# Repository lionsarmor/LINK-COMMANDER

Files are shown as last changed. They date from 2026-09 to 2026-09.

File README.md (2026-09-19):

# LINK COMMANDER — Rev D

**Buy the breadboard parts:** [Amazon checklist + ASINs](SHOPPING-AMAZON.md) · [Mouser checklist + SKUs](SHOPPING-MOUSER.md) · [Amazon order CSV](SHOPPING-AMAZON-ORDER.csv) · [Full Mouser CSV](SHOPPING-MOUSER-ORDER.csv) · [Keyboard-only Mouser CSV](SHOPPING-MOUSER-KEYBOARD.csv). Choose one checklist; do not buy both. Each covers the build and explicitly identifies outside-store exceptions. Skip parts already owned.

**Five finished PCB builds:** [Full Mouser PO (PDF)](MOUSER-PO-01-FIVE-PCBS.pdf) · [Full PO CSV](MOUSER-PO-01-FIVE-PCBS.csv) · [Chips-only PO (PDF)](MOUSER-PO-02-CHIPS-ONLY.pdf) · [Chips-only CSV](MOUSER-PO-02-CHIPS-ONLY.csv). Plain supplier parts tables; not submitted. Full order needs five modules and five fabricated PCBs supplied separately.

A through-hole USB keyboard and mouse adapter for the **Commander X16**.
The RP2040-Zero translates supported wired devices or 2.4 GHz USB receivers
into PS/2 keyboard and mouse signals. Rev D removes all gamepad support.

**Two USB inputs. Two PCB-mounted 7-pin DIN outputs. Two socketed DIP chips.**
The RP2040-Zero plugs into removable headers; every other carrier part is
through-hole. No USB hub or onboard radio is required.

A separate regulated **5 V / 2 A supply** powers the module and USB ports.
The X16 PS/2 +5 V lines supply only their signal pull-ups.

**Start breadboarding:** [Wiring instructions and parts list](BREADBOARD.md) ·
[Parts CSV](BREADBOARD-PARTS.csv) · [Complete wiring CSV](BREADBOARD-WIRING.csv)

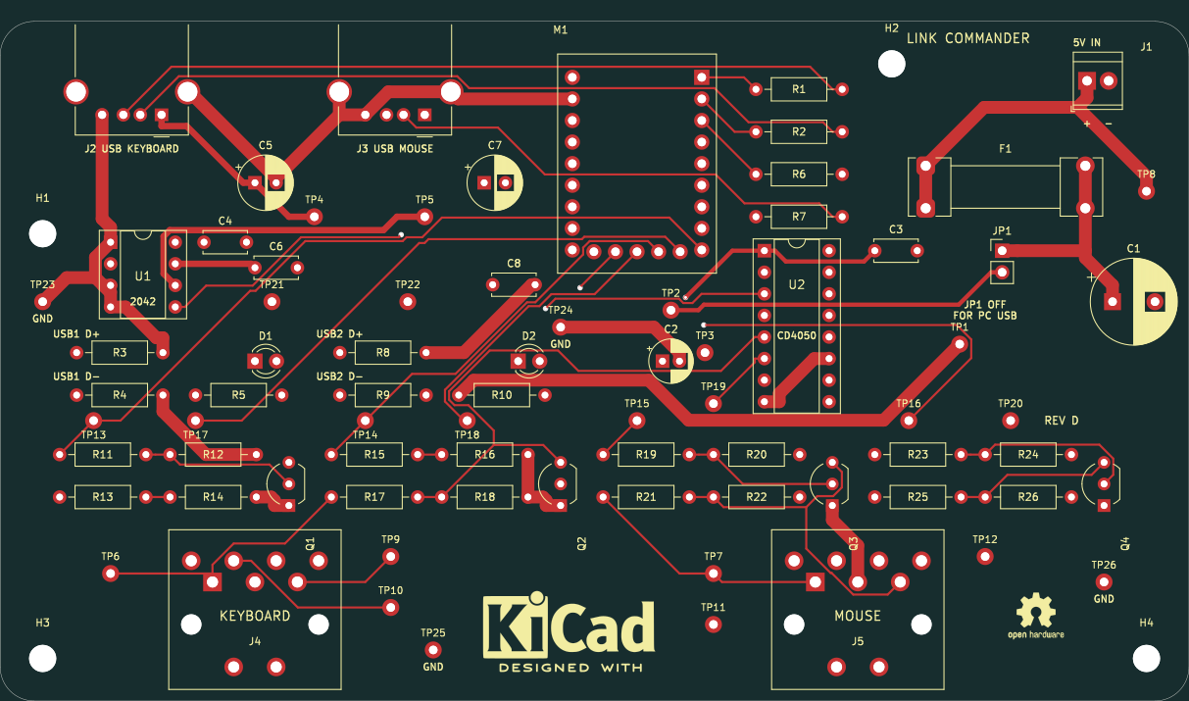
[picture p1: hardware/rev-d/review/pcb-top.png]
Rev D PCB preview


- [Exploratory PS/2 simulation and its limits](hardware/rev-d/simulation/README.md)
- [Test points and expected readings](hardware/rev-d/test-points.md)
- [Student guide: how it works](hardware/rev-d/student-guide.md)
- [One-page schematic PDF](hardware/rev-d/review/schematic.pdf)
- [Assembly PDF](hardware/rev-d/review/assembly.pdf)
- [Editable KiCad project](hardware/rev-d/kicad/link-commander.kicad_pro)
- [Complete Rev D review ZIP](hardware/link-commander-rev-d-review.zip)
- [Breadboard guide and custom cables](BREADBOARD.md)
- [Pin-by-pin wiring table](hardware/rev-d/breadboard-wiring.csv)
- [Grouped BOM](hardware/rev-d/bom-grouped.csv) and [purchasing notes](hardware/rev-d/parts.md)
- [Design details and validation status](hardware/rev-d/README.md)
- [Firmware requirements](hardware/rev-d/firmware-contract.md)

The rounded **140 × 80 mm, two-layer PCB** retains 50 electrical parts
and four mounting holes, and now adds **26 labeled through-hole test pads**.
The student schematic shows seven circuit sections plus a test-point section,
physical pin numbers and connected wires.

**Engineering prototype:** CAD checks pass, but firmware, physical fit,
receiver compatibility and electrical operation still require testing.
No working bridge firmware or fabrication release is included yet. Start
with the standalone keyboard breadboard before connecting the X16.

Rev D uses **non-inverted PS/2 sense signals** and new component reference
numbers. Use only its wiring tables. Remove JP1 before connecting the
module's USB-C to a computer.

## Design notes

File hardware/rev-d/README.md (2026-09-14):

# LINK COMMANDER — Rev D

Rev D translates supported **USB keyboards and mice** into the PS/2
keyboard and mouse interfaces used by the Commander X16. Wired peripherals
and manufacturers' 2.4 GHz USB receivers use the same two USB input ports.
Gamepad support has been removed from this revision.

The RP2040-Zero plugs into removable headers. Every other carrier component
is through-hole. There are **two socketed DIP chips and four transistors**.
The board is **140 × 80 mm**, has **two copper layers** and 4 mm corner radii,
and retains the KiCad/open-hardware logos.

The board and USB receivers use a separate regulated **5 V / 2 A supply**.
The X16 PS/2 +5 V pins supply only their signal pull-ups; they do not power
the RP2040 or USB ports. All grounds are shared.

## Start here

- [Exploratory PS/2 simulation and its limits](simulation/README.md)
- [Test-point map and expected readings](test-points.md) and [probe CSV](test-points.csv)
- [Student design guide: how the circuit works](student-guide.md)
- [One-page schematic PDF](review/schematic.pdf)
- [Assembly PDF](review/assembly.pdf) and [PCB preview](review/pcb-top.png)
- [Editable KiCad project](kicad/link-commander.kicad_pro)
- [Breadboard guide and custom cable table](breadboard.md)
- [Every physical pin](breadboard-wiring.csv) and [connections grouped by net](net-connections.csv)
- [Grouped BOM](bom-grouped.csv), [individual BOM](bom.csv), [purchasing notes](parts.md)
- [Firmware interface and test requirements](firmware-contract.md)
- [Validation reports](review/design-checks.txt), [PCB DRC](review/pcb-drc.txt)
- [Rebuild instructions](tools/README.md)

## What changed from Rev C

| | Rev C | Rev D |
|---|---:|---:|
| USB inputs | 4 | 2: keyboard and mouse |
| DIN outputs | 4 | 2: PS/2 keyboard and mouse |
| Socketed DIP ICs | 17 | 2 |
| Transistors | 7 | 4 |
| Circuit parts plus mounting holes | 143 | 54 |
| Additional bare test holes | — | 26 |
| Board | 230 × 130 mm, four layers | 140 × 80 mm, two layers |

The gamepad shift registers, resistor networks and control gates are gone.
One TPS2042P replaces the two individual USB power chips. One CD4050 handles all four PS/2 sense lines. The separate HC14 inverter
stage and four input/output series-resistor pairs have been removed. Both
channels of the USB power chip are enabled directly by ground, so no shared enable
transistor or RUN_ENABLE GPIO is required. Port fault LEDs remain useful
for students during bring-up.

**Rev D sense signals are non-inverting:** HIGH means the cable line is
HIGH. The old Rev C firmware assumptions and component reference numbers
must not be reused without updating them. PS/2 drive HIGH still pulls LOW.

The DIN-to-PS/2 cable signal assignment is unchanged, but the output
connectors are now J4 and J5. Use the Rev D wiring tables exclusively.

## Test access

TP1–TP26 add 26 bare plated holes: eight power rails, twelve PS/2
drive/cable/sense nodes, two USB fault outputs and four grounds. The board
now has 80 CAD positions: 50 electrical parts, four mounting holes and
26 optional test contacts. It still needs only two socketed chips.
USB data probing uses existing resistor pads to avoid added test branches.

## Prototype status

The saved PCB passes KiCad clearance/connectivity checks, and the exported
schematic netlist matches the canonical circuit. All populated component
pads are through-hole. These are CAD checks, not evidence of a working
physical adapter: module/socket fit, USB signal integrity, power sequencing,
PS/2 timing, firmware and receiver compatibility still need bench testing.
The two-layer ground pour is interrupted by routes; it is not a dedicated
unbroken reference plane or a controlled-impedance qualification.

No working bridge firmware or fabrication release is supplied here. Start
with the standalone breadboard tests. Do not connect the X16 until the
firmware and cable checks in the guide have passed.

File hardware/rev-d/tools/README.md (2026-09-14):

# Rebuilding and checking Rev D

`circuit.json` is the component/pin/net source. `design.py` loads it.
The schematic embeds its symbols and the PCB uses the supplied local
footprint library. The editable files can be opened directly in KiCad.

`python3 tools/build.py` redraws the single-page schematic and regenerates
the BOM/wiring tables, including the root `BREADBOARD-PARTS.csv`,
`BREADBOARD-WIRING.csv` and the generated parts table inside `BREADBOARD.md`.
The root wiring CSV is the full two-port circuit; keyboard-only temporary
connections are described in the root guide. It preserves the routed PCB. After schematic changes,
export a fresh XML netlist with KiCad and run `python3 tools/check_design.py`.
That check compares actual exported nets with the source, and separately
checks the two-port PS/2 interface, non-inverted sense signals, USB power
switch enables, unused pins and supply separation.

Scripts that import `pcbnew` use `tools/run-kicad-python`. Its default
KiCad installation path is specific to the development machine; set
`LC_KICAD_ROOT` to your extracted KiCad root or run the scripts with your
own matching KiCad Python environment. CAD was generated and checked with
KiCad 7.0.11. The native files do not require this wrapper to open in KiCad.

## Rebuilding the PCB replaces its routing

1. `layout.py` creates the unrouted 140 × 80 mm, two-layer board and restores
   project net classes from `project-template.json`. It copies the two
   standard logo footprints from the installed KiCad library.
2. `prepare_route.py` writes the placement DRC and exports the Specctra DSN
   with explicit routing settings. The supplied DSN uses two signal layers.
3. Route with Freerouting 1.9 using one worker thread. Use the project's
   trace widths and clearances; do not relax them to get a completed route.
4. `finish_board.py` imports the complete SES into an **unrouted** board and
   adds/fills the B.Cu ground pour. Its limited importer checks units,
   layer names and via size. The supplied session contains the complete route.
5. `check_board.py` verifies the saved board's populated pad nets, through-hole
   pad types, two-layer stack, ground pour and complete DRC result.
6. `export_review.py` regenerates layer plots without changing the PCB.
   Use KiCad CLI exports for the PDF, cropped SVG and assembly views.

The checks are file/connectivity checks, not a full electrical simulation,
standard-symbol ERC, USB impedance verification or proof of X16 operation.
Keep those distinctions in any regenerated validation report.

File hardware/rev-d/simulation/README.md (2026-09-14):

# Rev D exploratory simulation

**Simulation supports the intended PS/2 switching behavior under the listed
assumptions. It does not establish that the complete adapter works or is
ready to order.** The physical circuit and firmware pin assignments have
not changed as a result of this study.

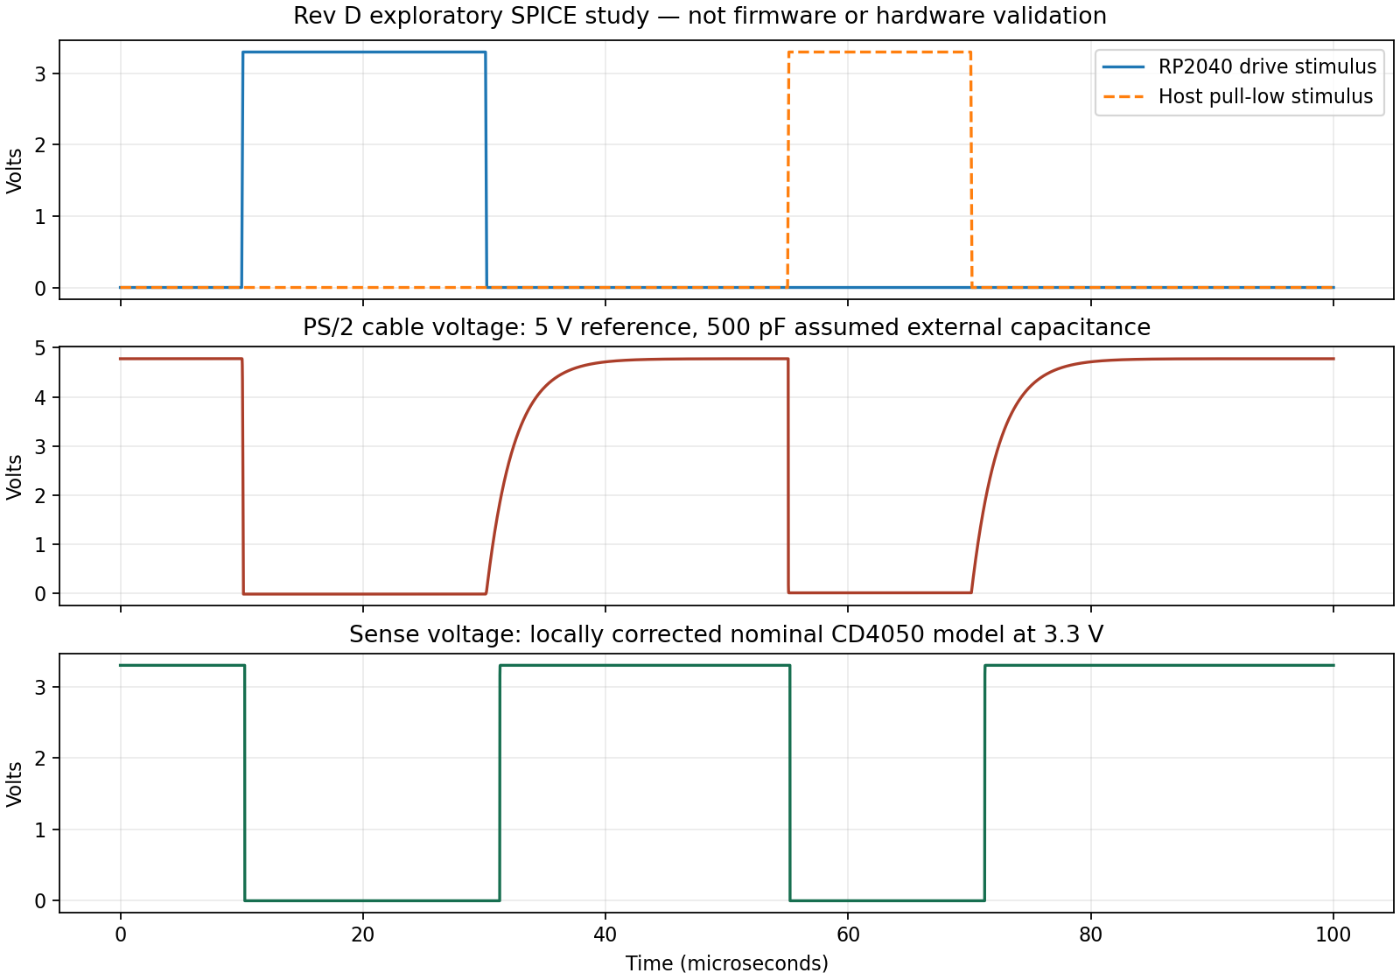
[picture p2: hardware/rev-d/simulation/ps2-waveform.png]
Nominal keyboard DATA waveform


## What was run

ngspice 42 ran the four PS/2 drive/sense circuits using resistor values and
pin assignments checked against `../circuit.json`. Each circuit was tested
with three paired supply settings and three assumed external capacitances:

- Target reference / module logic supply: 4.75 / 3.135 V, 5.0 / 3.3 V,
  and 5.25 / 3.465 V. These are three scenarios, not all independent corners.
- External cable/connector/probe capacitance: 100, 500 and 1000 pF.
- Temperature: 25°C. Resistors use nominal values, without tolerance sweeps.
- GPIO drive is a voltage stimulus with an assumed 30 Ω source resistance.
- Host inhibit is an ideal low-side switch with 10 Ω on resistance.
  No X16 host pull-up or motherboard model is included.
- A locally adapted CD4050 behavioral model drives an assumed 10 pF GPIO load.

The test asserts the adapter transistor, releases it, and then makes the
host pull the line LOW while the adapter releases it. It is not a PS/2
packet generator, USB transaction test, or firmware execution environment.
The four channels share the same topology, so their numerical results
repeat; the channel checks verify their resistor and pin mappings too.

## Results and their meaning

All **36 exploratory cases** met the stated static voltage checks:
released cable above 4 V, asserted cable between −0.05 and 0.4 V, and
sense output close to the modeled 3.3 V-domain rails.

| Quantity | Result under the modeled assumptions |
|---|---|
| Lowest released cable HIGH | 4.537 V |
| Highest host-held LOW | 0.011 V |
| GPIO drive current | 1.108–1.254 mA |
| Cable 10–90% release rise time | 1.054–9.931 µs |
| Nominal 5 V / 500 pF release rise time | 4.999 µs |

The model predicts a **small negative transistor-driven LOW**, approximately
−14 to −15 mV. Treat that as a model limitation, not a physical voltage
prediction or a guaranteed saturation voltage. The deliberately broad LOW
check catches gross logic failures; it does not validate the model itself.

Higher assumed cable capacitance makes the released line rise more slowly.
Actual cable capacitance, host pull-ups and firmware sampling times must
be measured together before concluding that PS/2 timing is satisfactory.
The rise times above are measurements of the simulated cable node, not
guaranteed propagation times for the CD4050.

[Summary](summary.txt), [complete results CSV](results.csv),
[results and provenance JSON](results.json), and [nominal waveform data](waveform.txt)
are provided for review.

## Model provenance and corrections

The script downloads manufacturer models into a local cache and verifies
their SHA-256 hashes. The model libraries are not redistributed here.

- [onsemi 2N3904 model](https://www.onsemi.com/pub/Collateral/2N3904.LIB):
  used unchanged. It is a nominal model for that manufacturer's device,
  not a qualification of every transistor sold as 2N3904.
- [TI CD4050B model package](https://www.ti.com/lit/zip/schm018): the
  downloaded model incorrectly selects NAND behavior. TI acknowledges
  this error in its [support response](https://e2e.ti.com/support/logic-group/logic/f/logic-forum/1015038/cd4050b-issue-with-cd4050b-spice-model).
  The support attachment could not be downloaded in this environment.
  Our script makes an explicit **local** correction (`AND=1`, `NAND=0`)
  consistent with the [non-inverting datasheet function](https://www.ti.com/lit/ds/symlink/cd4050b.pdf).
  It also renames the model's `VT` parameter to avoid collision with
  ngspice's built-in thermal-voltage value. These are not claimed to be
  TI's own corrected attachment or a TI-validated ngspice model.

The script separately sanity-checks LOW and HIGH outputs after adapting the
model. This is necessary but insufficient to validate its analog accuracy.
The TI model's timing/output-resistance tables begin at 5 V; applying it
at 3.3 V does not qualify CD4050 timing, drive strength, temperature behavior,
or power consumption. Do not use it to approve power-off input tolerance.

## Reproduce

Use Python 3, NumPy, Matplotlib and ngspice with XSPICE/PSpice compatibility.
The first run downloads the two models; later runs verify the cached files.

```sh
python3 hardware/rev-d/simulation/run.py --ngspice ngspice
```

For a privately extracted ngspice installation, pass its executable with
`--ngspice` and its directory of `.cm` files with `--code-model-dir`.
`--cache` selects where manufacturer libraries are downloaded. The script
only changes the simulation outputs; it does not regenerate or edit CAD.

[ps2-example.cir](ps2-example.cir) is a portable nominal example. For manual
use, place the cached `2N3904.lib` and locally corrected `CD4050B-local.lib`
in a `models/` directory beside it and enable ngspice PSpice compatibility.
The full script handles those paths and the compatibility setting for you.

## What is still required before a PCB order

1. Implement and test USB enumeration and HID reports from the actual
   keyboard and mouse receivers, first separately and then simultaneously.
2. Implement PS/2 device firmware and test its host-command handling,
   acknowledgments, framing, clock inhibit and keyboard/mouse translation.
3. Breadboard the drive/sense interfaces and measure the actual voltages,
   signal edges and reset behavior using [the test-point map](../test-points.md).
4. Verify external power, receiver startup load and all PC USB/X16 power
   combinations. TPS2042 protection, regulator startup and backfeeding were
   **not simulated**. Do not substitute a TPS2042B model and assume it
   validates the TPS2042P fitted to this board.
5. Check the actual module and DIN sockets against a 1:1 print, then confirm
   USB signal integrity and operation with the intended X16 board/ROM.

Existing CAD clearance/connectivity reports remain useful, but they are
separate from this study. No extracted PCB parasitics, USB receiver model,
RP2040 firmware model or complete Commander X16 model was simulated.

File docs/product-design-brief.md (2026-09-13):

# LINK COMMANDER product brief — Rev D

## Goal

Let a Commander X16 use a supported modern USB keyboard and mouse,
including devices with their own 2.4 GHz USB receivers, through the X16's
PS/2 keyboard and mouse ports. Keep the design straightforward to explain,
breadboard and solder in a student setting.

## Active scope

- Two independent USB-A host inputs, assigned to keyboard and mouse.
- Two directly mounted 7-pin DIN outputs and custom PS/2 cables.
- User's RP2040-Zero module on removable perimeter-header sockets.
- All other carrier components through-hole; socketed DIP ICs.
- No USB hub, onboard radio, Bluetooth or gamepad support.
- Extensible HID keyboard/mouse parsing; receiver compatibility must be tested.
- One-page student schematic with functional sections and actual wires.
- Rounded, elongated board with KiCad/open-hardware silkscreen graphics.

## Rev D implementation

One TPS2042P DIP-8 dual switch protects both receiver supplies. One CD4050BE
DIP-16 reads four PS/2 lines at 3.3 V. Four 2N3904 transistors provide
low-only DATA/CLOCK drive. The RP2040 runs USB host and PS/2 device firmware.
The supply-switch enables are grounded; receiver power is always on when
external 5 V is present. There is no RUN_ENABLE signal.

The 140 × 80 mm, two-layer PCB has 80 CAD positions: 50 electrical parts, four
mounting holes and 26 bare test contacts. USB data uses existing resistor
pads for probing; power and PS/2 signals have dedicated test holes. Both DIN target +5 V reference nets remain separate from
board power. JP1 is a manual programming-power interlock.

## Delivery and limits

Current CAD, BOM, student guide, breadboard tables, cable pinout, firmware
contract and validation reports are in [hardware/rev-d](../hardware/rev-d/README.md).
The schematic netlist and saved board are checked against the same canonical
pin assignments. DRC does not prove USB signal integrity or actual X16
operation. Firmware, receiver tests, physical footprint fit, power sequencing
and PS/2 timing remain bench acceptance work.

Earlier four-port/gamepad designs are historical and are not Rev D build
instructions. The current GitHub design is keyboard/mouse only.

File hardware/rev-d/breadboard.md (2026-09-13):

# Rev D breadboard and custom PS/2 cables

Use this guide with the **Rev D** schematic and wiring CSV. Component
numbers and the sense polarity differ from Rev C. Begin with a keyboard
receiver on USB input 1; add the mouse after the keyboard tests pass.

## Parts for the first keyboard build

Populate M1, J1, F1, JP1, C1-C6, U1, U2, J2, D1, R1-R5, Q1/Q2,
R11-R18, and the keyboard output J4. Leave the mouse port and mouse output
parts out initially. Tie the unused U2 inputs 7, 9, 11 and 14 to ground in
this keyboard-only breadboard. Leave outputs 6, 10, 12 and 15 open. When
adding the mouse, remove the temporary grounds from U2 pins 7 and 9 and
connect them to MOUSE_DATA and MOUSE_CLOCK instead.

The RP2040-Zero needs two 1×9 side headers and one 1×5 end header. Its end
row does not share the same grid alignment as the side rows on a normal
breadboard; use short leads for the end contacts. Use the printed GP labels.
Do not solder wires to underside GPIO pads.

USB and DIN sockets may need short soldered leads or your existing connector
breakouts during breadboarding. The finished PCB takes the sockets directly.
Keep USB data leads short and paired, with the 22 Ω resistors beside the
module. Do not carry the combined receiver load through long breadboard rails.

## Test access

The finished PCB provides TP1–TP26. On the breadboard, clip to the same
named nets; the test holes themselves do not need separate components.
Use the [test-point guide](test-points.md) for the power checks, PS/2
drive/sense comparisons, voltage domains and USB resistor probe pads.
The external supply and JP1 procedure are unchanged.

## Module wiring

| Module GPIO | M1 carrier pin | Connection |
|---|---:|---|
| GP0 | 1 | R1.1 → 22 Ω → keyboard USB D+ |
| GP1 | 2 | R2.1 → 22 Ω → keyboard USB D− |
| GP2 | 3 | R6.1 → 22 Ω → mouse USB D+ |
| GP3 | 4 | R7.1 → 22 Ω → mouse USB D− |
| GP8 | 9 | R11.1 → keyboard DATA transistor base |
| GP9 | 10 | U2.2 → keyboard DATA sense |
| GP10 | 11 | R15.1 → keyboard CLOCK transistor base |
| GP11 | 12 | U2.4 → keyboard CLOCK sense |
| GP12 | 13 | R19.1 → mouse DATA transistor base |
| GP13 | 14 | U2.6 → mouse DATA sense |
| GP14 | 15 | R23.1 → mouse CLOCK transistor base |
| GP15 | 16 | U2.10 → mouse CLOCK sense |
| 3V3 | 21 | U2.1, C2.1, C3.1 |
| GND | 22 | Common ground |
| 5V | 23 | JP1.2, net 5V_MODULE |

GP4-GP7 and GP26-GP29 are unused. GP16 remains the module's onboard LED.
Drive HIGH asserts LOW. Sense HIGH means the cable is HIGH.

## Power and chip connections

J1.1 goes to F1.1. F1.2 supplies 5V_BOARD; J1.2 is GND. C1's positive
lead goes to 5V_BOARD. JP1.1 is 5V_BOARD; JP1.2 is 5V_MODULE.
Use a regulated 5 V / 2 A supply and a 1.5 A fast 5×20 fuse. Verify
4.75-5.25 V at each USB socket under the intended load; supply and wiring
losses matter. Do not exceed 5.25 V at J1.

U1 is a **TPS2042P dual power switch**. Pin 2 is 5V_BOARD; pins 1, 3 and
4 are GND. Pin 7 supplies keyboard USB VBUS, and pin 6 supplies mouse USB
VBUS. Pin 8 is the keyboard fault output; pin 5 is the mouse fault output.
Each red LED's cathode goes to its fault output; its anode is fed from
5V_BOARD through 2.2 kΩ. A TPS2041P has a different pinout and must not be
substituted. TPS2052 has the opposite enable polarity.

U2: pin 1 is 3V3; pin 8 is GND. Do not use the usual “pin 16 is power”
assumption: **U2 pins 13 and 16 are no-connects**. In the complete design,
pins 11/14 are grounded and outputs 12/15 stay open.

Place each 100 nF capacitor near the corresponding IC or USB supply pins.
Electrolytic pin 1 is positive. DIP numbering is viewed from above, notch
at the top: pin 1 is upper left, then count down the left and up the right.
For the selected 2N3904, verify manufacturer pins **1=E, 2=B, 3=C**.

## PS/2 signal circuits

| Line | Base resistor | Base pulldown | Target pullup | Line pulldown | Transistor | U2 input → output |
|---|---|---|---|---|---|---|
| Keyboard DATA | R11 2.2 kΩ | R12 47 kΩ | R13 4.7 kΩ | R14 100 kΩ | Q1 | 3 → 2 |
| Keyboard CLOCK | R15 2.2 kΩ | R16 47 kΩ | R17 4.7 kΩ | R18 100 kΩ | Q2 | 5 → 4 |
| Mouse DATA | R19 2.2 kΩ | R20 47 kΩ | R21 4.7 kΩ | R22 100 kΩ | Q3 | 7 → 6 |
| Mouse CLOCK | R23 2.2 kΩ | R24 47 kΩ | R25 4.7 kΩ | R26 100 kΩ | Q4 | 9 → 10 |

Each emitter goes to GND. Its collector goes directly to the named cable
line. The 2.2 kΩ resistor connects the drive GPIO to its base; 47 kΩ connects
base to ground. The 4.7 kΩ resistor connects that line to the corresponding
X16-side 5 V reference. The 100 kΩ resistor connects the line to ground.

For every physical connection, use [breadboard-wiring.csv](breadboard-wiring.csv)
or [net-connections.csv](net-connections.csv). Do not infer connections from
where components happen to sit on a breadboard or on the PCB.

## Custom cables: same assignment for J4 and J5

J4 connects only to the X16 keyboard port; J5 connects only to its mouse port.
Use a 7-pin DIN male plug on the adapter end and a 6-pin mini-DIN PS/2 male
plug on the X16 end. Numbers below refer to the actual numbered contacts,
not left-to-right positions or wire colors.

| Adapter 7-pin DIN contact | PS/2 plug contact | Signal |
|---:|---:|---|
| 1 | 4 | X16 +5 V reference |
| 2 | 3 | Ground |
| 3 | 1 | DATA |
| 4 | 5 | CLOCK |
| 5, 6, 7 | None | Leave unconnected |
| Shell / local PCB pad 8 | None | Leave unconnected |

PS/2 contacts 2 and 6 remain unconnected. The two physical shell terminals
on the DIN footprint share local pad number 8; neither is a signal contact.
Front and solder-side views are mirrored. Confirm numbering against the
connector drawing and then continuity-test every wire before use. The
[X16 hardware reference](https://github.com/X16Community/x16-docs/blob/master/X16%20Reference%20-%2014%20-%20Hardware.md)
provides the target PS/2 pin assignment.

## Bring-up sequence

1. Leave the X16 and USB receivers disconnected. Check supply continuity,
   capacitor polarity, DIP orientation and transistor pinouts without power.
2. Apply external 5 V with a current-limited bench supply. Confirm 3V3 at
   U2.1 and receiver VBUS on J2.1/J3.1. Both USB ports are always enabled.
3. For PC programming, remove JP1 first. With JP1 removed, the PC powers
   the module and U2 while external 5 V powers the receiver sockets.
   For standalone use, disconnect PC USB and refit JP1 with power off.
4. With the X16 absent, a temporary regulated 5 V reference can supply
   KBD_5V/MOUSE_5V on the test fixture. Use GPIO test firmware to verify all
   four drive/sense paths. Remove those temporary reference jumpers before
   connecting any X16 cable. Measure rise time and check that sense inputs
   stay in the 3.3 V domain.
5. Test USB enumeration and reports, then PS/2 reset, acknowledgments,
   keyboard scan-code behavior and mouse packets on a suitable host fixture.
   The firmware requirements are in [firmware-contract.md](firmware-contract.md).
6. Only after these checks pass, power off, attach the checked custom cables,
   and begin an X16 keyboard test. Add mouse operation and simultaneous use
   afterward. Record receiver models and results.

These are required tests, not completed test results. This repository does
not yet include a tested bridge or GPIO test application.

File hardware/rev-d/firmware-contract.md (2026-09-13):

# Rev D firmware interface and acceptance tests

No working bridge firmware is included yet. This file specifies what the
next implementation must do; it is not a claim that two-port USB or PS/2
behavior has been tested.

Test access is documented in [test-points.md](test-points.md); the new
probe contacts do not change the firmware pin assignments or polarity.

## Hardware interface

| GPIO | Function |
|---|---|
| GP0 / GP1 | Keyboard USB D+ / D− |
| GP2 / GP3 | Mouse USB D+ / D− |
| GP8 / GP9 | Keyboard DATA drive / non-inverted sense |
| GP10 / GP11 | Keyboard CLOCK drive / non-inverted sense |
| GP12 / GP13 | Mouse DATA drive / non-inverted sense |
| GP14 / GP15 | Mouse CLOCK drive / non-inverted sense |

Unused: GP4-7 and GP26-29. GP16 is the module's onboard LED. There is no
RUN_ENABLE or gamepad shift-register interface. U1 /EN1 and /EN2 are grounded.
Receiver VBUS is present whenever external power is applied; resetting the
RP2040 does not power-cycle the receivers.

Set all four drive output latches LOW before enabling them as outputs.
Enable the four sense inputs and GPIO hysteresis, with internal pulls off.
A HIGH drive pulls its PS/2 line LOW; a LOW drive releases it. A HIGH sense
means the cable line is HIGH. This reverses Rev C's sense interpretation.
Do not drive a PS/2 line HIGH electrically: only Q1-Q4 pull LOW.

## USB host

Use a deliberate two-root-port configuration with the port pair assignments
above. Configure and test both ports; wiring two GPIO pairs does not by
itself implement a USB host. The module's native USB-C remains available
for programming/debugging with JP1 removed.

[Pico-PIO-USB](https://github.com/sekigon-gonnoc/Pico-PIO-USB) is the proposed
host backend. Pin a tested commit and document its supported system clock,
PIO/state-machine allocation and timing requirements. Use its supported
low/full-speed host configuration; this design is not a high-speed USB host.
Make sure the external 15 kΩ data pulldowns are not unintentionally doubled
by internal GPIO pulldowns left enabled by the host configuration.

Start with ordinary USB HID keyboards and mice. Parse report descriptors
and report IDs for composite receivers; do not assume every receiver sends
only the simplest boot report. Maintain key-release state, modifier state,
mouse movement and button state. Test disconnect/reconnect, simultaneous
traffic and unsupported-device handling. There is no gamepad/XInput driver
in the Rev D scope.

## PS/2 device behavior

The adapter emulates a keyboard and a mouse toward the X16. Implement
separate device state machines and queues, including clock generation,
start/data/odd-parity/stop framing, host clock inhibit, host request-to-send,
acknowledgments and command response timing. Read the real sense inputs
while driving so the host can inhibit or take control of the bus.

For the keyboard, implement the X16-compatible scan-code behavior, including
make/break codes, modifiers, extended keys, reset/self-test, identification,
scan enable/disable, LEDs, typematic commands and the relevant scan-set
commands. Translation must follow the USB HID usage meaning, not the
numerical USB usage byte as a PS/2 scan code.

For the mouse, implement reset/self-test, identification, enable/disable,
stream/remote behavior, read-data, sample-rate/resolution/scaling commands
as required by the host, and correctly signed movement/button packets.
Begin with a basic PS/2 mouse identity and packet format; negotiate and
implement any extensions before advertising them. Verify the exact X16
firmware's initialization sequence on the test fixture.

## Acceptance gates

1. **GPIO fixture:** verify drive/sense polarity, low levels, released high
   levels, line rise time, and power-on/off combinations on all four lines.
2. **USB only:** print decoded keyboard and mouse reports while exercising
   both ports; include wired devices and the selected wireless receivers.
3. **PS/2 fixture:** test reset, ACK/resend behavior, parity, host inhibit,
   host commands, keyboard releases and signed mouse motion/overflow.
4. **Combined fixture:** sustain keyboard repeats and mouse motion together;
   verify USB scheduling does not break PS/2 timing or lose releases.
5. **X16:** after cable continuity and electrical checks, test keyboard first,
   then mouse, then both. Record board/ROM versions, receiver IDs and results.

Receiver compatibility remains a tested list. “2.4 GHz” describes the radio
link, not a guarantee of a particular USB HID interface.

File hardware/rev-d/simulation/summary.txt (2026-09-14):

36 / 36 exploratory cases met the stated static voltage checks.
Highest simulated driven cable LOW (model artifact; see README): -0.0139 V
Min released cable HIGH: 4.5367 V
Max host-held cable LOW: 0.0111 V
GPIO drive current range: 1.108–1.254 mA
Cable 10–90% release rise time: 1.054–9.931 microseconds
Scope: four channels; three paired supplies; 100/500/1000 pF external capacitance; 25 C; nominal resistors.
No USB host, firmware, power startup/sequencing, chip temperature corners, PCB parasitic extraction or actual X16 simulation.
Model caveat: the 2N3904 model predicts a small negative driven LOW (~-14 to -15 mV); this is not a validated physical voltage.
CD4050 is a locally corrected behavioral model; its 3.3 V timing/drive strength is not qualified by this study.

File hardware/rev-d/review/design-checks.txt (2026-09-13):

PASS: 80 components including mounting holes; 37 named nets; 189 physical pin assignments.
PASS: 26 through-hole test contacts cover power, PS/2, USB faults and four ground locations.
PASS: exported schematic netlist exactly matches the canonical circuit.
PASS: only two USB inputs, two PS/2 DIN outputs; no gamepad circuitry or nets.
PASS: two DIP chips; header-only RP2040 with 12 used GPIOs and 8 unused GPIOs.
PASS: dual TPS2042P outputs/faults and both active-low enables are correct.
PASS: four USB 22-ohm series paths and four 15-kilohm host pulldowns.
PASS: four low-only transistor outputs and four non-inverting CD4050 sense paths.
PASS: CD4050 supply/unused pins and target-reference power separation.
NOT TESTED: physical fit, electrical timing/thresholds, USB signal integrity,
firmware operation, USB receiver compatibility, or actual X16 operation.
This is a netlist/structural check, not an electrical simulation or full ERC.

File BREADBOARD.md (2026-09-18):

# LINK COMMANDER Rev D — breadboard wiring and parts

**Buy the breadboard parts:** [Amazon checklist + ASINs](SHOPPING-AMAZON.md) · [Mouser checklist + SKUs](SHOPPING-MOUSER.md) · [Amazon order CSV](SHOPPING-AMAZON-ORDER.csv) · [Full Mouser CSV](SHOPPING-MOUSER-ORDER.csv) · [Keyboard-only Mouser CSV](SHOPPING-MOUSER-KEYBOARD.csv). Choose one checklist; do not buy both. Each covers the build and explicitly identifies outside-store exceptions. Skip parts already owned.

**Build the keyboard half first, then add the mouse.** This guide is for
Rev D: RP2040-Zero module, two USB inputs, two 7-pin DIN outputs, and an
external regulated 5 V supply. It does not include gamepad circuitry.

The parts list is included below and attached as
[BREADBOARD-PARTS.csv](BREADBOARD-PARTS.csv). The complete Rev D connection
list is [BREADBOARD-WIRING.csv](BREADBOARD-WIRING.csv). Open the
[one-page schematic](hardware/rev-d/review/schematic.pdf) alongside this guide.

**Firmware is still required.** Wiring the board alone will not translate
USB into PS/2. Leave the X16 disconnected until the standalone electrical
and firmware tests below have passed.

## 1. Gather the parts

“Keyboard first” is the starting quantity. “Add mouse” is the extra quantity,
not a replacement. All parts except the assembled RP2040-Zero module are
through-hole. The following table covers the 50 electrical positions in
the full circuit; tools, leads and cable parts are listed afterward.

<!-- BEGIN GENERATED BREADBOARD PARTS -->
| Keyboard first | Add mouse | Full total | Part / value | References |
|---:|---:|---:|---|---|
| 1 | 0 | 1 | Two-contact 5 V power connection | J1 |
| 1 | 0 | 1 | 1.5 A fast fuse, 5×20 mm | F1 |
| 1 | 0 | 1 | Removable module-power jumper | JP1 |
| 1 | 0 | 1 | RP2040-Zero module on headers | M1 |
| 1 | 0 | 1 | 470 µF / 10 V electrolytic capacitor | C1 |
| 1 | 0 | 1 | 10 µF / 10 V electrolytic capacitor | C2 |
| 3 | 1 | 4 | 100 nF leaded ceramic capacitor | C3 C4 C6 C8 |
| 1 | 0 | 1 | USB-A receptacle, keyboard | J2 |
| 1 | 0 | 1 | TPS2042P dual power switch, DIP-8 | U1 |
| 2 | 2 | 4 | 22 Ω resistor | R1 R2 R6 R7 |
| 2 | 2 | 4 | 15 kΩ resistor | R3 R4 R8 R9 |
| 3 | 3 | 6 | 2.2 kΩ resistor | R5 R10 R11 R15 R19 R23 |
| 1 | 1 | 2 | 220 µF / 10 V electrolytic capacitor | C5 C7 |
| 1 | 1 | 2 | Red LED, 3 mm | D1 D2 |
| 0 | 1 | 1 | USB-A receptacle, mouse | J3 |
| 1 | 0 | 1 | 7-pin DIN socket, keyboard (SDS-70J for PCB) | J4 |
| 0 | 1 | 1 | 7-pin DIN socket, mouse (SDS-70J for PCB) | J5 |
| 2 | 2 | 4 | 2N3904 transistor, TO-92 | Q1 Q2 Q3 Q4 |
| 2 | 2 | 4 | 47 kΩ resistor | R12 R16 R20 R24 |
| 2 | 2 | 4 | 4.7 kΩ resistor | R13 R17 R21 R25 |
| 2 | 2 | 4 | 100 kΩ resistor | R14 R18 R22 R26 |
| 1 | 0 | 1 | CD4050BE buffer, DIP-16 | U2 |
<!-- END GENERATED BREADBOARD PARTS -->

For a breadboard, J1 can be an insulated supply connection and F1 can use
an inline 5×20 fuse holder. JP1 can be a clearly labeled removable jumper
wire. These serve the same connections as their PCB counterparts.

Also gather:

| Item | Keyboard first | Add mouse | Notes |
|---|---:|---:|---|
| Regulated 5 V / 2 A supply | 1 | 0 | A current-limited bench supply is useful for first power-up |
| 5×20 fuse holder | 1 | 0 | For F1; not an unfused wire link |
| Solderless breadboard | 1 large board to start | As needed | Use another board if the USB/PS/2 wiring becomes crowded |
| Solid-core jumper wire and short hookup leads | Assortment | As needed | Check continuity across split breadboard rails |
| Module male headers, 2.54 mm | Two 1×9 and one 1×5 | 0 | Only if your module does not already have them fitted |
| 7-pin DIN male cable plug | 1 | 1 | Matches your output socket |
| 6-pin mini-DIN PS/2 male cable or plug | 1 | 1 | Four conductors used; continuity-test the numbered contacts |
| Insulated cable, heat-shrink and strain relief | 1 cable's worth | 1 cable's worth | Or adapt a checked PS/2 cable |
| USB receiver and its paired peripheral | Keyboard set | Mouse set | Or a wired USB keyboard/mouse for initial firmware testing |
| USB-C data cable to the computer | 1 | 0 | For programming the module; remove JP1 first |
| Multimeter | 1 | 0 | Power and cable continuity checks |
| Suitable logic analyzer; preferably an oscilloscope too | 1 setup | 0 | Logic timing and signal-edge tests |

Your existing USB and DIN connector breakouts can hold the sockets during
breadboarding; they contain no extra controller chips. Alternatively,
solder short insulated leads to the sockets. The final PCB uses sockets
mounted directly on the board. No USB hub is used.

DIP sockets, module female sockets, PCB fuse clips and mounting hardware
are for the later PCB assembly; see
[PCB purchasing notes](hardware/rev-d/parts.md). The 26 PCB test holes do
not require 26 extra breadboard parts: probe the corresponding named nets.

Use 1% axial 0.25 W resistors and leaded capacitors. Electrolytics are rated
at least 10 V. Confirm lead spacing against the PCB purchasing notes if
buying the same parts for both builds.

## 2. Identify the pins and lay out the breadboard

Place U1 and U2 across the breadboard's center gap. DIP pin numbering is
viewed from above: with the notch at the top, pin 1 is upper left; count
down the left side and then up the right side.

- **U1 is TPS2042P, DIP-8.** TPS2041P has a different pinout; TPS2052 has
  the opposite enable polarity.
- **U2 is CD4050BE, DIP-16. Pin 1 is power and pin 8 is ground.**
  Pins 13 and 16 are unused; do not connect pin 16 to power.
- Q1–Q4 are 2N3904: the design expects physical pin **1 = emitter,
  2 = base, 3 = collector**. Check the actual manufacturer's pinout.
- On the RP2040-Zero, follow the printed **GP0, GP1, etc.** labels.
  M1 numbers in the CSV identify carrier contacts, not GPIO numbers or
  breadboard rows. Do not use underside module pads.

The module's end header is offset from the side headers' breadboard grid.
Use short leads to the end contacts instead of forcing all three rows into
incompatible holes. Keep the USB data pair wiring short, with its 22 Ω
resistors near the module. Use short, substantial supply/ground leads;
do not route the combined receiver load through long breadboard rails.

Label these separate nets before wiring: **5V_BOARD, 5V_MODULE, 3V3,
USB1_5V, USB2_5V, KBD_5V, MOUSE_5V and GND**. Equal net names mean a
connection; different power names are not interchangeable.

## 3. Wire shared power and both chips

Make these connections with power off and no X16 cable connected.

| Connection | Wire it this way |
|---|---|
| External supply positive | J1.1 → F1 → **5V_BOARD** |
| External supply negative | J1.2 → **GND** |
| Module supply jumper | **5V_BOARD** → JP1 → module **5V**, net **5V_MODULE** |
| Module ground | Module **GND** → common **GND** |
| Module regulator output | Module **3V3** → U2 pin **1** |
| U2 ground | U2 pin **8** → **GND** |
| U1 input | U1 pin **2** → **5V_BOARD** |
| U1 ground and enables | U1 pins **1, 3 and 4** → **GND** |
| C1, 470 µF | Positive → **5V_BOARD**; negative → **GND** |
| C2, 10 µF | Positive → **3V3**; negative → **GND** |
| C3, 100 nF | Between U2 pin **1** and **GND**, close to U2 |
| C4, 100 nF | Between U1 pin **2** and **GND**, close to U1 |

**For the first keyboard-only build:** ground U2 pins **7, 9, 11 and 14**.
Leave U2 pins **6, 10, 12, 13, 15 and 16** unconnected. Pins 7 and 9 are
temporary grounds that must be removed when adding the mouse.
Leave unused U1 mouse output pin 6 and fault pin 5 open for this first stage.

Both U1 power channels are always enabled. Neither the firmware nor a
module reset switches receiver power off.

**Programming:** remove JP1 before plugging the module's USB-C into the
computer. The PC then powers the module and U2; the external 5 V supply
still powers the USB receiver sockets. For standalone operation, disconnect
PC USB and reinstall JP1 with power off.

## 4. Wire the keyboard USB input

J2 is a USB-A receptacle. Use its printed breakout labels or verified
connector contact numbers, not a guessed left-to-right view.

| Part/contact | Connection |
|---|---|
| J2 pin 1, VBUS | U1 pin **7**, net **USB1_5V** |
| J2 pin 2, D− | R2 → module **GP1** |
| J2 pin 3, D+ | R1 → module **GP0** |
| J2 pin 4, GND | **GND** |
| J2 shield contacts | **GND**; local PCB pad number 5 |
| R1, 22 Ω | GP0 ↔ J2 D+ |
| R2, 22 Ω | GP1 ↔ J2 D− |
| R3, 15 kΩ | J2 D+ ↔ **GND** |
| R4, 15 kΩ | J2 D− ↔ **GND** |
| C5, 220 µF | Positive → **USB1_5V**; negative → **GND** |
| C6, 100 nF | **USB1_5V** ↔ **GND**, close to J2 |
| R5, 2.2 kΩ | **5V_BOARD** → D1 anode |
| D1 red LED | Anode → R5; cathode → U1 pin **8** |

D1 indicates a USB power fault, not USB activity. Keep the receiver
unplugged until the initial power measurements pass.

## 5. Wire the keyboard PS/2 output

Build the following circuit twice, once for DATA and once for CLOCK.
Each resistor appears once; entries in different columns describe its
complete connection rather than additional components.

| Connection | Keyboard DATA | Keyboard CLOCK |
|---|---|---|
| Drive GPIO through 2.2 kΩ to base | GP8 → R11 → Q1 pin 2 | GP10 → R15 → Q2 pin 2 |
| Base to GND through 47 kΩ | Q1 pin 2 → R12 → GND | Q2 pin 2 → R16 → GND |
| Transistor emitter | Q1 pin 1 → GND | Q2 pin 1 → GND |
| Transistor collector / cable line | Q1 pin 3 = **KBD_DATA** | Q2 pin 3 = **KBD_CLOCK** |
| 4.7 kΩ pull-up | KBD_5V → R13 → KBD_DATA | KBD_5V → R17 → KBD_CLOCK |
| 100 kΩ line pulldown | KBD_DATA → R14 → GND | KBD_CLOCK → R18 → GND |
| Buffer input | KBD_DATA → U2 pin **3** | KBD_CLOCK → U2 pin **5** |
| Buffer output to sense GPIO | U2 pin **2** → **GP9** | U2 pin **4** → **GP11** |
| Output socket J4 | KBD_DATA → J4 contact **3** | KBD_CLOCK → J4 contact **4** |

J4 contact **1** is **KBD_5V**, supplied by the X16 cable only when attached
to a powered X16. J4 contact **2** is **GND**. Leave contacts 5, 6, 7 and
the shell unconnected.

Drive GPIO HIGH pulls its cable line LOW. Drive GPIO LOW releases it.
The sense GPIO reads the actual cable level without inversion.
**Do not connect a 5 V cable signal directly to a module GPIO.**

## 6. Make and check the custom PS/2 cable

The mapping is the same for both outputs. J4 goes to the X16 keyboard port;
J5, added later, goes to its mouse port.

| Adapter 7-pin DIN contact | PS/2 6-pin mini-DIN contact | Signal |
|---:|---:|---|
| 1 | 4 | X16 +5 V reference |
| 2 | 3 | GND |
| 3 | 1 | DATA |
| 4 | 5 | CLOCK |
| 5, 6, 7 and shell | None | Leave unconnected |

Leave PS/2 contacts 2 and 6 unconnected. The front and solder-side views
are mirrored. Identify numbered contacts from the connector drawing and
continuity-test each wire; do not trust insulation colors. Your existing
DIN breakout's terminal numbers must be checked against the actual socket
contacts. Its shield terminal is not a seventh signal contact.

The PS/2 +5 V reference must stay separate from the external **5V_BOARD**
rail. Grounds are common. Keep the cable disconnected from the X16 for now.

## 7. Check the keyboard build before connecting the X16

1. With power off, check for supply-to-ground shorts, LED/capacitor polarity,
   transistor orientation, DIP pin numbers and cable continuity.
2. Apply external regulated 5 V, preferably using a current-limited supply.
   Check approximately 5 V at U1 pin 2 and J2 VBUS, and 3.3 V at U2 pin 1.
   Under the intended receiver load, verify J2 VBUS stays within 4.75–5.25 V.
3. For GPIO tests with the X16 disconnected, temporarily connect **KBD_5V**
   to the bench's regulated 5 V reference. Use test firmware to check that
   drive HIGH gives cable/sense LOW and drive LOW allows cable/sense HIGH.
   **Remove that temporary reference jumper before attaching the X16.**
4. Test USB receiver enumeration and decoded keyboard reports. Then test
   PS/2 framing, reset responses, acknowledgments and host-clock inhibit
   on a suitable fixture. The firmware requirements are in
   [firmware-contract.md](hardware/rev-d/firmware-contract.md).
5. Only after those tests pass, power off, attach the checked keyboard
   cable to the X16 and start the keyboard test.

These are instructions for tests still to be performed. The repository
contains preliminary SPICE results, not a working bridge/test application.
The [test-point guide](hardware/rev-d/test-points.md) identifies equivalent
breadboard probe nodes. Use sense GPIOs for a 3.3 V-only logic analyzer;
the cable lines and fault outputs are in the 5 V domain.

## 8. Add the mouse after keyboard testing passes

Keep power off while adding the mouse. Add the parts in the “Add mouse”
column of the parts list. **Remove the temporary ground connections from
U2 pins 7 and 9** before connecting the mouse lines.

| Part/contact | Mouse USB connection |
|---|---|
| J3 VBUS, pin 1 | U1 pin **6**, net **USB2_5V** |
| J3 D+, pin 3 | R6, 22 Ω → **GP2** |
| J3 D−, pin 2 | R7, 22 Ω → **GP3** |
| J3 GND and shield | **GND** |
| R8, 15 kΩ | J3 D+ ↔ **GND** |
| R9, 15 kΩ | J3 D− ↔ **GND** |
| C7, 220 µF | Positive → **USB2_5V**; negative → **GND** |
| C8, 100 nF | **USB2_5V** ↔ **GND**, close to J3 |
| R10 and D2 fault LED | 5V_BOARD → R10, 2.2 kΩ → D2 anode; D2 cathode → U1 pin **5** |

| Connection | Mouse DATA | Mouse CLOCK |
|---|---|---|
| Drive GPIO through 2.2 kΩ to base | GP12 → R19 → Q3 pin 2 | GP14 → R23 → Q4 pin 2 |
| Base to GND through 47 kΩ | Q3 pin 2 → R20 → GND | Q4 pin 2 → R24 → GND |
| Transistor emitter | Q3 pin 1 → GND | Q4 pin 1 → GND |
| Transistor collector / cable line | Q3 pin 3 = **MOUSE_DATA** | Q4 pin 3 = **MOUSE_CLOCK** |
| 4.7 kΩ pull-up | MOUSE_5V → R21 → MOUSE_DATA | MOUSE_5V → R25 → MOUSE_CLOCK |
| 100 kΩ line pulldown | MOUSE_DATA → R22 → GND | MOUSE_CLOCK → R26 → GND |
| Buffer input | MOUSE_DATA → U2 pin **7** | MOUSE_CLOCK → U2 pin **9** |
| Buffer output to sense GPIO | U2 pin **6** → **GP13** | U2 pin **10** → **GP15** |
| Output socket J5 | MOUSE_DATA → J5 contact **3** | MOUSE_CLOCK → J5 contact **4** |

J5 contact 1 is **MOUSE_5V**, contact 2 is **GND**; contacts 5–7 and shell
remain open. U2 unused inputs **11 and 14 stay grounded**; unused outputs
12 and 15 and unused package pins 13 and 16 stay open. Module GP4–GP7 and
GP26–GP29 remain unused; GP16 serves the onboard LED.

Repeat the power, GPIO and protocol tests for the mouse before connecting
its X16 cable. Then test keyboard and mouse at the same time.

## Full wiring CSV versus the first build

[BREADBOARD-WIRING.csv](BREADBOARD-WIRING.csv) is the **complete two-port
Rev D circuit**, copied from the canonical wiring table. It includes
optional TP1–TP26 contacts and does not represent literal breadboard rows.
For the keyboard-only stage, omit the mouse parts and use the temporary
U2 pin 7/9 grounds described above. Those temporary grounds are deliberately
absent from the final two-port CSV.

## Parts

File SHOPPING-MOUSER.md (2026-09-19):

# LINK COMMANDER Rev D — Mouser breadboard shopping list

**Choose this list OR the Amazon list. Do not buy both lists.** This document now includes the circuit parts, connectors, power supply, wire, insulation, breadboards and custom-cable materials. Nothing in its purchase tables depends on the Amazon shopping document.

**One sourcing exception:** the specified **hiBCTR RP2040-Zero module, M1**, is already yours. I could not verify that exact module at Mouser. Reuse it, or buy the [same module on Amazon — B0DXL12W59](https://www.amazon.com/dp/B0DXL12W59). A Raspberry Pi Pico is not a drop-in replacement. This is therefore a complete breadboard checklist with one explicit outside-store module, not a claim that Mouser sells everything.

**Building five finished PCBs instead?** Use the [full PCB purchase order](MOUSER-PO-01-FIVE-PCBS.md) ([PDF](MOUSER-PO-01-FIVE-PCBS.pdf), [CSV](MOUSER-PO-01-FIVE-PCBS.csv)) or the [chips-only purchase order](MOUSER-PO-02-CHIPS-ONLY.md) ([PDF](MOUSER-PO-02-CHIPS-ONLY.pdf), [CSV](MOUSER-PO-02-CHIPS-ONLY.csv)). Those are separate from this one-unit breadboard list.

## Exact order

The table includes replacements for your existing connectors, headers, breadboard and meter so it also works as a from-scratch checklist. **Delete those rows from your cart if reusing them.** Bare USB/DIN sockets need short soldered, insulated leads to reach breadboard holes; do not force their pins or shell tabs into the breadboard.

| Part | Keyboard only | Full build | Mouser SKU — direct link | Manufacturer part number | Use / reference |
|---|---:|---:|---|---|---|
| USB power-switch chip — PDIP-8 | 1 | 1 | [595-TPS2042P](https://www.mouser.com/en/ProductDetail/Texas-Instruments/TPS2042P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) | TPS2042P | U1 |
| PS/2 input buffer — PDIP-16 | 1 | 1 | [595-CD4050BE](https://www.mouser.com/en/ProductDetail/Texas-Instruments/CD4050BE?qs=j%2FZo4ajzVJLKLpJvKsajlg%3D%3D) | CD4050BE | U2 |
| NPN transistor — TO-92 | 2 | 4 | [512-2N3904BU](https://www.mouser.com/en/ProductDetail/onsemi/2N3904BU?qs=or4AE2qAS%252Bd0Jdpn%2F8ktKg%3D%3D) | 2N3904BU | Q1 Q2 Q3 Q4 |
| 22 Ω resistor — 1%, ¼ W, axial; select Cut Tape | 2 | 4 | [603-MFR-25FRF52-22R](https://www.mouser.com/en/ProductDetail/YAGEO/MFR-25FRF52-22R?qs=oAGoVhmvjhwUlsp%2F3bYXqg%3D%3D) | MFR-25FRF52-22R | R1 R2 R6 R7 |
| 15 kΩ resistor — 1%, ¼ W, axial | 2 | 4 | [603-MFR-25FBF52-15K](https://www.mouser.com/en/ProductDetail/YAGEO/MFR-25FBF52-15K?qs=oAGoVhmvjhzZTLCD9uq%2F7w%3D%3D) | MFR-25FBF52-15K | R3 R4 R8 R9 |
| 2.2 kΩ resistor — 1%, ¼ W, axial | 3 | 6 | [603-MFR-25FBF52-2K2](https://www.mouser.com/en/ProductDetail/YAGEO/MFR-25FBF52-2K2?qs=oAGoVhmvjhwVT9mopfAMPA%3D%3D) | MFR-25FBF52-2K2 | R5 R10 R11 R15 R19 R23 |
| 47 kΩ resistor — 1%, ¼ W, axial | 2 | 4 | [603-MFR-25FBF52-47K](https://www.mouser.com/en/ProductDetail/YAGEO/MFR-25FBF52-47K?qs=oAGoVhmvjhwOchl34Oamzw%3D%3D) | MFR-25FBF52-47K | R12 R16 R20 R24 |
| 4.7 kΩ resistor — 1%, ¼ W, axial | 2 | 4 | [603-MFR-25FBF52-4K7](https://www.mouser.com/en/ProductDetail/YAGEO/MFR-25FBF52-4K7?qs=oAGoVhmvjhyEuU2iU0uA4w%3D%3D) | MFR-25FBF52-4K7 | R13 R17 R21 R25 |
| 100 kΩ resistor — 1%, ¼ W, axial | 2 | 4 | [603-MFR-25FBF52-100K](https://www.mouser.com/en/ProductDetail/YAGEO/MFR-25FBF52-100K?qs=oAGoVhmvjhxAqZbyE%2Fs9bg%3D%3D) | MFR-25FBF52-100K | R14 R18 R22 R26 |
| 100 nF ceramic capacitor — 50 V, leaded | 3 | 4 | [594-K104K15X7RF5TH5](https://www.mouser.com/en/ProductDetail/Vishay-BC-Components/K104K15X7RF5TH5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) | K104K15X7RF5TH5 | C3 C4 C6 C8 |
| 470 µF electrolytic — 25 V, radial | 1 | 1 | [647-UVR1E471MPD](https://www.mouser.com/en/ProductDetail/Nichicon/UVR1E471MPD?qs=eBzRnwgjaQf16mhkgyDt6A%3D%3D) | UVR1E471MPD | C1 |
| 10 µF electrolytic — 50 V, radial | 1 | 1 | [667-EEU-FR1H100](https://www.mouser.com/en/ProductDetail/Panasonic-Industry/EEU-FR1H100?qs=tfZGHB2PWd1NAbdNSgjToQ%3D%3D) | EEU-FR1H100 | C2 |
| 220 µF electrolytic — 16 V, radial | 1 | 2 | [667-EEU-FR1C221](https://www.mouser.com/en/ProductDetail/Panasonic-Industry/EEU-FR1C221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) | EEU-FR1C221 | C5 C7 |
| Red LED — 3 mm, through-hole | 1 | 2 | [604-WP710A10ID](https://www.mouser.com/en/ProductDetail/Kingbright/WP710A10ID?qs=wRBQ8ZgBZ98VyHeNIlWGkQ%3D%3D) | WP710A10ID | D1 D2 |
| 1.5 A fast-blow fuse — 5 × 20 mm | 1 | 1 | [504-BK1/GMA-1.5-R](https://www.mouser.com/en/ProductDetail/Eaton-Electronics/BK1-GMA-1.5-R?qs=9GX7soZQXxHHwQMtPHv6gQ%3D%3D) | BK1/GMA-1.5-R | F1 |
| Inline fuse holder — 5 × 20 mm, wire leads | 1 | 1 | [576-01500274Z](https://www.mouser.com/en/ProductDetail/Littelfuse/01500274Z?qs=2VFNtWizgidXPNQ%2FDEp6Dw%3D%3D) | 01500274Z | F1 holder |
| Regulated 5 V / 3 A wall supply — US plug | 1 | 1 | [709-GSM18U05-P1J](https://www.mouser.com/en/ProductDetail/MEAN-WELL/GSM18U05-P1J?qs=y5B8D4YB%2F3Q73ALXdTERfw%3D%3D) | GSM18U05-P1J | External supply |
| 5.5 × 2.1 mm female barrel-to-screw-terminal adapter | 1 | 1 | [485-368](https://www.mouser.com/en/ProductDetail/Adafruit/368?qs=GURawfaeGuDj%2FuiL%252B50YjQ%3D%3D) | 368 | J1 breadboard connection |
| 7-pin DIN male cable plug — solder terminals | 1 | 2 | [490-SDR-70](https://www.mouser.com/en/ProductDetail/Same-Sky/SDR-70?qs=WyjlAZoYn525nOK6Wu9GaQ%3D%3D) | SDR-70 | Custom PS/2 cable plugs |
| 22 AWG solid-core hookup wire — six-color spool set | 1 | 1 | [485-1311](https://www.mouser.com/en/ProductDetail/Adafruit/1311?qs=GURawfaeGuBbUKgxUfZ%252BxQ%3D%3D) | 1311 | Wiring and removable JP1 jumper |
| Heat-shrink assortment | 1 | 1 | [474-PRT-09353](https://www.mouser.com/en/ProductDetail/SparkFun/PRT-09353?qs=WyAARYrbSnbX2QgoKpWtUQ%3D%3D) | PRT-09353 | Insulation for cable and power joints |
| PS/2 male-to-female extension cable — 6 ft | 1 | 2 | [545-P222006](https://www.mouser.com/en/ProductDetail/Tripp-Lite/P222-006?qs=sukvznpo3Fq6Bwrm0MV4eQ%3D%3D) | P222-006 | One male-ended cable section per output |
| USB-A to USB-C data cable — approximately 1 m | 1 | 1 | [485-4474](https://www.mouser.com/en/ProductDetail/Adafruit/4474?qs=CUBnOrq4ZJz9F%2FNF%252BRRALQ%3D%3D) | 4474 | Module programming |
| Male-to-female jumper wires — 20-pack | 1 | 1 | [485-1954](https://www.mouser.com/en/ProductDetail/Adafruit/1954?qs=GURawfaeGuCB%252BLTF1NsFig%3D%3D) | 1954 | Reach module end-header contacts |
| Full-size solderless breadboard — two give working space | 2 | 2 | [485-239](https://www.mouser.com/en/ProductDetail/Adafruit/239?qs=GURawfaeGuBO%2FIaAv%252BnS1w%3D%3D) | 239 | Reuse existing boards if adequate |
| USB-A female through-hole socket | 1 | 2 | [538-67643-3910](https://www.mouser.com/en/ProductDetail/Molex/67643-3910?qs=x6EjVpvqMVPR04zsu4B0aw%3D%3D) | 67643-3910 | J2 J3; reuse existing breakouts or solder short leads |
| 7-pin DIN female through-hole socket | 1 | 2 | [490-SDS-70J](https://www.mouser.com/en/ProductDetail/Same-Sky/SDS-70J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) | SDS-70J | J4 J5; reuse existing breakouts or solder short leads |
| Male header strips — ten 36-pin strips, 2.54 mm | 1 | 1 | [485-392](https://www.mouser.com/en/ProductDetail/Adafruit/392?qs=GURawfaeGuBPkJS%252B96amuQ%3D%3D) | 392 | M1 headers; omit if already fitted |
| Multimeter for DC voltage, resistance and continuity | 1 | 1 | [485-850](https://www.mouser.com/en/ProductDetail/Adafruit/850?qs=GURawfaeGuBADKQ4LzdFCg%3D%3D) | 850 | Bench tool; omit if owned |

**Order CSVs:** [Keyboard + mouse](SHOPPING-MOUSER-ORDER.csv) · [Keyboard only](SHOPPING-MOUSER-KEYBOARD.csv). Each has 29 unique SKU rows, matching this table. They exclude the outside-store module and workshop tools. Remove already-owned rows before ordering. Select **Cut Tape** for the 22 Ω resistors.

## Cable and power details

- Buy **two P222-006 cables** for the full build. Each has only **one male PS/2 end**. Cut each about 3 ft from its male end and solder an SDR-70 plug to the cut wires using the project's custom-cable pin table. The remaining female-ended sections are unused. Do not buy just one expecting two male ends.
- SDR-70 is a full-size 7-pin DIN cable plug; it is not a PS/2 connector. It matches the SDS-70J family. Check the fit against existing Treedix sockets before soldering. Identify every conductor by continuity, never wire color.
- GSM18U05-P1J supplies regulated **5 V, up to 3 A**, with a US mains plug and a center-positive 5.5×2.1 mm output. Keep the specified **1.5 A fast 5×20 mm fuse**. Connect the barrel adapter positive through that fuse to J1.1; negative goes to J1.2/common ground.
- Splice the inline holder's 16 AWG leads to short 22 AWG solid-core leads; insulate every joint. Do not force thick or stranded wire into breadboard contacts.
- Cut module male headers into **9 + 9 + 5 contacts** if needed. Use male-to-female jumpers for the module's offset end header. Use short solid-core connections for USB D+/D−; long jumper ribbons are not the USB data wiring.
- JP1 is one labeled removable wire from the hookup-wire kit; it needs no extra component on the breadboard.
- The capacitor voltage ratings are maximum ratings, not supply settings. The selected individual capacitors meet the existing PCB's nominal lead spacing/body limits; the circuit remains a 5 V design.

## What this order covers

This is the **Rev D keyboard-and-mouse breadboard**, including its external power supply and two custom cables to the X16. It covers every electrical position in [BREADBOARD-PARTS.csv](BREADBOARD-PARTS.csv). Keyboard-only quantities are an alternative to full-build quantities; do not add them together. All circuit components are through-hole except the assembled RP2040-Zero module. Passive connector breakouts are for breadboarding only.

Have a soldering iron, electronics solder, wire stripper/cutter, small screwdriver and suitable heat source for heat-shrink available. These workshop tools are not included in the component order. The multimeter is listed. The later firmware validation also requires access to a suitable logic analyzer, preferably an oscilloscope, and a computer. Reuse your keyboard, mouse, paired USB receivers and Commander X16; peripheral compatibility is still subject to testing.

This is **not a complete PCB assembly order**. The later carrier adds DIP sockets, female module sockets, PCB fuse clips, JP1 header/shunt, mounting hardware and the fabricated PCB; see [PCB parts](hardware/rev-d/parts.md). The 26 PCB test holes do not require purchased components for this breadboard.

Follow [BREADBOARD.md](BREADBOARD.md), including polarity/continuity checks and removing JP1 before connecting the module to the programming computer. Firmware and physical validation remain pending. Listings were reviewed September 18, 2026; stock, seller and delivery can change.

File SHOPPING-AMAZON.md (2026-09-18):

# LINK COMMANDER Rev D — Amazon breadboard shopping list

**Choose this list OR the Mouser list. Do not buy both lists.** This document covers the entire breadboard checklist, including parts you already own. Each Amazon link is a specific listing, with its ASIN beside it.

**Amazon-only sourcing is not complete:** I could not verify purchasable Amazon listings for the two exact DIP chips, **TPS2042P and CD4050BE**. Both are required. Their exact Mouser links are provided below as the only two required outside-store purchases in this checklist. Do not substitute similarly numbered chips. The Amazon purchases alone cannot complete the circuit.

## Buy once per listing

Quantities below cover both keyboard and mouse. The packs also cover keyboard-only; use the installed-quantity table below to pick parts from them. Skip supplies already on your bench.

| Buy quantity | Product — direct Amazon link | ASIN | What to use |
|---|---|---|---|
| 1 kit | [BOJACK 50-value, 1,350-piece resistor assortment](https://www.amazon.com/dp/B07P3MFG5D) | B07P3MFG5D | All six required 1%, ¼ W axial resistor values; installed quantities below. |
| 1 kit | [BOJACK 630-piece radial electrolytic assortment](https://www.amazon.com/dp/B07PBQXQNQ) | B07PBQXQNQ | C1: 1 × 470 µF; C2: 1 × 10 µF; C5/C7: 2 × 220 µF. Choose ratings ≥10 V. |
| 1 kit | [BOJACK 15-value leaded ceramic assortment](https://www.amazon.com/dp/B07P8N8BW9) | B07P8N8BW9 | C3/C4/C6/C8: 4 × 100 nF (104), 50 V. Keyboard-only uses 3. |
| 1 kit | [BOJACK 10-type TO-92 transistor assortment](https://www.amazon.com/dp/B07T61SY9Y) | B07T61SY9Y | Use only the 2N3904 parts: 2 for keyboard, 4 full. Other transistor types are not substitutes. |
| 1 kit | [300-piece 3 mm / 5 mm LED assortment](https://www.amazon.com/dp/B0F38LJDJB) | B0F38LJDJB | Choose the plain 3 mm red LEDs: 1 keyboard, 2 full; retain circuit resistors. |
| 1 kit | [BOJACK 5×20 inline holders and fast-fuse assortment](https://www.amazon.com/dp/B0813Q4S6P) | B0813Q4S6P | Use 1 holder and 1 × 1.5 A fast fuse for either build. Other fuse values stay unused. |
| 1 supply | [ALITOVE fixed 5 V / 3 A supply with female screw-terminal adapter](https://www.amazon.com/dp/B078RXZM4C) | B078RXZM4C | External supply AND J1 breadboard power connection. Included adapter avoids a separate barrel-adapter purchase. |
| 1 pack | [JING three sets of full-size 7-pin DIN cable plugs / panel sockets](https://www.amazon.com/dp/B0978QLHVD) | B0978QLHVD | Use 1 male plug keyboard, 2 full. Female panel sockets are spare; reuse your DIN breakouts. These are not the PCB-mounted SDS-70J sockets. |
| 1 cable | [JUXINICE 6 ft PS/2 male-to-male cable](https://www.amazon.com/dp/B0933GL5CX) | B0933GL5CX | Cut in half: two approximately 3 ft male-ended sections for the custom keyboard/mouse cables. |
| 1 kit | [TUOFENG 22 AWG solid-core wire, six colors](https://www.amazon.com/dp/B07TX6BX47) | B07TX6BX47 | Breadboard wiring, short power leads and removable JP1 wire. |
| 1 pack | [ELEGOO male/female jumper-wire assortment](https://www.amazon.com/dp/B01EV70C78) | B01EV70C78 | Reach the module end-header pins; use short solid-core wiring for USB data. |
| 1 kit | [Ginsco heat-shrink assortment](https://www.amazon.com/dp/B01MFA3OFA) | B01MFA3OFA | Insulate the cable and power joints. |
| 1 if missing | [Anker USB-A to USB-C data cable](https://www.amazon.com/dp/B01MZIPYPY) | B01MZIPYPY | Programming cable; reuse a data-capable cable if owned. |

**Download:** [Amazon order CSV](SHOPPING-AMAZON-ORDER.csv), including the two clearly labeled Mouser exceptions and the already-owned replacement items.

## Required chips — outside-store exceptions

Both chips are needed even for keyboard-only. These are individually ordered parts, not assortments.

| Buy | Part / package | Exact Mouser SKU — direct product link | Reference |
|---:|---|---|---|
| 1 | TPS2042P, DIP-8 | [595-TPS2042P](https://www.mouser.com/en/ProductDetail/Texas-Instruments/TPS2042P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) | U1 |
| 1 | CD4050BE, DIP-16 | [595-CD4050BE](https://www.mouser.com/en/ProductDetail/Texas-Instruments/CD4050BE?qs=j%2FZo4ajzVJLKLpJvKsajlg%3D%3D) | U2 |

Order these two exact parts in addition to the Amazon purchases. No verified Amazon purchase link is available for them.

## Already-owned items and replacements

These are part of the complete build even if you do not need to buy them again.

| Buy quantity | Product — direct Amazon link | ASIN | What to use |
|---|---|---|---|
| 1 module; already owned | [hiBCTR RP2040-Zero](https://www.amazon.com/dp/B0DXL12W59) | B0DXL12W59 | M1. Reuse your existing module. |
| 1 kit if missing | [yddmyo 14-piece USB connector breakout kit](https://www.amazon.com/dp/B0D7676X4L) | B0D7676X4L | Includes two USB 2.0 Type-A female boards: one bare-header style and one terminal style. Use those two only; reuse your existing USB boards instead if available. |
| 1 pack if missing | [Treedix four 7-pin DIN socket breakout boards](https://www.amazon.com/dp/B0B11JZ1F3) | B0B11JZ1F3 | J4/J5: use 1 keyboard, 2 full. You already own these; breadboard use only. |
| 4 boards if starting empty | [Qunqi 400-contact solderless breadboard](https://www.amazon.com/dp/B0135IQ0ZC) | B0135IQ0ZC | Four half-size boards provide room for the full build. With your existing large board, buy only any expansion space needed. |
| 1 pack if headers missing | [OCR 40-pin straight 2.54 mm male/female header assortment](https://www.amazon.com/dp/B0774VBJ3J) | B0774VBJ3J | Use male strips: cut 9 + 9 + 5 for M1. One extra 4-pin piece can serve the bare USB breakout. Reuse fitted headers. |
| 1 if missing | [AstroAI AM33D multimeter](https://www.amazon.com/dp/B01ISAMUA6) | B01ISAMUA6 | DC voltage, resistance and continuity checks. |

## Installed circuit quantities — pick these from the packs above

Buying one resistor kit covers all six resistor rows; do not order six kits. The same applies to the three electrolytic rows. Each reference below is accounted for once.

| Circuit part | Keyboard only | Full build | References | Source / SKU |
|---|---:|---:|---|---|
| Two-contact 5 V power connection | 1 | 1 | J1 | Included screw adapter: [B078RXZM4C](https://www.amazon.com/dp/B078RXZM4C) |
| 1.5 A fast fuse, 5×20 mm | 1 | 1 | F1 | 1.5 A fuse from kit: [B0813Q4S6P](https://www.amazon.com/dp/B0813Q4S6P) |
| Removable module-power jumper | 1 | 1 | JP1 | Removable wire: [B07TX6BX47](https://www.amazon.com/dp/B07TX6BX47) |
| RP2040-Zero module on headers | 1 | 1 | M1 | Existing module: [B0DXL12W59](https://www.amazon.com/dp/B0DXL12W59) |
| 470 µF / 10 V electrolytic capacitor | 1 | 1 | C1 | Electrolytic kit: [B07PBQXQNQ](https://www.amazon.com/dp/B07PBQXQNQ) |
| 10 µF / 10 V electrolytic capacitor | 1 | 1 | C2 | Electrolytic kit: [B07PBQXQNQ](https://www.amazon.com/dp/B07PBQXQNQ) |
| 100 nF leaded ceramic capacitor | 3 | 4 | C3 C4 C6 C8 | Ceramic kit: [B07P8N8BW9](https://www.amazon.com/dp/B07P8N8BW9) |
| USB-A receptacle, keyboard | 1 | 1 | J2 | Existing USB board or kit: [B0D7676X4L](https://www.amazon.com/dp/B0D7676X4L) |
| TPS2042P dual power switch, DIP-8 | 1 | 1 | U1 | **Mouser** [595-TPS2042P](https://www.mouser.com/en/ProductDetail/Texas-Instruments/TPS2042P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) |
| 22 Ω resistor | 2 | 4 | R1 R2 R6 R7 | Resistor kit: [B07P3MFG5D](https://www.amazon.com/dp/B07P3MFG5D) |
| 15 kΩ resistor | 2 | 4 | R3 R4 R8 R9 | Resistor kit: [B07P3MFG5D](https://www.amazon.com/dp/B07P3MFG5D) |
| 2.2 kΩ resistor | 3 | 6 | R5 R10 R11 R15 R19 R23 | Resistor kit: [B07P3MFG5D](https://www.amazon.com/dp/B07P3MFG5D) |
| 220 µF / 10 V electrolytic capacitor | 1 | 2 | C5 C7 | Electrolytic kit: [B07PBQXQNQ](https://www.amazon.com/dp/B07PBQXQNQ) |
| Red LED, 3 mm | 1 | 2 | D1 D2 | 3 mm red LEDs: [B0F38LJDJB](https://www.amazon.com/dp/B0F38LJDJB) |
| USB-A receptacle, mouse | 0 | 1 | J3 | Existing USB board or kit: [B0D7676X4L](https://www.amazon.com/dp/B0D7676X4L) |
| 7-pin DIN socket, keyboard (SDS-70J for PCB) | 1 | 1 | J4 | Existing DIN board: [B0B11JZ1F3](https://www.amazon.com/dp/B0B11JZ1F3) |
| 7-pin DIN socket, mouse (SDS-70J for PCB) | 0 | 1 | J5 | Existing DIN board: [B0B11JZ1F3](https://www.amazon.com/dp/B0B11JZ1F3) |
| 2N3904 transistor, TO-92 | 2 | 4 | Q1 Q2 Q3 Q4 | 2N3904 from kit: [B07T61SY9Y](https://www.amazon.com/dp/B07T61SY9Y) |
| 47 kΩ resistor | 2 | 4 | R12 R16 R20 R24 | Resistor kit: [B07P3MFG5D](https://www.amazon.com/dp/B07P3MFG5D) |
| 4.7 kΩ resistor | 2 | 4 | R13 R17 R21 R25 | Resistor kit: [B07P3MFG5D](https://www.amazon.com/dp/B07P3MFG5D) |
| 100 kΩ resistor | 2 | 4 | R14 R18 R22 R26 | Resistor kit: [B07P3MFG5D](https://www.amazon.com/dp/B07P3MFG5D) |
| CD4050BE buffer, DIP-16 | 1 | 1 | U2 | **Mouser** [595-CD4050BE](https://www.mouser.com/en/ProductDetail/Texas-Instruments/CD4050BE?qs=j%2FZo4ajzVJLKLpJvKsajlg%3D%3D) |

## Your proposed replacements

| Product | Decision | Reason |
|---|---|---|
| [SQXBK fuse clips — B09XMSVQTJ](https://www.amazon.com/dp/B09XMSVQTJ) | **Skip for this build.** | They hold **6×30 mm** fuses. Rev D uses **5×20 mm**. They also are not a verified match for the PCB's clip footprint. The inline holder above is easier to wire on a breadboard. |
| [Tugermoola panel-mount jack kit — B0DP6MNQQB](https://www.amazon.com/dp/B0DP6MNQQB) | **Suitable optional enclosure jack; not required.** | 5.5×2.1 mm, prewired 20 AWG leads, listing rating 5 A / 50 V. Use one female jack instead of the screw adapter if mounting in a panel. It is not a PCB drop-in connector. |

For the optional panel jack, identify center-pin and outer-barrel leads by continuity before wiring. Center-positive goes through the **1.5 A fuse** to J1.1, outer barrel to J1.2/common ground. Splice its stranded wires to short solid-core breadboard leads and insulate them. Keep the supply at **5 V**; “50 V” is a connector rating.

The listed ALITOVE supply already includes a female screw-terminal adapter. For the simplest breadboard purchase, use that adapter and skip the separate panel-jack kit and DAYKIT adapter pack.

## Assembly details that affect the purchase

- Cut the PS/2 male-to-male cable in half. Solder one 7-pin male plug onto each section following the custom-cable pin table. Check DIN plug fit before soldering; the JING listing photo shows the standard full-size seven-contact pattern, but no sample-fit test has been done. The kit's panel sockets do not replace the PCB-mounted SDS-70J parts.
- Use the plugs' cable clamps/boots for strain relief. Continuity-test conductors to numbered PS/2 contacts; colors are not standardized.
- The BOJACK transistor pack contains several types with different pinouts. Select **2N3904**, and verify emitter/base/collector against the supplied part information before installation.
- Amazon assortment capacitors are selected for the breadboard. Their body dimensions and lead spacing are not verified for the later PCB; use the Mouser individual selections for known nominal PCB dimensions.
- There is no separate radio board to buy: the keyboard/mouse receivers provide the wireless link.

## What this order covers

This is the **Rev D keyboard-and-mouse breadboard**, including its external power supply and two custom cables to the X16. It covers every electrical position in [BREADBOARD-PARTS.csv](BREADBOARD-PARTS.csv). Keyboard-only quantities are an alternative to full-build quantities; do not add them together. All circuit components are through-hole except the assembled RP2040-Zero module. Passive connector breakouts are for breadboarding only.

Have a soldering iron, electronics solder, wire stripper/cutter, small screwdriver and suitable heat source for heat-shrink available. These workshop tools are not included in the component order. The multimeter is listed. The later firmware validation also requires access to a suitable logic analyzer, preferably an oscilloscope, and a computer. Reuse your keyboard, mouse, paired USB receivers and Commander X16; peripheral compatibility is still subject to testing.

This is **not a complete PCB assembly order**. The later carrier adds DIP sockets, female module sockets, PCB fuse clips, JP1 header/shunt, mounting hardware and the fabricated PCB; see [PCB parts](hardware/rev-d/parts.md). The 26 PCB test holes do not require purchased components for this breadboard.

Follow [BREADBOARD.md](BREADBOARD.md), including polarity/continuity checks and removing JP1 before connecting the module to the programming computer. Firmware and physical validation remain pending. Listings were reviewed September 18, 2026; stock, seller and delivery can change.

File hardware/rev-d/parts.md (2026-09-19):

# Rev D parts and assembly

Use [bom-grouped.csv](bom-grouped.csv) for quantities and [bom.csv](bom.csv)
for individual references. All carrier components are through-hole; the
already assembled RP2040-Zero plugs into removable headers.

## Chips, sockets and connectors

| Quantity | Part |
|---:|---|
| 1 | User's hiBCTR RP2040-Zero module, ASIN B0DXL12W59; verify actual header geometry |
| 2 + 1 | 1×9 + 1×5 male headers, 2.54 mm, on the module |
| 2 + 5 | SSW-109-01-T-S 9-contact female sockets + SSW-101-01-T-S individual sockets on the carrier; see orientation below |
| 1 | TPS2042P, PDIP-8, dual channel, active-low enables |
| 1 | CD4050BE, PDIP-16, non-inverting level converter |
| 1 + 1 | DIP-8 + DIP-16 sockets, 7.62 mm row spacing |
| 4 | 2N3904 TO-92; verify 1=emitter, 2=base, 3=collector |
| 2 | USB-A receptacles matching Molex 67643-3910 and the supplied THT footprint |
| 2 | Same Sky SDS-70J, 7-contact right-angle PCB DIN sockets |
| 1 | TE 282834-2, two-position, 2.54 mm pitch input terminal |
| 1 pair | Littelfuse 111-series PCB clips matching the supplied 5×20 fuse footprint |
| 1 | 1.5 A fast 5×20 fuse, chosen for the specified clips and supply |
| 1 | Two-pin 2.54 mm header and removable shunt for JP1 |
| 2 | Red 3 mm LEDs |
| 4 sets | M3 insulating standoffs/screws |

The header and DIP sockets, fuse clips, cable plugs, power supply and
mounting hardware are additional purchasing items, not extra electrical
IC positions. Use complete manufacturer part numbers: “74HC”, “CD4050”
or “TPS2042” alone does not specify a through-hole package.

## Five-board purchasing documents

[Full Mouser PO](../../MOUSER-PO-01-FIVE-PCBS.md) ([PDF](../../MOUSER-PO-01-FIVE-PCBS.pdf), [CSV](../../MOUSER-PO-01-FIVE-PCBS.csv)) includes the circuit components, sockets, fuse clips, mounting feet, external supplies and custom-cable materials for five PCBs. The [chips-only PO](../../MOUSER-PO-02-CHIPS-ONLY.md) contains five of each DIP IC. Both are plain parts tables for presenting to Mouser; no order has been submitted. Arrange pricing and will-call pickup with the supplier. Supply five RP2040-Zero modules and five fabricated boards separately.

### Selected module sockets

For each board, use two Samtec **SSW-109-01-T-S** sockets for the side rows
and five **SSW-101-01-T-S** individual sockets at M1 contacts 10–14. Turn
the single sockets so their **3.05 mm dimension runs parallel to the long
side rows**, with their **2.41 mm dimension along the end row**. All sockets
have the same nominal 8.51 mm body height. Align them on the actual module
before soldering; keep the module removable.

This is a purchasing/assembly refinement; no holes or circuit connections
change. The [Samtec drawing](https://suddendocs.samtec.com/catalog_english/ssw_th.pdf)
specifies a row housing length of contact count × 2.54 mm + 0.51 mm. A complete
SSW-105 housing would nominally overlap the side-row housings at this
footprint's corners. Rotated individual end sockets avoid that overlap,
with nominal 0.13 mm lateral clearance. Manufacturing tolerances and clone
module dimensions still require a physical sample fit. Do not substitute
a complete 5-contact socket strip without checking its housing dimensions.

One Adafruit 392 pack supplies all five modules' male headers and five
2-pin JP1 headers: use five strips, cutting each into 9 + 9 + 5 + 2 contacts.
Ten Littelfuse **01110501Z** clips supply the five fuse positions; these
are individual clips, two per fuse, not complete holders.

## Optional test contacts

TP1–TP26 are bare plated holes already part of the PCB, not 26 required
purchased parts. Each has 2 mm copper and a 1 mm drill. Optional short
single through-hole pins can be fitted for clip probes; check lead fit.
The BOM lists the test positions for traceability. There are still only
50 electrical parts, plus four mounting holes and these 26 test contacts.
See [test-points.md](test-points.md) for the map and voltage domains.

## Resistors and capacitors

| Quantity | Value | References |
|---:|---|---|
| 4 | 22 Ω | R1, R2, R6, R7 |
| 4 | 15 kΩ | R3, R4, R8, R9 |
| 6 | 2.2 kΩ | R5, R10, R11, R15, R19, R23 |
| 4 | 47 kΩ | R12, R16, R20, R24 |
| 4 | 4.7 kΩ | R13, R17, R21, R25 |
| 4 | 100 kΩ | R14, R18, R22, R26 |
| 4 | 100 nF ceramic | C3, C4, C6, C8 |
| 2 | 220 µF / 10 V electrolytic | C5, C7 |
| 1 | 470 µF / 10 V electrolytic | C1 |
| 1 | 10 µF / 10 V electrolytic | C2 |

Use 1% axial 0.25 W resistors, approximately 6.3 × 2.5 mm bodies with
10.16 mm formed lead spacing. The ceramics use 5 mm lead spacing.
C5/C7: 2.5 mm pitch, maximum 6.3 mm diameter. C1: 5 mm pitch, maximum
10 mm diameter. C2: 2 mm pitch, maximum 5 mm diameter. Verify actual
parts against the footprints; electrolytic pin 1 is positive.

## Before assembly

Confirm the actual module and DIN socket against a 1:1 PCB print and samples.
The module footprint is nominal Waveshare-style perimeter-header geometry;
a clone's appearance alone does not prove its mechanical fit. The custom
DIN footprint follows the terminal positions on page 4 of the
[manufacturer drawing](https://www.sameskydevices.com/product/resource/sds-j.pdf).
That drawing's hole-count annotation is inconsistent with its visible
terminal positions, so sample fit is still required.

The supplied local footprint library includes the two logo footprints;
see [FOOTPRINT-LICENSE.txt](kicad/FOOTPRINT-LICENSE.txt) for library licensing.
The logos are silkscreen graphics, not a certification claim.

Solder low parts first: resistors, IC sockets, small capacitors, transistors,
headers/connectors, then tall capacitors. Leave the chips and module out
while inspecting joints and checking power continuity. Align DIP notches,
LED polarity, electrolytic polarity and transistor leads with the assembly
PDF. Install the module sockets using the module as an alignment guide.
The mounting-hole locations are intentionally asymmetric to clear parts.

Provide regulated 5 V / 2 A power, a multimeter, a logic analyzer and ideally
an oscilloscope. There is no dedicated external USB ESD suppressor in this
bench revision. A product release still needs connector ESD and USB signal
integrity review in addition to firmware and electrical testing.

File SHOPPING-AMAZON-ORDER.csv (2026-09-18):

Store | SKU or ASIN | Buy quantity | Description | Product URL | Use or condition
Amazon | B07P3MFG5D | 1 kit | BOJACK 50-value, 1,350-piece resistor assortment | https://www.amazon.com/dp/B07P3MFG5D | All six required 1%, ¼ W axial resistor values; installed quantities below.
Amazon | B07PBQXQNQ | 1 kit | BOJACK 630-piece radial electrolytic assortment | https://www.amazon.com/dp/B07PBQXQNQ | C1: 1 × 470 µF; C2: 1 × 10 µF; C5/C7: 2 × 220 µF. Choose ratings ≥10 V.
Amazon | B07P8N8BW9 | 1 kit | BOJACK 15-value leaded ceramic assortment | https://www.amazon.com/dp/B07P8N8BW9 | C3/C4/C6/C8: 4 × 100 nF (104), 50 V. Keyboard-only uses 3.
Amazon | B07T61SY9Y | 1 kit | BOJACK 10-type TO-92 transistor assortment | https://www.amazon.com/dp/B07T61SY9Y | Use only the 2N3904 parts: 2 for keyboard, 4 full. Other transistor types are not substitutes.
Amazon | B0F38LJDJB | 1 kit | 300-piece 3 mm / 5 mm LED assortment | https://www.amazon.com/dp/B0F38LJDJB | Choose the plain 3 mm red LEDs: 1 keyboard, 2 full; retain circuit resistors.
Amazon | B0813Q4S6P | 1 kit | BOJACK 5×20 inline holders and fast-fuse assortment | https://www.amazon.com/dp/B0813Q4S6P | Use 1 holder and 1 × 1.5 A fast fuse for either build. Other fuse values stay unused.
Amazon | B078RXZM4C | 1 supply | ALITOVE fixed 5 V / 3 A supply with female screw-terminal adapter | https://www.amazon.com/dp/B078RXZM4C | External supply AND J1 breadboard power connection. Included adapter avoids a separate barrel-adapter purchase.
Amazon | B0978QLHVD | 1 pack | JING three sets of full-size 7-pin DIN cable plugs / panel sockets | https://www.amazon.com/dp/B0978QLHVD | Use 1 male plug keyboard, 2 full. Female panel sockets are spare; reuse your DIN breakouts. These are not the PCB-mounted SDS-70J sockets.
Amazon | B0933GL5CX | 1 cable | JUXINICE 6 ft PS/2 male-to-male cable | https://www.amazon.com/dp/B0933GL5CX | Cut in half: two approximately 3 ft male-ended sections for the custom keyboard/mouse cables.
Amazon | B07TX6BX47 | 1 kit | TUOFENG 22 AWG solid-core wire, six colors | https://www.amazon.com/dp/B07TX6BX47 | Breadboard wiring, short power leads and removable JP1 wire.
Amazon | B01EV70C78 | 1 pack | ELEGOO male/female jumper-wire assortment | https://www.amazon.com/dp/B01EV70C78 | Reach the module end-header pins; use short solid-core wiring for USB data.
Amazon | B01MFA3OFA | 1 kit | Ginsco heat-shrink assortment | https://www.amazon.com/dp/B01MFA3OFA | Insulate the cable and power joints.
Amazon | B01MZIPYPY | 1 if missing | Anker USB-A to USB-C data cable | https://www.amazon.com/dp/B01MZIPYPY | Programming cable; reuse a data-capable cable if owned.
Amazon | B0DXL12W59 | 1 module; already owned | hiBCTR RP2040-Zero | https://www.amazon.com/dp/B0DXL12W59 | M1. Reuse your existing module.
Amazon | B0D7676X4L | 1 kit if missing | yddmyo 14-piece USB connector breakout kit | https://www.amazon.com/dp/B0D7676X4L | Includes two USB 2.0 Type-A female boards: one bare-header style and one terminal style. Use those two only; reuse your existing USB boards instead if available.
Amazon | B0B11JZ1F3 | 1 pack if missing | Treedix four 7-pin DIN socket breakout boards | https://www.amazon.com/dp/B0B11JZ1F3 | J4/J5: use 1 keyboard, 2 full. You already own these; breadboard use only.
Amazon | B0135IQ0ZC | 4 boards if starting empty | Qunqi 400-contact solderless breadboard | https://www.amazon.com/dp/B0135IQ0ZC | Four half-size boards provide room for the full build. With your existing large board, buy only any expansion space needed.
Amazon | B0774VBJ3J | 1 pack if headers missing | OCR 40-pin straight 2.54 mm male/female header assortment | https://www.amazon.com/dp/B0774VBJ3J | Use male strips: cut 9 + 9 + 5 for M1. One extra 4-pin piece can serve the bare USB breakout. Reuse fitted headers.
Amazon | B01ISAMUA6 | 1 if missing | AstroAI AM33D multimeter | https://www.amazon.com/dp/B01ISAMUA6 | DC voltage, resistance and continuity checks.
Mouser - required exception | 595-TPS2042P | 1 | TPS2042P | https://www.mouser.com/en/ProductDetail/Texas-Instruments/TPS2042P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 | U1; Amazon listing not verified
Mouser - required exception | 595-CD4050BE | 1 | CD4050BE | https://www.mouser.com/en/ProductDetail/Texas-Instruments/CD4050BE?qs=j%2FZo4ajzVJLKLpJvKsajlg%3D%3D | U2; Amazon listing not verified

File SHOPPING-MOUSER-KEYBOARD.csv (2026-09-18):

Mouser Part Number | Quantity | Manufacturer Part Number | Description | Product URL
595-TPS2042P | 1 | TPS2042P | USB power-switch chip — PDIP-8 | https://www.mouser.com/en/ProductDetail/Texas-Instruments/TPS2042P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
595-CD4050BE | 1 | CD4050BE | PS/2 input buffer — PDIP-16 | https://www.mouser.com/en/ProductDetail/Texas-Instruments/CD4050BE?qs=j%2FZo4ajzVJLKLpJvKsajlg%3D%3D
512-2N3904BU | 2 | 2N3904BU | NPN transistor — TO-92 | https://www.mouser.com/en/ProductDetail/onsemi/2N3904BU?qs=or4AE2qAS%252Bd0Jdpn%2F8ktKg%3D%3D
603-MFR-25FRF52-22R | 2 | MFR-25FRF52-22R | 22 Ω resistor — 1%, ¼ W, axial; select Cut Tape | https://www.mouser.com/en/ProductDetail/YAGEO/MFR-25FRF52-22R?qs=oAGoVhmvjhwUlsp%2F3bYXqg%3D%3D
603-MFR-25FBF52-15K | 2 | MFR-25FBF52-15K | 15 kΩ resistor — 1%, ¼ W, axial | https://www.mouser.com/en/ProductDetail/YAGEO/MFR-25FBF52-15K?qs=oAGoVhmvjhzZTLCD9uq%2F7w%3D%3D
603-MFR-25FBF52-2K2 | 3 | MFR-25FBF52-2K2 | 2.2 kΩ resistor — 1%, ¼ W, axial | https://www.mouser.com/en/ProductDetail/YAGEO/MFR-25FBF52-2K2?qs=oAGoVhmvjhwVT9mopfAMPA%3D%3D
603-MFR-25FBF52-47K | 2 | MFR-25FBF52-47K | 47 kΩ resistor — 1%, ¼ W, axial | https://www.mouser.com/en/ProductDetail/YAGEO/MFR-25FBF52-47K?qs=oAGoVhmvjhwOchl34Oamzw%3D%3D
603-MFR-25FBF52-4K7 | 2 | MFR-25FBF52-4K7 | 4.7 kΩ resistor — 1%, ¼ W, axial | https://www.mouser.com/en/ProductDetail/YAGEO/MFR-25FBF52-4K7?qs=oAGoVhmvjhyEuU2iU0uA4w%3D%3D
603-MFR-25FBF52-100K | 2 | MFR-25FBF52-100K | 100 kΩ resistor — 1%, ¼ W, axial | https://www.mouser.com/en/ProductDetail/YAGEO/MFR-25FBF52-100K?qs=oAGoVhmvjhxAqZbyE%2Fs9bg%3D%3D
594-K104K15X7RF5TH5 | 3 | K104K15X7RF5TH5 | 100 nF ceramic capacitor — 50 V, leaded | https://www.mouser.com/en/ProductDetail/Vishay-BC-Components/K104K15X7RF5TH5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
647-UVR1E471MPD | 1 | UVR1E471MPD | 470 µF electrolytic — 25 V, radial | https://www.mouser.com/en/ProductDetail/Nichicon/UVR1E471MPD?qs=eBzRnwgjaQf16mhkgyDt6A%3D%3D
667-EEU-FR1H100 | 1 | EEU-FR1H100 | 10 µF electrolytic — 50 V, radial | https://www.mouser.com/en/ProductDetail/Panasonic-Industry/EEU-FR1H100?qs=tfZGHB2PWd1NAbdNSgjToQ%3D%3D
667-EEU-FR1C221 | 1 | EEU-FR1C221 | 220 µF electrolytic — 16 V, radial | https://www.mouser.com/en/ProductDetail/Panasonic-Industry/EEU-FR1C221
604-WP710A10ID | 1 | WP710A10ID | Red LED — 3 mm, through-hole | https://www.mouser.com/en/ProductDetail/Kingbright/WP710A10ID?qs=wRBQ8ZgBZ98VyHeNIlWGkQ%3D%3D
504-BK1/GMA-1.5-R | 1 | BK1/GMA-1.5-R | 1.5 A fast-blow fuse — 5 × 20 mm | https://www.mouser.com/en/ProductDetail/Eaton-Electronics/BK1-GMA-1.5-R?qs=9GX7soZQXxHHwQMtPHv6gQ%3D%3D
576-01500274Z | 1 | 01500274Z | Inline fuse holder — 5 × 20 mm, wire leads | https://www.mouser.com/en/ProductDetail/Littelfuse/01500274Z?qs=2VFNtWizgidXPNQ%2FDEp6Dw%3D%3D
709-GSM18U05-P1J | 1 | GSM18U05-P1J | Regulated 5 V / 3 A wall supply — US plug | https://www.mouser.com/en/ProductDetail/MEAN-WELL/GSM18U05-P1J?qs=y5B8D4YB%2F3Q73ALXdTERfw%3D%3D
485-368 | 1 | 368 | 5.5 × 2.1 mm female barrel-to-screw-terminal adapter | https://www.mouser.com/en/ProductDetail/Adafruit/368?qs=GURawfaeGuDj%2FuiL%252B50YjQ%3D%3D
490-SDR-70 | 1 | SDR-70 | 7-pin DIN male cable plug — solder terminals | https://www.mouser.com/en/ProductDetail/Same-Sky/SDR-70?qs=WyjlAZoYn525nOK6Wu9GaQ%3D%3D
485-1311 | 1 | 1311 | 22 AWG solid-core hookup wire — six-color spool set | https://www.mouser.com/en/ProductDetail/Adafruit/1311?qs=GURawfaeGuBbUKgxUfZ%252BxQ%3D%3D
474-PRT-09353 | 1 | PRT-09353 | Heat-shrink assortment | https://www.mouser.com/en/ProductDetail/SparkFun/PRT-09353?qs=WyAARYrbSnbX2QgoKpWtUQ%3D%3D
545-P222006 | 1 | P222-006 | PS/2 male-to-female extension cable — 6 ft | https://www.mouser.com/en/ProductDetail/Tripp-Lite/P222-006?qs=sukvznpo3Fq6Bwrm0MV4eQ%3D%3D
485-4474 | 1 | 4474 | USB-A to USB-C data cable — approximately 1 m | https://www.mouser.com/en/ProductDetail/Adafruit/4474?qs=CUBnOrq4ZJz9F%2FNF%252BRRALQ%3D%3D
485-1954 | 1 | 1954 | Male-to-female jumper wires — 20-pack | https://www.mouser.com/en/ProductDetail/Adafruit/1954?qs=GURawfaeGuCB%252BLTF1NsFig%3D%3D
485-239 | 2 | 239 | Full-size solderless breadboard — two give working space | https://www.mouser.com/en/ProductDetail/Adafruit/239?qs=GURawfaeGuBO%2FIaAv%252BnS1w%3D%3D
538-67643-3910 | 1 | 67643-3910 | USB-A female through-hole socket | https://www.mouser.com/en/ProductDetail/Molex/67643-3910?qs=x6EjVpvqMVPR04zsu4B0aw%3D%3D
490-SDS-70J | 1 | SDS-70J | 7-pin DIN female through-hole socket | https://www.mouser.com/en/ProductDetail/Same-Sky/SDS-70J
485-392 | 1 | 392 | Male header strips — ten 36-pin strips, 2.54 mm | https://www.mouser.com/en/ProductDetail/Adafruit/392?qs=GURawfaeGuBPkJS%252B96amuQ%3D%3D
485-850 | 1 | 850 | Multimeter for DC voltage, resistance and continuity | https://www.mouser.com/en/ProductDetail/Adafruit/850?qs=GURawfaeGuBADKQ4LzdFCg%3D%3D

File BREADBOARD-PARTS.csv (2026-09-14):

Keyboard first qty | Add mouse qty | Full qty | Part / value | References | Package / footprint | Breadboard description
1 | 0 | 1 | 5V INPUT / GND | J1 | TerminalBlock_TE_282834-2_1x02_P2.54mm_Horizontal | Two-contact 5 V power connection
1 | 0 | 1 | 1.5A fast 5x20 | F1 | Fuseholder_Clip-5x20mm_Littelfuse_111_Lateral_P18.80x5.00mm_D1.17mm_Horizontal | 1.5 A fast fuse, 5×20 mm
1 | 0 | 1 | REMOVE FOR PC USB | JP1 | PinHeader_1x02_P2.54mm_Vertical | Removable module-power jumper
1 | 0 | 1 | RP2040-Zero SOCKETS | M1 | RP2040_Zero_HeaderOnly | RP2040-Zero module on headers
1 | 0 | 1 | 470uF 10V | C1 | CP_Radial_D10.0mm_P5.00mm | 470 µF / 10 V electrolytic capacitor
1 | 0 | 1 | 10uF 10V | C2 | CP_Radial_D5.0mm_P2.00mm | 10 µF / 10 V electrolytic capacitor
3 | 1 | 4 | 100nF | C3 C4 C6 C8 | C_Disc_D5.0mm_W2.5mm_P5.00mm | 100 nF leaded ceramic capacitor
1 | 0 | 1 | USB 1 | J2 | USB_A_Molex_67643_Horizontal | USB-A receptacle, keyboard
1 | 0 | 1 | TPS2042P | U1 | DIP-8_W7.62mm_Socket | TPS2042P dual power switch, DIP-8
2 | 2 | 4 | 22R | R1 R2 R6 R7 | R_Axial_DIN0207_L6.3mm_D2.5mm_P10.16mm_Horizontal | 22 Ω resistor
2 | 2 | 4 | 15k | R3 R4 R8 R9 | R_Axial_DIN0207_L6.3mm_D2.5mm_P10.16mm_Horizontal | 15 kΩ resistor
3 | 3 | 6 | 2.2k | R5 R10 R11 R15 R19 R23 | R_Axial_DIN0207_L6.3mm_D2.5mm_P10.16mm_Horizontal | 2.2 kΩ resistor
1 | 1 | 2 | 220uF 10V | C5 C7 | CP_Radial_D6.3mm_P2.50mm | 220 µF / 10 V electrolytic capacitor
1 | 1 | 2 | RED FAULT | D1 D2 | LED_D3.0mm | Red LED, 3 mm
0 | 1 | 1 | USB 2 | J3 | USB_A_Molex_67643_Horizontal | USB-A receptacle, mouse
1 | 0 | 1 | KBD SDS-70J | J4 | SDS-70J | 7-pin DIN socket, keyboard (SDS-70J for PCB)
0 | 1 | 1 | MOUSE SDS-70J | J5 | SDS-70J | 7-pin DIN socket, mouse (SDS-70J for PCB)
2 | 2 | 4 | 2N3904 | Q1 Q2 Q3 Q4 | TO-92_Inline_Wide | 2N3904 transistor, TO-92
2 | 2 | 4 | 47k | R12 R16 R20 R24 | R_Axial_DIN0207_L6.3mm_D2.5mm_P10.16mm_Horizontal | 47 kΩ resistor
2 | 2 | 4 | 4.7k | R13 R17 R21 R25 | R_Axial_DIN0207_L6.3mm_D2.5mm_P10.16mm_Horizontal | 4.7 kΩ resistor
2 | 2 | 4 | 100k | R14 R18 R22 R26 | R_Axial_DIN0207_L6.3mm_D2.5mm_P10.16mm_Horizontal | 100 kΩ resistor
1 | 0 | 1 | CD4050BE | U2 | DIP-16_W7.62mm_Socket | CD4050BE buffer, DIP-16

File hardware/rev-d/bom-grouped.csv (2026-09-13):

Quantity | Part / value | Through-hole footprint | References
1 | 5V INPUT / GND | TerminalBlock_TE_282834-2_1x02_P2.54mm_Horizontal | J1
1 | 1.5A fast 5x20 | Fuseholder_Clip-5x20mm_Littelfuse_111_Lateral_P18.80x5.00mm_D1.17mm_Horizontal | F1
1 | REMOVE FOR PC USB | PinHeader_1x02_P2.54mm_Vertical | JP1
1 | RP2040-Zero SOCKETS | RP2040_Zero_HeaderOnly | M1
1 | 470uF 10V | CP_Radial_D10.0mm_P5.00mm | C1
1 | 10uF 10V | CP_Radial_D5.0mm_P2.00mm | C2
4 | 100nF | C_Disc_D5.0mm_W2.5mm_P5.00mm | C3 C4 C6 C8
1 | USB 1 | USB_A_Molex_67643_Horizontal | J2
1 | TPS2042P | DIP-8_W7.62mm_Socket | U1
4 | 22R | R_Axial_DIN0207_L6.3mm_D2.5mm_P10.16mm_Horizontal | R1 R2 R6 R7
4 | 15k | R_Axial_DIN0207_L6.3mm_D2.5mm_P10.16mm_Horizontal | R3 R4 R8 R9
6 | 2.2k | R_Axial_DIN0207_L6.3mm_D2.5mm_P10.16mm_Horizontal | R5 R10 R11 R15 R19 R23
2 | 220uF 10V | CP_Radial_D6.3mm_P2.50mm | C5 C7
2 | RED FAULT | LED_D3.0mm | D1 D2
1 | USB 2 | USB_A_Molex_67643_Horizontal | J3
1 | KBD SDS-70J | SDS-70J | J4
1 | MOUSE SDS-70J | SDS-70J | J5
4 | 2N3904 | TO-92_Inline_Wide | Q1 Q2 Q3 Q4
4 | 47k | R_Axial_DIN0207_L6.3mm_D2.5mm_P10.16mm_Horizontal | R12 R16 R20 R24
4 | 4.7k | R_Axial_DIN0207_L6.3mm_D2.5mm_P10.16mm_Horizontal | R13 R17 R21 R25
4 | 100k | R_Axial_DIN0207_L6.3mm_D2.5mm_P10.16mm_Horizontal | R14 R18 R22 R26
1 | CD4050BE | DIP-16_W7.62mm_Socket | U2
4 | M3 | MountingHole_3.2mm_M3 | H1 H2 H3 H4
1 | 5V_BOARD | TestPoint_THT_1mm | TP1
1 | 5V_MODULE | TestPoint_THT_1mm | TP2
1 | 3V3 | TestPoint_THT_1mm | TP3
1 | USB1_5V | TestPoint_THT_1mm | TP4
1 | USB2_5V | TestPoint_THT_1mm | TP5
1 | KBD_5V | TestPoint_THT_1mm | TP6
1 | MOUSE_5V | TestPoint_THT_1mm | TP7
1 | 5V_INPUT | TestPoint_THT_1mm | TP8
1 | KBD_DATA | TestPoint_THT_1mm | TP9
1 | KBD_CLOCK | TestPoint_THT_1mm | TP10
1 | MOUSE_DATA | TestPoint_THT_1mm | TP11
1 | MOUSE_CLOCK | TestPoint_THT_1mm | TP12
1 | GP8 | TestPoint_THT_1mm | TP13
1 | GP10 | TestPoint_THT_1mm | TP14
1 | GP12 | TestPoint_THT_1mm | TP15
1 | GP14 | TestPoint_THT_1mm | TP16
1 | GP9 | TestPoint_THT_1mm | TP17
1 | GP11 | TestPoint_THT_1mm | TP18
1 | GP13 | TestPoint_THT_1mm | TP19
1 | GP15 | TestPoint_THT_1mm | TP20
1 | USB1_FAULT | TestPoint_THT_1mm | TP21
1 | USB2_FAULT | TestPoint_THT_1mm | TP22
4 | GND | TestPoint_THT_1mm | TP23 TP24 TP25 TP26

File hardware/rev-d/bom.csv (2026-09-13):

Reference | Part / value | Through-hole footprint | Function | Assembly notes
J1 | 5V INPUT / GND | TerminalBlock_TE_282834-2_1x02_P2.54mm_Horizontal | Power and module
F1 | 1.5A fast 5x20 | Fuseholder_Clip-5x20mm_Littelfuse_111_Lateral_P18.80x5.00mm_D1.17mm_Horizontal | Power and module | Input fuse, 1.5 A fast, 5 x 20 mm; regulated 5 V / 2 A supply.
JP1 | REMOVE FOR PC USB | PinHeader_1x02_P2.54mm_Vertical | Power and module
M1 | RP2040-Zero SOCKETS | RP2040_Zero_HeaderOnly | Power and module | Socketed perimeter headers; GP0-3 USB, GP8-15 PS/2. Other GPIOs unused.
C1 | 470uF 10V | CP_Radial_D10.0mm_P5.00mm | Power and module
C2 | 10uF 10V | CP_Radial_D5.0mm_P2.00mm | Power and module
C3 | 100nF | C_Disc_D5.0mm_W2.5mm_P5.00mm | Input conversion and reset logic
J2 | USB 1 | USB_A_Molex_67643_Horizontal | USB input 1
U1 | TPS2042P | DIP-8_W7.62mm_Socket | Dual USB power protection | Dual-channel TPS2042P DIP-8. /EN1 and /EN2 grounded. OUT1 pin7 keyboard; OUT2 pin6 mouse. Not pin-compatible with TPS2041P.
R1 | 22R | R_Axial_DIN0207_L6.3mm_D2.5mm_P10.16mm_Horizontal | USB input 1
R2 | 22R | R_Axial_DIN0207_L6.3mm_D2.5mm_P10.16mm_Horizontal | USB input 1
R3 | 15k | R_Axial_DIN0207_L6.3mm_D2.5mm_P10.16mm_Horizontal | USB input 1
R4 | 15k | R_Axial_DIN0207_L6.3mm_D2.5mm_P10.16mm_Horizontal | USB input 1
R5 | 2.2k | R_Axial_DIN0207_L6.3mm_D2.5mm_P10.16mm_Horizontal | USB input 1
C4 | 100nF | C_Disc_D5.0mm_W2.5mm_P5.00mm | USB input 1
C5 | 220uF 10V | CP_Radial_D6.3mm_P2.50mm | USB input 1
C6 | 100nF | C_Disc_D5.0mm_W2.5mm_P5.00mm | USB input 1
D1 | RED FAULT | LED_D3.0mm | USB input 1
J3 | USB 2 | USB_A_Molex_67643_Horizontal | USB input 2
R6 | 22R | R_Axial_DIN0207_L6.3mm_D2.5mm_P10.16mm_Horizontal | USB input 2
R7 | 22R | R_Axial_DIN0207_L6.3mm_D2.5mm_P10.16mm_Horizontal | USB input 2
R8 | 15k | R_Axial_DIN0207_L6.3mm_D2.5mm_P10.16mm_Horizontal | USB input 2
R9 | 15k | R_Axial_DIN0207_L6.3mm_D2.5mm_P10.16mm_Horizontal | USB input 2
R10 | 2.2k | R_Axial_DIN0207_L6.3mm_D2.5mm_P10.16mm_Horizontal | USB input 2
C7 | 220uF 10V | CP_Radial_D6.3mm_P2.50mm | USB input 2
C8 | 100nF | C_Disc_D5.0mm_W2.5mm_P5.00mm | USB input 2
D2 | RED FAULT | LED_D3.0mm | USB input 2
J4 | KBD SDS-70J | SDS-70J | Keyboard PS/2 | Custom cable only; E shell contacts unconnected. Target 5V is reference/pull-ups, not board power.
J5 | MOUSE SDS-70J | SDS-70J | Mouse PS/2 | Custom cable only; E shell contacts unconnected. Target 5V is reference/pull-ups, not board power.
Q1 | 2N3904 | TO-92_Inline_Wide | Keyboard PS/2
R11 | 2.2k | R_Axial_DIN0207_L6.3mm_D2.5mm_P10.16mm_Horizontal | Keyboard PS/2
R12 | 47k | R_Axial_DIN0207_L6.3mm_D2.5mm_P10.16mm_Horizontal | Keyboard PS/2
R13 | 4.7k | R_Axial_DIN0207_L6.3mm_D2.5mm_P10.16mm_Horizontal | Keyboard PS/2
R14 | 100k | R_Axial_DIN0207_L6.3mm_D2.5mm_P10.16mm_Horizontal | Keyboard PS/2
Q2 | 2N3904 | TO-92_Inline_Wide | Keyboard PS/2
R15 | 2.2k | R_Axial_DIN0207_L6.3mm_D2.5mm_P10.16mm_Horizontal | Keyboard PS/2
R16 | 47k | R_Axial_DIN0207_L6.3mm_D2.5mm_P10.16mm_Horizontal | Keyboard PS/2
R17 | 4.7k | R_Axial_DIN0207_L6.3mm_D2.5mm_P10.16mm_Horizontal | Keyboard PS/2
R18 | 100k | R_Axial_DIN0207_L6.3mm_D2.5mm_P10.16mm_Horizontal | Keyboard PS/2
Q3 | 2N3904 | TO-92_Inline_Wide | Mouse PS/2
R19 | 2.2k | R_Axial_DIN0207_L6.3mm_D2.5mm_P10.16mm_Horizontal | Mouse PS/2
R20 | 47k | R_Axial_DIN0207_L6.3mm_D2.5mm_P10.16mm_Horizontal | Mouse PS/2
R21 | 4.7k | R_Axial_DIN0207_L6.3mm_D2.5mm_P10.16mm_Horizontal | Mouse PS/2
R22 | 100k | R_Axial_DIN0207_L6.3mm_D2.5mm_P10.16mm_Horizontal | Mouse PS/2
Q4 | 2N3904 | TO-92_Inline_Wide | Mouse PS/2
R23 | 2.2k | R_Axial_DIN0207_L6.3mm_D2.5mm_P10.16mm_Horizontal | Mouse PS/2
R24 | 47k | R_Axial_DIN0207_L6.3mm_D2.5mm_P10.16mm_Horizontal | Mouse PS/2
R25 | 4.7k | R_Axial_DIN0207_L6.3mm_D2.5mm_P10.16mm_Horizontal | Mouse PS/2
R26 | 100k | R_Axial_DIN0207_L6.3mm_D2.5mm_P10.16mm_Horizontal | Mouse PS/2
U2 | CD4050BE | DIP-16_W7.62mm_Socket | PS/2 level conversion | CD4050BE DIP-16, VCC pin 1 = 3V3; GND pin 8. Non-inverting sense. Unused inputs tied to GND.
H1 | M3 | MountingHole_3.2mm_M3 | Mechanical
H2 | M3 | MountingHole_3.2mm_M3 | Mechanical
H3 | M3 | MountingHole_3.2mm_M3 | Mechanical
H4 | M3 | MountingHole_3.2mm_M3 | Mechanical
TP1 | 5V_BOARD | TestPoint_THT_1mm | Test access | Bare plated test hole; optional short single through-hole pin. Not an extra required component.
TP2 | 5V_MODULE | TestPoint_THT_1mm | Test access | Bare plated test hole; optional short single through-hole pin. Not an extra required component.
TP3 | 3V3 | TestPoint_THT_1mm | Test access | Bare plated test hole; optional short single through-hole pin. Not an extra required component.
TP4 | USB1_5V | TestPoint_THT_1mm | Test access | Bare plated test hole; optional short single through-hole pin. Not an extra required component.
TP5 | USB2_5V | TestPoint_THT_1mm | Test access | Bare plated test hole; optional short single through-hole pin. Not an extra required component.
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

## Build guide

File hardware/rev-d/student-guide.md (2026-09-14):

# Understanding LINK COMMANDER Rev D

A modern USB keyboard and an older PS/2 keyboard speak different protocols.
LINK COMMANDER listens to USB and sends the PS/2 messages the X16 expects.
It performs the same translation for a mouse.

For wireless devices, the little USB receiver handles the radio link.
LINK COMMANDER reads USB reports from that receiver; it does not contain
a 2.4 GHz radio. A receiver still needs to use a USB interface supported
by the firmware.

## The two chips

| Reference | Part | Job |
|---|---|---|
| U1 | TPS2042P, DIP-8 | Two protected power channels: one for each USB port. |
| U2 | CD4050BE, DIP-16 | Converts four incoming PS/2 signal levels for the RP2040's 3.3 V inputs. |
| M1 | RP2040-Zero module | Runs the USB host and PS/2 translation program. It plugs into headers. |

U2A, U2B, U2C and U2D on the schematic are four circuits **inside the same
U2 chip**. U2E and U2F are its two unused circuits. U2G shows its supply
pins. You buy one CD4050BE, not seven chips.

U1 contains two separate power switches. A short on either USB port can
assert that port's red fault LED; these are not activity lights. Both
active-low enable pins go to ground, so both ports have power whenever
the external supply is present. Combining the switches in one DIP package
saves a chip and its separate input bypass capacitor. See the
[TI TPS2042 datasheet](https://www.ti.com/lit/gpn/TPS2042).

The CD4050 is specifically a level-converting, non-inverting buffer; do not
substitute an ordinary 74HC buffer. Its input-high voltage can exceed its
supply voltage. This lets the design power U2 from 3.3 V while sensing the
PS/2 lines. See the [TI CD4050 datasheet](https://www.ti.com/lit/ds/symlink/cd4050b.pdf).

## Why there are four transistors

A PS/2 cable has two signal wires: DATA and CLOCK. Either end may need to
pull a line LOW. The adapter must also let go so the other end can speak.
This is why simply sending characters on an ordinary serial output is
not enough.

Each 2N3904 transistor works as a switch to ground:

1. The RP2040 raises a drive GPIO. Current passes through a 2.2 kΩ resistor
   into the transistor's base. The transistor pulls its cable line LOW.
2. The RP2040 lowers the drive GPIO. The transistor turns off. A 4.7 kΩ
   pullup resistor lets the cable line rise, unless the X16 is holding it LOW.
3. U2 reads the cable level and presents it to a separate RP2040 input.

Q1/Q2 serve keyboard DATA/CLOCK. Q3/Q4 serve mouse DATA/CLOCK.
The 47 kΩ base resistors hold the switches off while the module starts.
The 100 kΩ line resistors provide a weak path to ground when the target
reference supply is absent. They are much weaker than the 4.7 kΩ pullups.

| Drive GPIO | Transistor | Cable line, if X16 releases it | Sense GPIO |
|---|---|---|---|
| LOW | Off | HIGH through pullup | HIGH |
| HIGH | On | LOW | LOW |

The sense signal is **not inverted in Rev D**. Firmware should enable input
hysteresis on these GPIOs; the RP2040 provides this in its GPIO hardware.
See the [official GPIO API](https://www.raspberrypi.com/documentation/pico-sdk/hardware.html).
This does not eliminate the need to measure actual PS/2 signal edges.

## Reading the schematic

Read the sheet in order: power, module, logic power, USB keyboard, USB mouse,
PS/2 keyboard, PS/2 mouse, then test access. Section 8 shows TP1–TP26;
use [the test-point map](test-points.md) to choose what to measure. Green wires show connections. A dot means wires
join. A crossing without a dot does not join. Equal net names connect even
when a long wire is omitted between sections.

`R11.1` means pin 1 of resistor R11. `J4.3` means contact 3 of output socket
J4. `GP8` is the GPIO label on the module; it is not physical header pin 8.
The complete [pin table](breadboard-wiring.csv) shows both names.

- R = resistor; its value controls current or establishes a weak HIGH/LOW.
- C = capacitor; the nearby capacitors help keep supplies steady.
- Q = transistor; here it is a switch to ground.
- U = integrated circuit; its physical pin numbers are shown.
- J = connector; JP1 is a removable jumper; F1 is the input fuse.
- TP = a plated probe hole, optionally fitted with a short through-hole pin.
- An X on a pin means leave it unconnected, not connect it to ground.

The master PDF is one large vector sheet. Zoom in on one section at a time;
printing the entire schematic on one letter-sized page will make the text
small. The assembly PDF is a separate A4 landscape page.

## Three power names to keep separate

**5V_BOARD** comes from the external supply through F1. It powers the two
USB ports. **3V3** comes from the RP2040-Zero and powers U2. **KBD_5V** and
**MOUSE_5V** come from the X16 through the custom cables and supply only the
PS/2 pullups. Do not join those reference nets to 5V_BOARD.

All signal grounds are connected together. A 5 V signal must never be
connected directly to an RP2040 GPIO.

JP1 connects 5V_BOARD to the module's 5 V header. **Remove JP1 before
connecting the module's USB-C to a computer.** This is a manual jumper,
not automatic power-source switching. See the reference
[RP2040-Zero schematic](https://files.waveshare.com/upload/4/4c/RP2040_Zero.pdf)
and verify the actual module before powering it.

## First learning exercise

Build only the keyboard half using [the breadboard guide](breadboard.md).
Identify its drive transistor, pullup and sense buffer on the schematic.
With the X16 disconnected, use test firmware and a meter/logic analyzer to
confirm the truth table above. Then verify host-command handling on a
PS/2 test fixture before attempting an X16 test. Test firmware and bridge
firmware have not yet been supplied or validated in this revision.

## Simulating the switch

The [SPICE study](simulation/README.md) shows an example of drive, cable
and sense voltages. Its GPIO and host are test stimuli, not running
firmware. Read the model limitations before comparing the plot with
measurements from your own circuit.

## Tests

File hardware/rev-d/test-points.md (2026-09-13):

# Rev D test points

The external regulated **5 V supply stays in use**. PS/2 power is still
separate and supplies only the cable-side signal pull-ups.

The PCB has **26 dedicated plated test holes**, labeled TP1–TP26. Each has
2 mm exposed copper on both sides and a 1 mm plated hole. Probe the pad
as supplied, or solder in an optional short single through-hole pin that
fits the hole. No extra component is required for the circuit to work.
Keep optional pins upright and short; do not let them contact nearby parts.

Locate TP numbers on the assembly PDF and in schematic section 8. Equal
net labels connect the test symbols to the circuits in sections 1–7.
The [test-point CSV](test-points.csv) also includes the four existing USB
data probe pads. Board coordinates in [placement.csv](placement.csv) use
the KiCad origin, not a breadboard row number.

## Power: use a multimeter first

Measure relative to any GND test point. The voltages below are nominal
expectations for a correctly powered board, not measured test results.

| Test point | Net | What to check |
|---|---|---|
| TP8 | 5V_INPUT | External 5 V before F1 |
| TP1 | 5V_BOARD | External 5 V after F1 |
| TP2 | 5V_MODULE | Module supply after JP1; may instead come from PC USB when JP1 is removed |
| TP3 | 3V3 | Module-regulated 3.3 V powering U2 |
| TP4 | USB1_5V | Keyboard receiver supply after U1 |
| TP5 | USB2_5V | Mouse receiver supply after U1 |
| TP6 | KBD_5V | Keyboard cable's X16 +5 V reference |
| TP7 | MOUSE_5V | Mouse cable's X16 +5 V reference |
| TP23, TP24, TP25, TP26 | GND | Four locations for meter/probe ground |

TP6/TP7 are not powered by the external supply. Expect them to be unpowered
with the X16 disconnected unless the isolated bench fixture supplies the
references. Do not bridge them to TP1, TP2, TP4 or TP5.

Remove JP1 before attaching PC USB-C, as in the breadboard guide. Test
points are for measurement; they are not power-selection jumpers.

## PS/2: compare drive, cable and sense

| Signal | Drive: 3.3 V GPIO | Cable: 5 V domain | Sense: 3.3 V GPIO |
|---|---|---|---|
| Keyboard DATA | TP13 / GP8 | TP9 / KBD_DATA | TP17 / GP9 |
| Keyboard CLOCK | TP14 / GP10 | TP10 / KBD_CLOCK | TP18 / GP11 |
| Mouse DATA | TP15 / GP12 | TP11 / MOUSE_DATA | TP19 / GP13 |
| Mouse CLOCK | TP16 / GP14 | TP12 / MOUSE_CLOCK | TP20 / GP15 |

With the reference powered and the host releasing the line:

- Drive LOW releases the transistor; cable and sense should become HIGH.
- Drive HIGH turns the transistor on; cable and sense should become LOW.

The X16 can also pull a cable line LOW while the drive GPIO is LOW. That
is normal PS/2 behavior. A meter can check static levels; use an oscilloscope
or suitable logic analyzer for edges, timing and protocol traffic. For a
3.3 V-only analyzer, use the sense points, not the 5 V cable points.

## USB power faults

| Test point | Net | Connection |
|---|---|---|
| TP21 | USB1_FAULT | U1 pin 8 and keyboard fault LED cathode |
| TP22 | USB2_FAULT | U1 pin 5 and mouse fault LED cathode |

These open-drain fault outputs pull LOW when asserted. The LED/resistor
path returns to 5V_BOARD; these are not 3.3 V logic test points. The inactive
voltage is not specified as a digital HIGH by this LED circuit. Start by
observing the fault LED and measuring with a high-impedance meter or probe.

## USB data: existing pads, no additional branches

Use the exposed pin-1 annulus or lead of the corresponding 15 kΩ resistor.
The nearby silkscreen identifies USB1/USB2 and D+/D−. Pin 1 is the left
pad of these horizontal resistors in the top assembly view; pin 2 is GND.

| USB signal | Existing probe pad | Nearby ground pad |
|---|---|---|
| Keyboard D+ | R3.1 | R3.2 |
| Keyboard D− | R4.1 | R4.2 |
| Mouse D+ | R8.1 | R8.2 |
| Mouse D− | R9.1 | R9.2 |

No dedicated header or long test-point branch was added to the USB data
nets. Use a suitable low-capacitance probe with a short ground connection;
probe loading can change the signal being measured. See
[Tektronix's probe primer](https://www.tek.com/en/documents/whitepaper/abcs-probes-primer).
A basic GPIO logic analyzer capture is not a USB signal-integrity test.

## Other accessible nodes

The module-side USB signals are available at R1.1, R2.1, R6.1 and R7.1.
Transistor bases are accessible at Q1.2–Q4.2 or their base-resistor ends.
LED anodes are accessible at D1.2/D2.2. Unused module GPIOs remain available
at their original perimeter header contacts. Use the full wiring CSV to
identify these nodes; do not assume they have the same voltage or function
as the nearby dedicated test point.

Begin with the X16 disconnected and follow the staged tests in
[breadboard.md](breadboard.md). Firmware and physical test results are
still outstanding; adding test access does not validate the adapter.

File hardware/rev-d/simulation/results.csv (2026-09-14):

channel | target_v | logic_v | external_cap_pf | idle_line | driven_line | host_line | idle_sense | driven_sense | host_sense | release_10_90 | base_drive | gpio_current_ma
KBD_DATA | 4.75 | 3.135 | 100 | 4.536734 | -0.01387175 | 0.01008391 | 3.135 | 1.181047e-14 | -2.301081e-12 | 1.054409e-06 | 0.6635722 | 1.1082635874439462
KBD_DATA | 4.75 | 3.135 | 500 | 4.536734 | -0.01387175 | 0.01008392 | 3.135 | 4.544313e-14 | -1.203046e-12 | 4.999118e-06 | 0.663572 | 1.1082636771300447
KBD_DATA | 4.75 | 3.135 | 1000 | 4.536734 | -0.01387175 | 0.01008392 | 3.135 | -4.124069e-14 | -4.104803e-13 | 9.930933e-06 | 0.6635717 | 1.1082638116591927
KBD_DATA | 5.0 | 3.3 | 100 | 4.77551 | -0.01459561 | 0.01061465 | 3.3 | 4.221479e-15 | -8.821525e-12 | 1.054136e-06 | 0.6664224 | 1.1809765022421523
KBD_DATA | 5.0 | 3.3 | 500 | 4.77551 | -0.01459561 | 0.01061465 | 3.3 | -6.673421e-15 | -6.24319e-12 | 4.998942e-06 | 0.6664229 | 1.1809762780269057
KBD_DATA | 5.0 | 3.3 | 1000 | 4.77551 | -0.0145956 | 0.01061465 | 3.3 | 5.122273e-14 | -5.173285e-12 | 9.930696e-06 | 0.6664215 | 1.1809769058295962
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

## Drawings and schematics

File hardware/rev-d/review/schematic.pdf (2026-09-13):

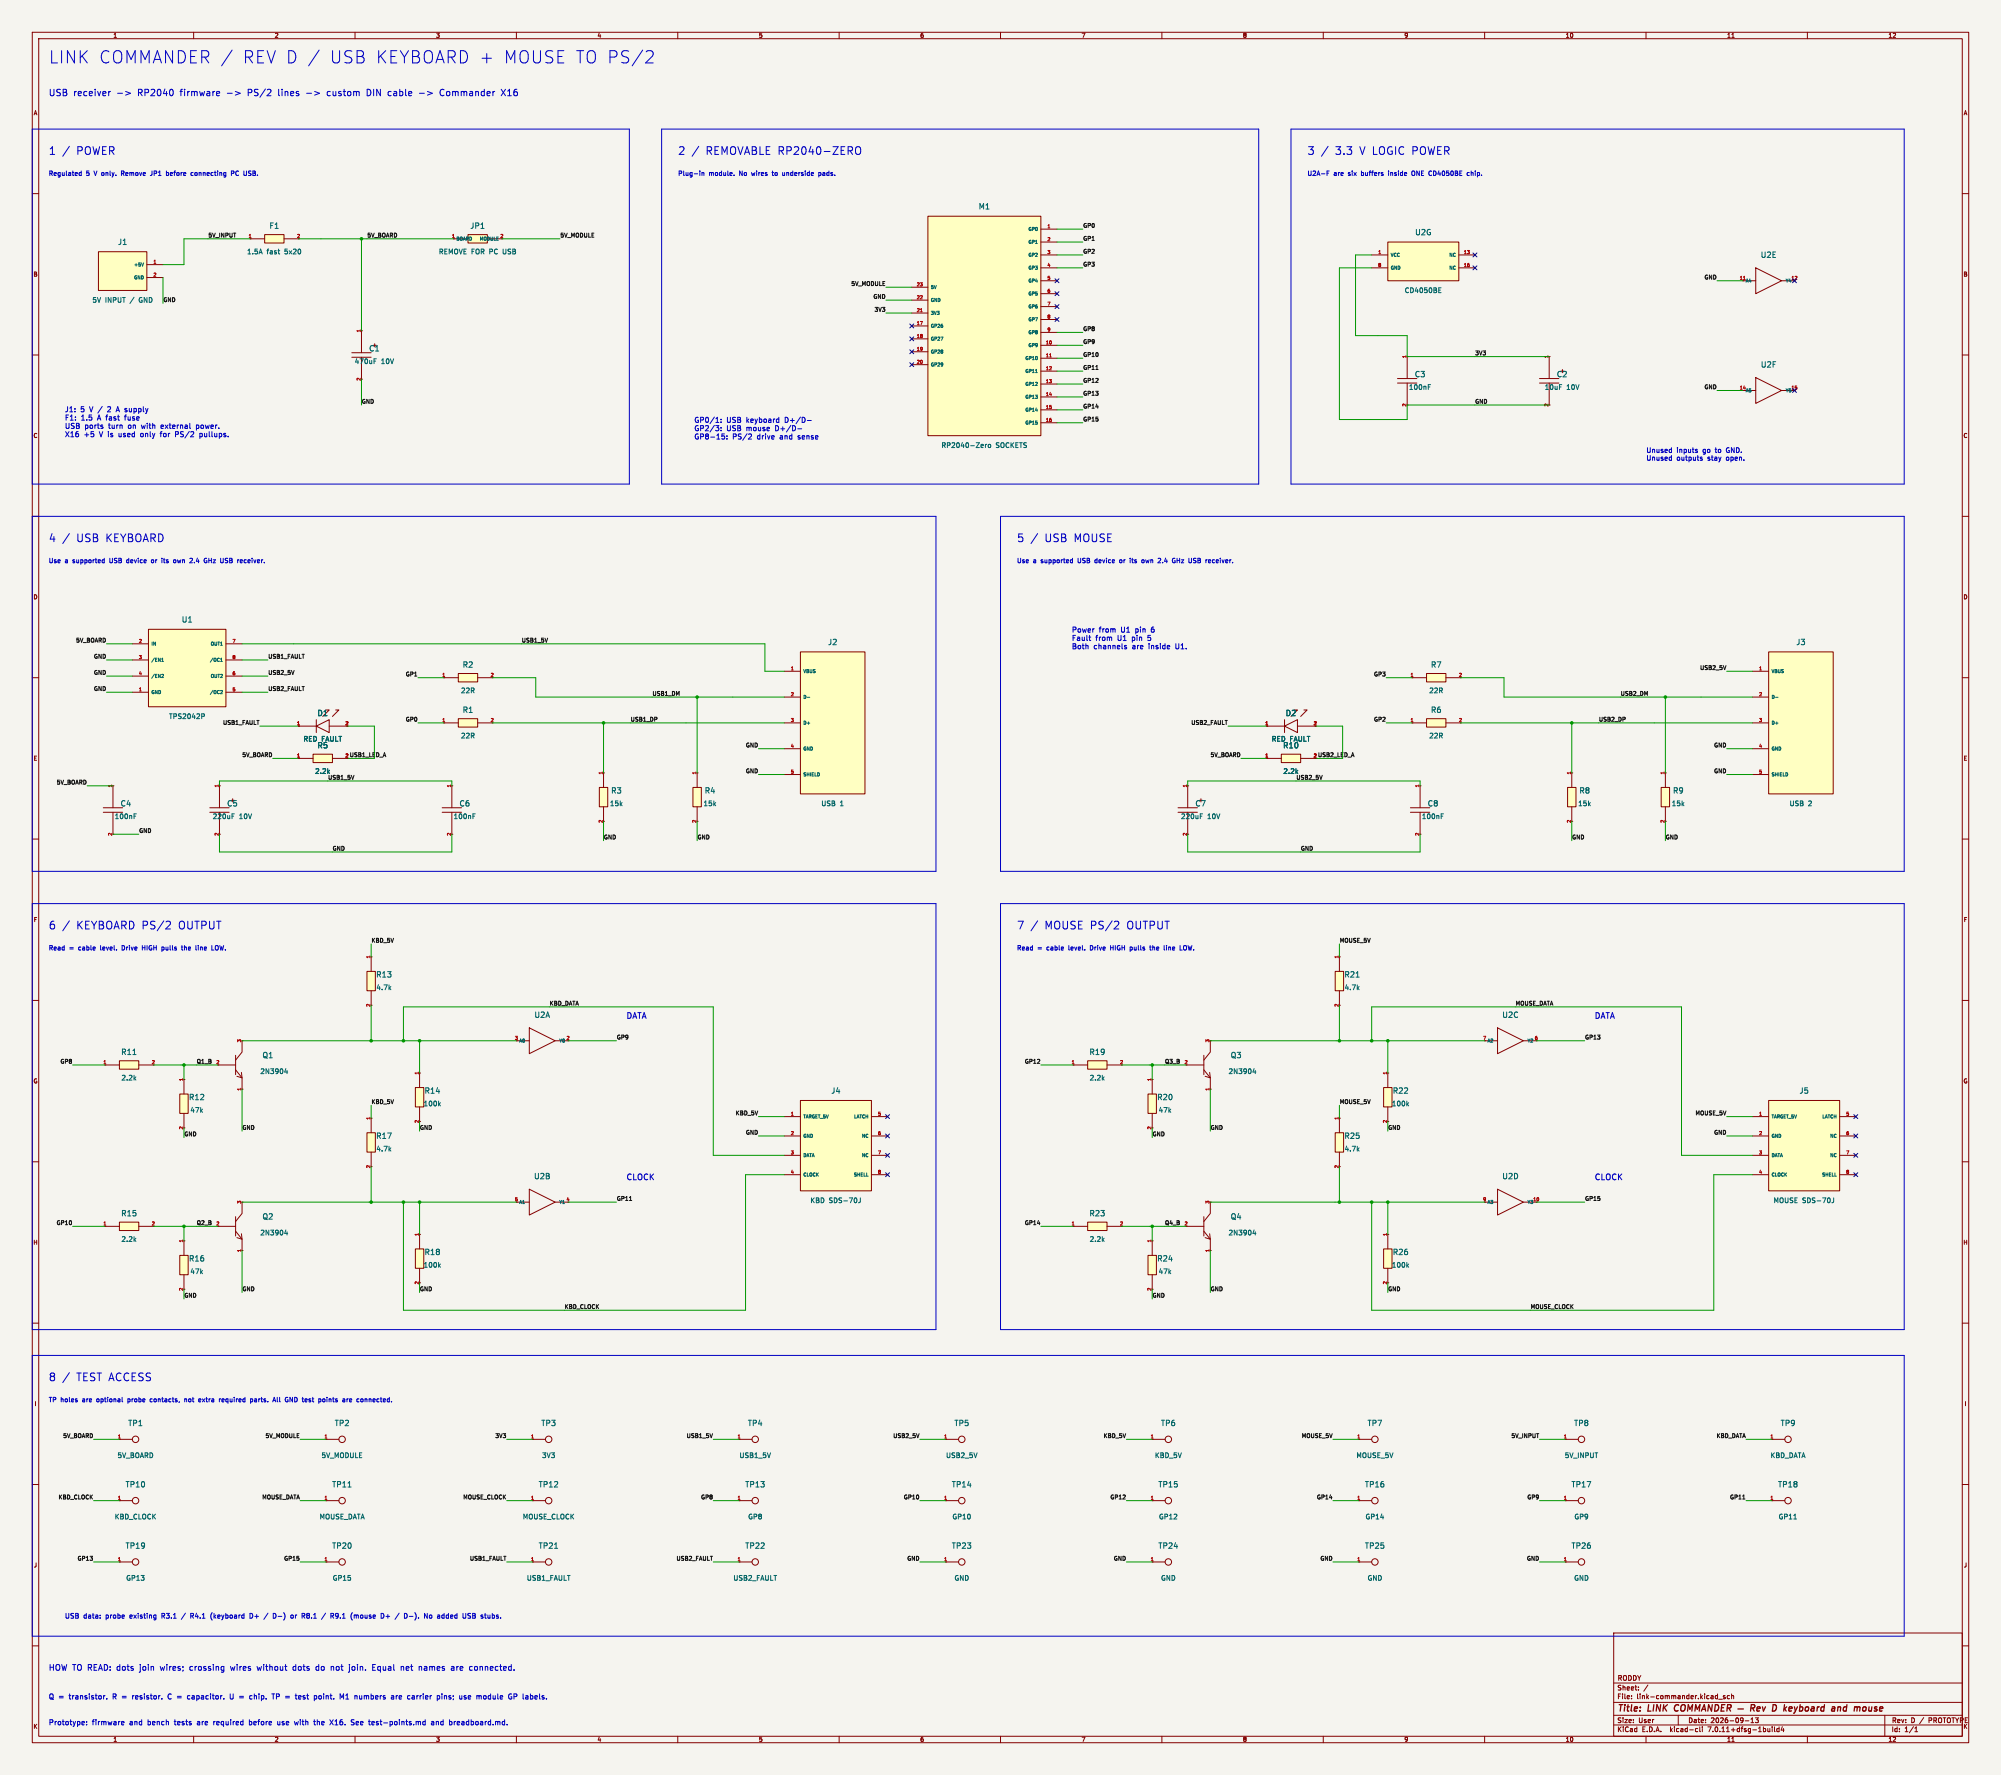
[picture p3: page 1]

U2A-F are six buffers inside ONE CD4050BE chip.

J1: 5 V / 2 A supply
F1: 1.5 A fast fuse
USB ports turn on with external power.
X16 +5 V is used only for PS/2 pullups.

Read = cable level. Drive HIGH pulls the line LOW.

File: link-commander.kicad_sch Sheet: / RODDY

Id: 1/1 Title: LINK COMMANDER þÿ Rev D keyboard and mouse

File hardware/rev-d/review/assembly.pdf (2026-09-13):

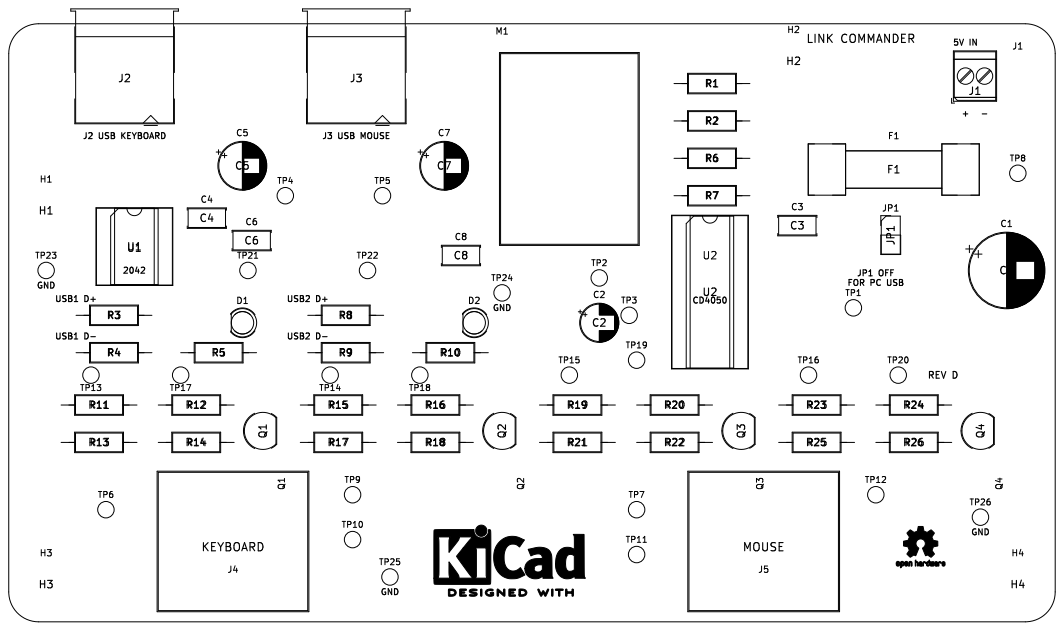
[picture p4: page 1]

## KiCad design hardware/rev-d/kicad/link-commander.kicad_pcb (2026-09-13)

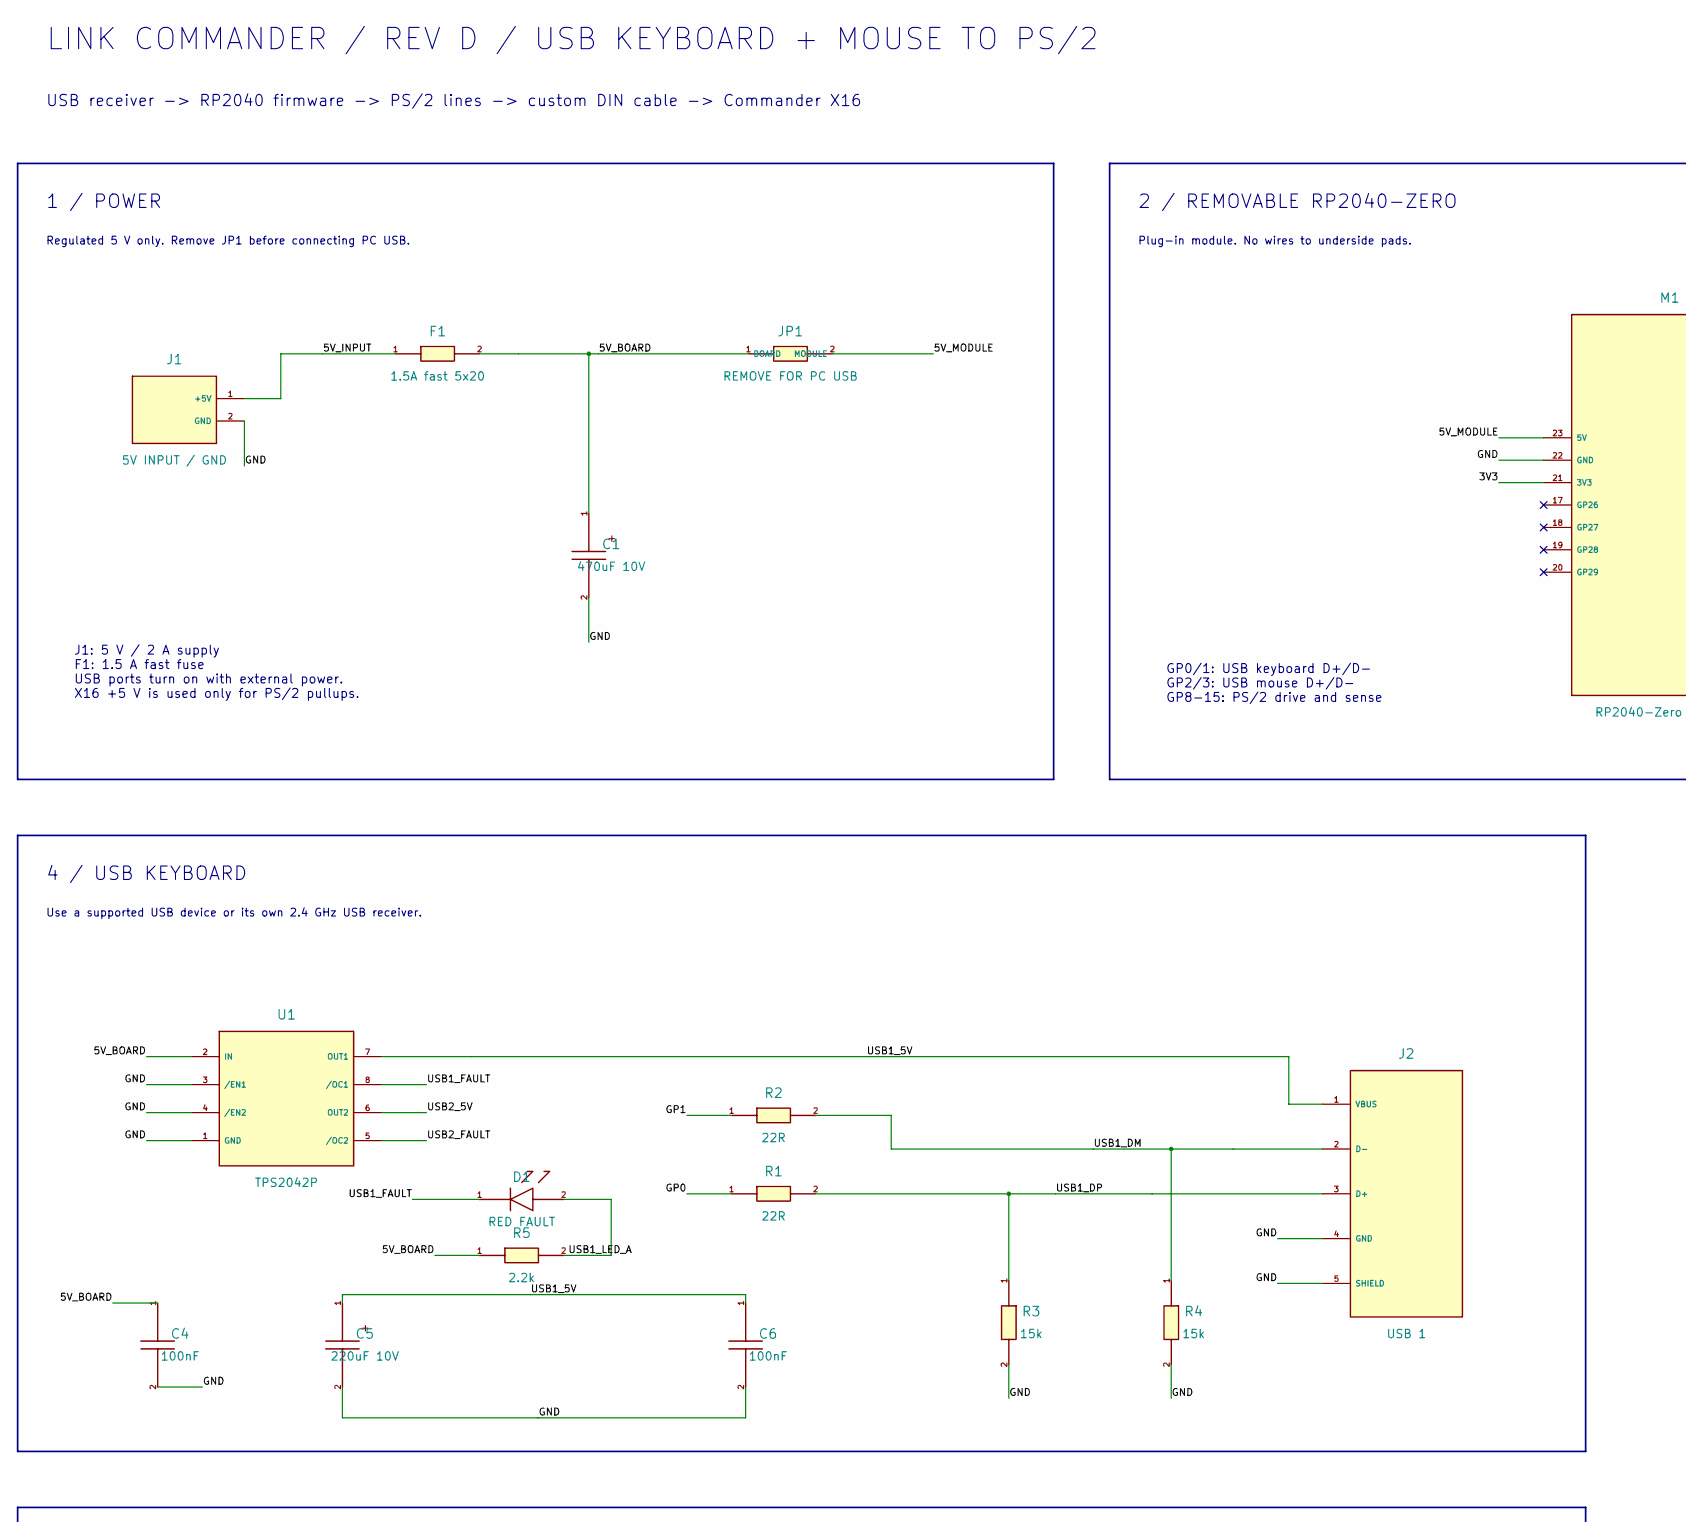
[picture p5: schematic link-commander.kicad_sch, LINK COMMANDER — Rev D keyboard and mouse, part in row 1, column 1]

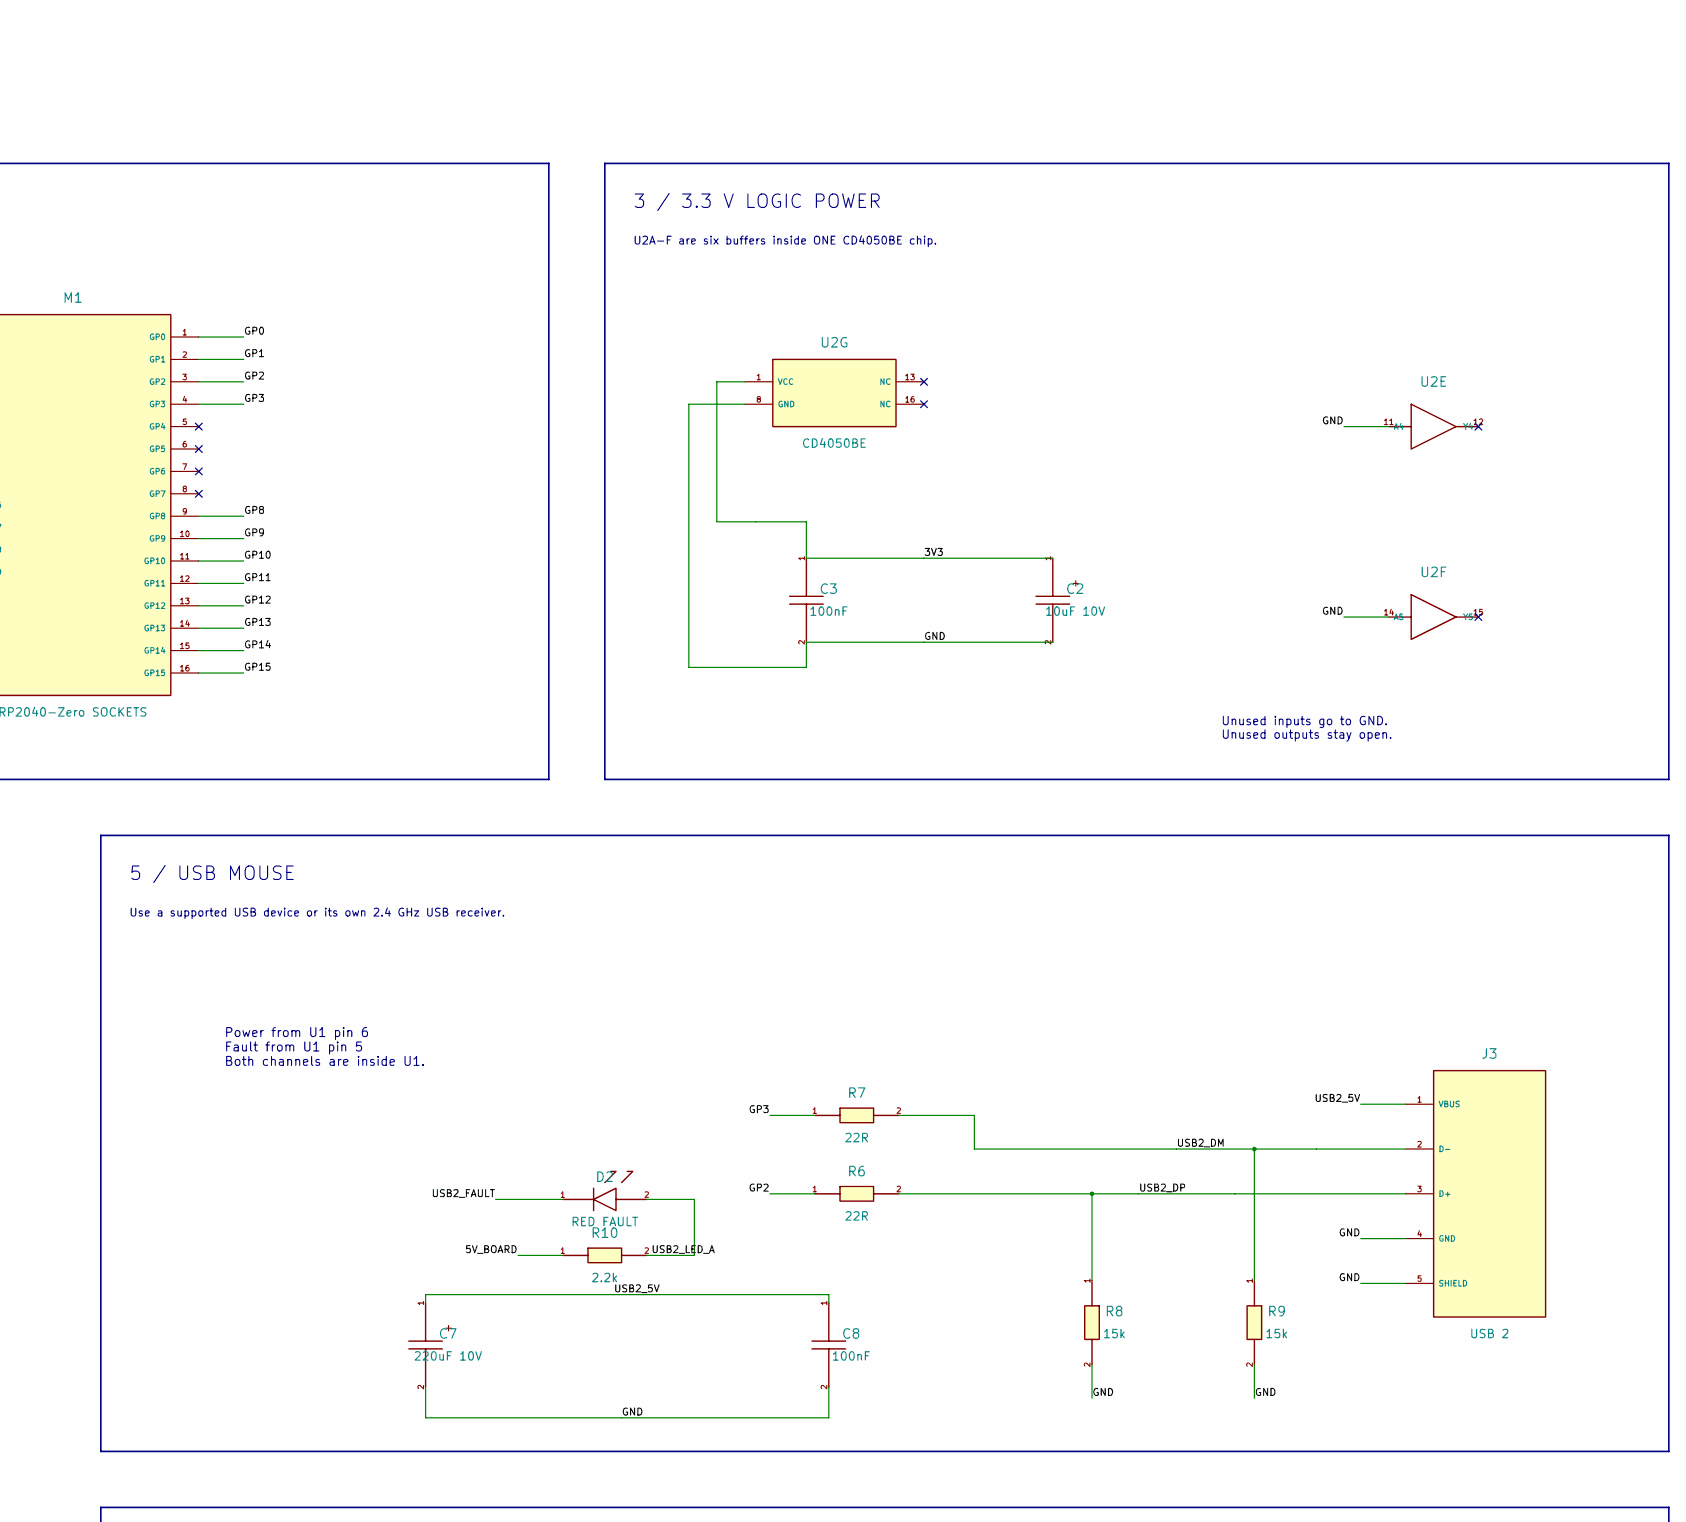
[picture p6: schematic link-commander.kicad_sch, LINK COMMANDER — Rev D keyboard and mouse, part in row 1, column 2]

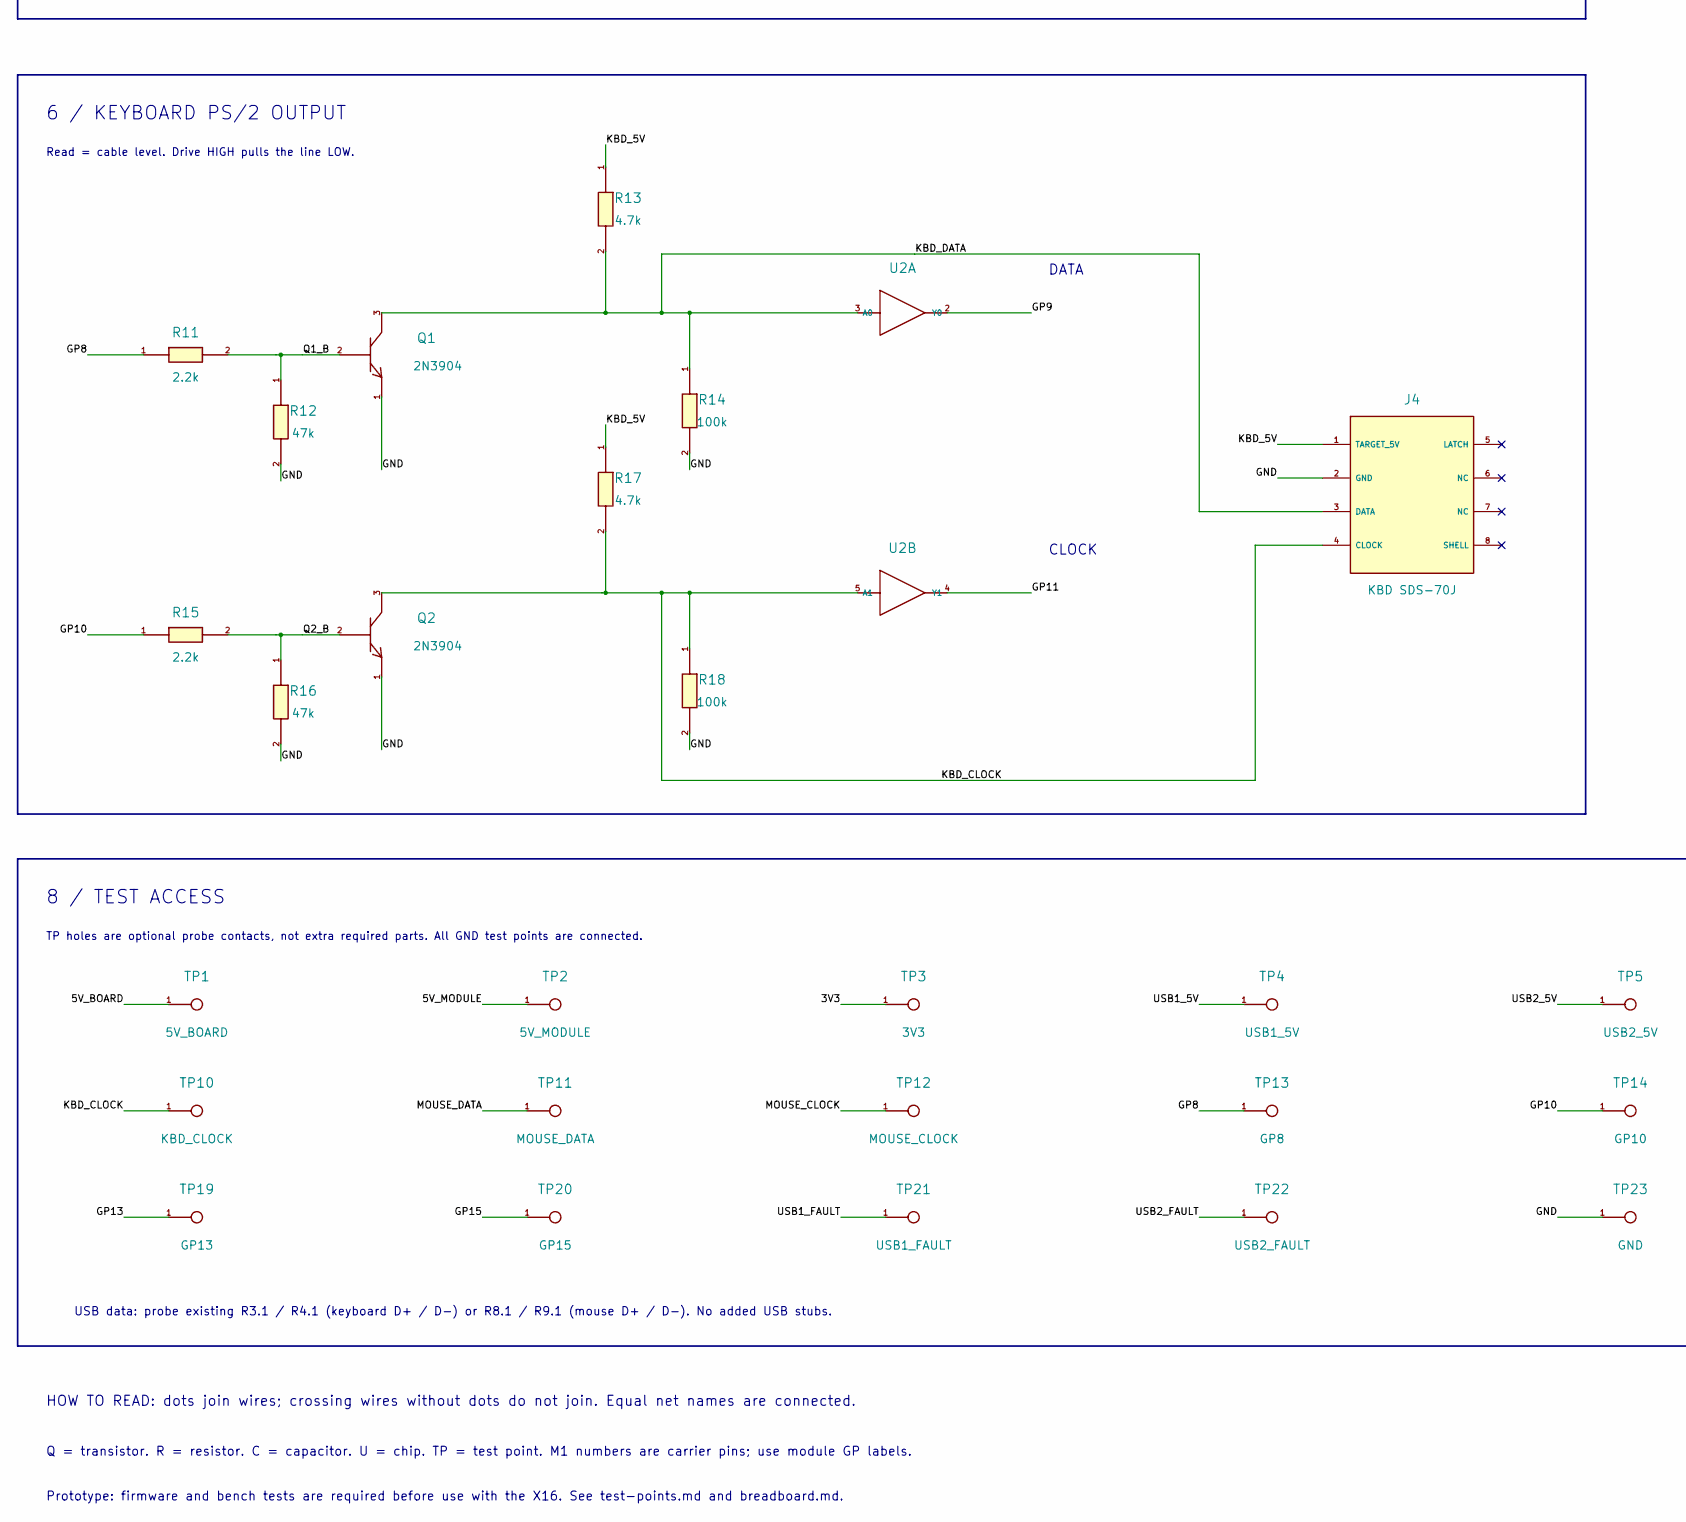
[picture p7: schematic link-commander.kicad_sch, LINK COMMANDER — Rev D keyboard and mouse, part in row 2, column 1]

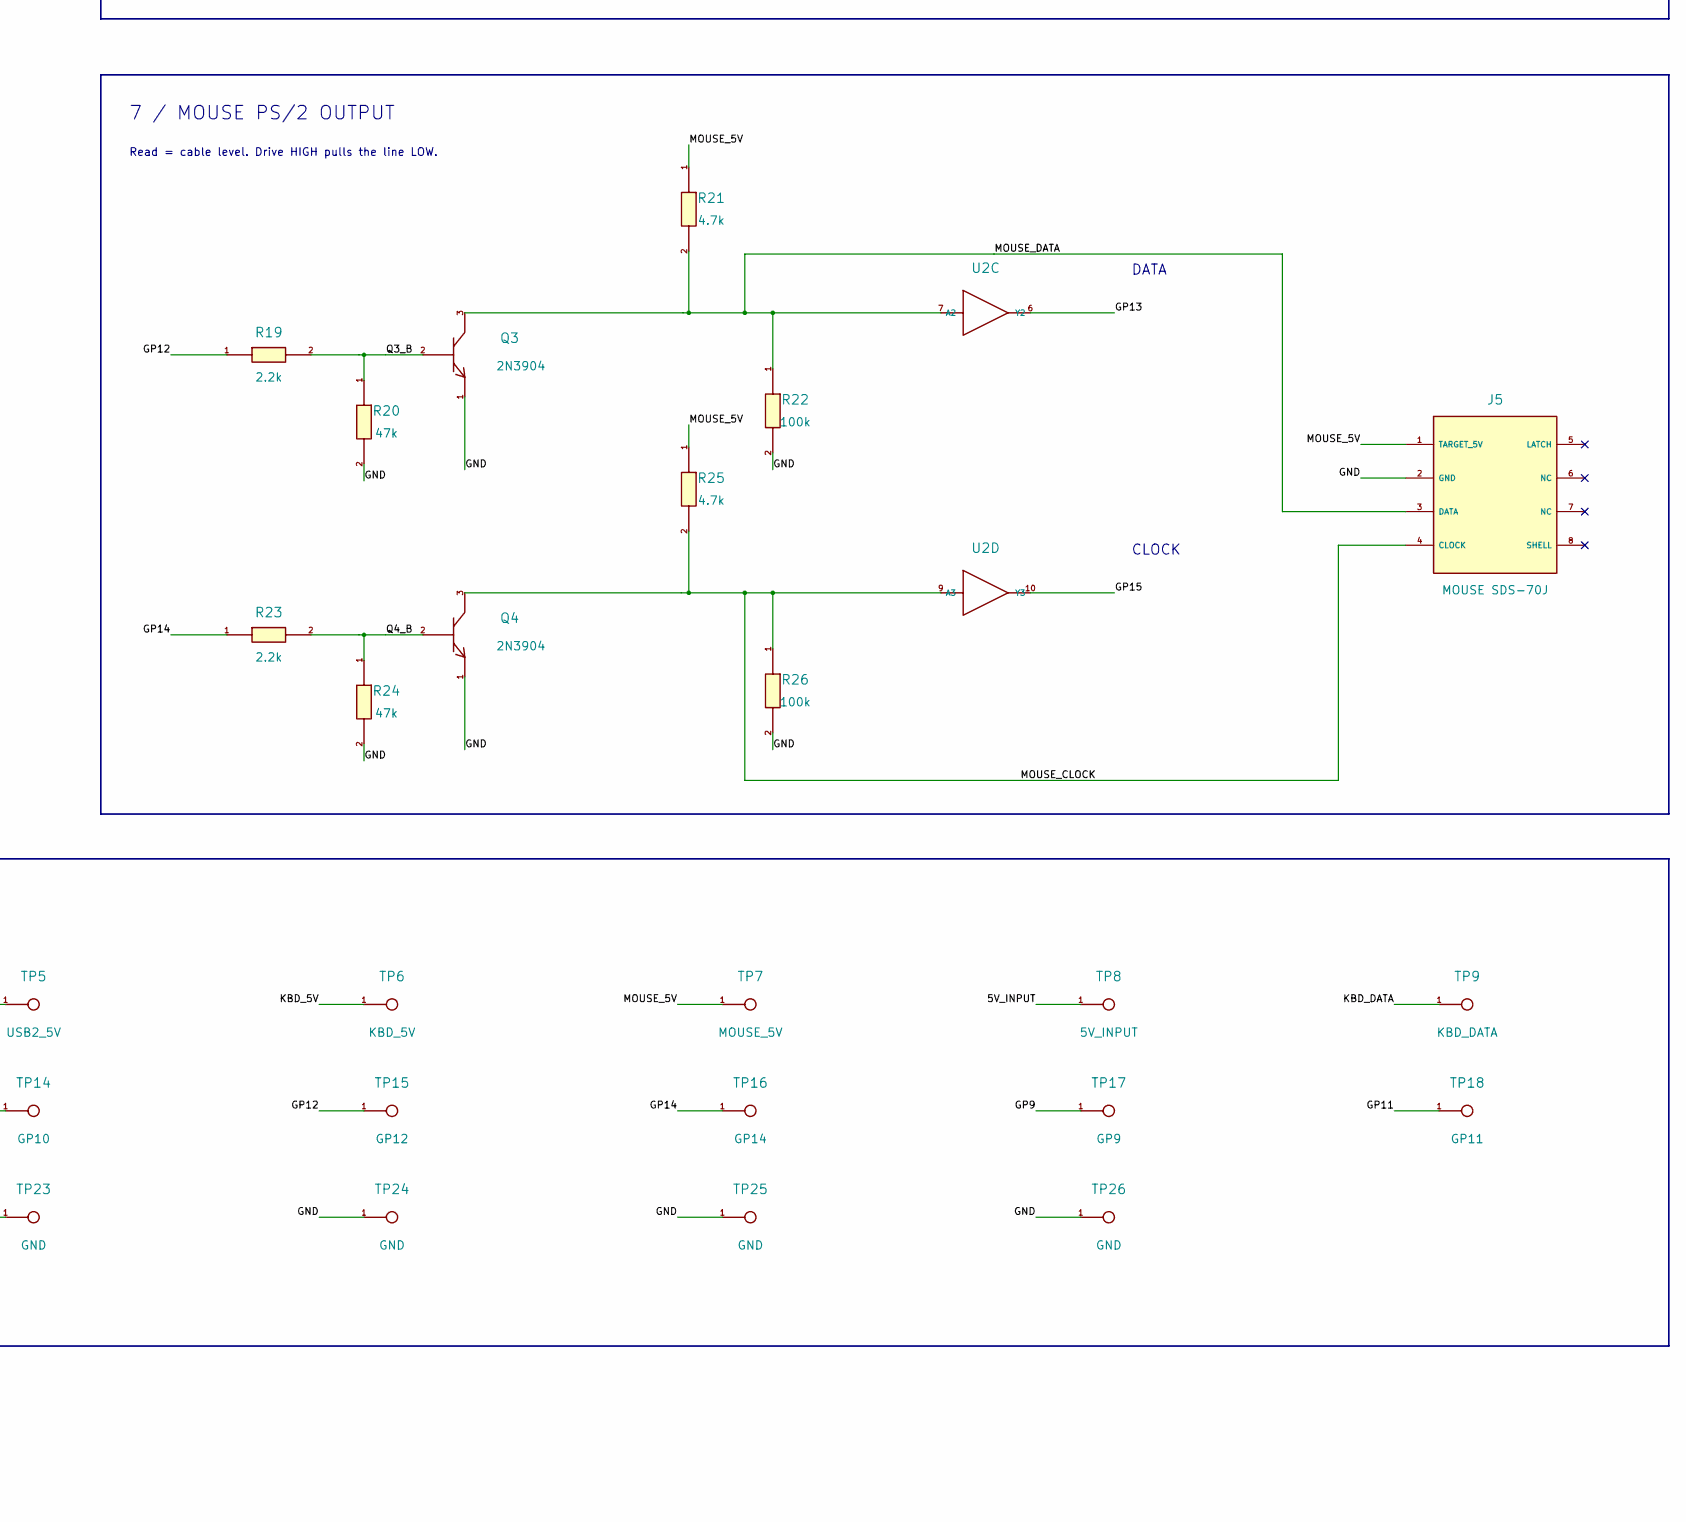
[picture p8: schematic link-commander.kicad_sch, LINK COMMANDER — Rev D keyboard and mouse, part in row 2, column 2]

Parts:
C1: 470uF 10V; CP_Radial_D10.0mm_P5.00mm
C2: 10uF 10V; CP_Radial_D5.0mm_P2.00mm
C3, C4, C6, C8: 100nF; C_Disc_D5.0mm_W2.5mm_P5.00mm
C5, C7: 220uF 10V; CP_Radial_D6.3mm_P2.50mm
D1, D2: RED FAULT; LED_D3.0mm
F1: 1.5A fast 5x20; Fuseholder_Clip-5x20mm_Littelfuse_111_Lateral_P18.80x5.00mm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
J1: 5V INPUT / GND; TerminalBlock_TE_282834-2_1x02_P2.54mm_Horizontal
J2: USB 1; USB_A_Molex_67643_Horizontal
J3: USB 2; USB_A_Molex_67643_Horizontal
J4: KBD SDS-70J; SDS-70J
J5: MOUSE SDS-70J; SDS-70J
JP1: REMOVE FOR PC USB; PinHeader_1x02_P2.54mm_Vertical
M1: RP2040-Zero SOCKETS; RP2040_Zero_HeaderOnly
Q1, Q2, Q3, Q4: 2N3904; TO-92_Inline_Wide
R1, R2, R6, R7: 22R; R_Axial_DIN0207_L6.3mm_D2.5mm_P10.16mm_Horizontal
R3, R4, R8, R9: 15k; R_Axial_DIN0207_L6.3mm_D2.5mm_P10.16mm_Horizontal
R5, R10, R11, R15, R19, R23: 2.2k; R_Axial_DIN0207_L6.3mm_D2.5mm_P10.16mm_Horizontal
R12, R16, R20, R24: 47k; R_Axial_DIN0207_L6.3mm_D2.5mm_P10.16mm_Horizontal
R13, R17, R21, R25: 4.7k; R_Axial_DIN0207_L6.3mm_D2.5mm_P10.16mm_Horizontal
R14, R18, R22, R26: 100k; R_Axial_DIN0207_L6.3mm_D2.5mm_P10.16mm_Horizontal
TP1: 5V_BOARD; TestPoint_THT_1mm
TP2: 5V_MODULE; TestPoint_THT_1mm
TP3: 3V3; TestPoint_THT_1mm
TP4: USB1_5V; TestPoint_THT_1mm
TP5: USB2_5V; TestPoint_THT_1mm
TP6: KBD_5V; TestPoint_THT_1mm
TP7: MOUSE_5V; TestPoint_THT_1mm
TP8: 5V_INPUT; TestPoint_THT_1mm
TP9: KBD_DATA; TestPoint_THT_1mm
TP10: KBD_CLOCK; TestPoint_THT_1mm
TP11: MOUSE_DATA; TestPoint_THT_1mm
TP12: MOUSE_CLOCK; TestPoint_THT_1mm
TP13: GP8; TestPoint_THT_1mm
TP14: GP10; TestPoint_THT_1mm
TP15: GP12; TestPoint_THT_1mm
TP16: GP14; TestPoint_THT_1mm
TP17: GP9; TestPoint_THT_1mm
TP18: GP11; TestPoint_THT_1mm
TP19: GP13; TestPoint_THT_1mm
TP20: GP15; TestPoint_THT_1mm
TP21: USB1_FAULT; TestPoint_THT_1mm
TP22: USB2_FAULT; TestPoint_THT_1mm
TP23, TP24, TP25, TP26: GND; TestPoint_THT_1mm
U1: TPS2042P; DIP-8_W7.62mm_Socket
U2: CD4050BE; DIP-16_W7.62mm_Socket

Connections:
3V3: C2.1, C3.1, M1.21 (3V3), TP3.1, U2.1 (VCC)
5V_BOARD: C1.1, C4.1, F1.2 (OUT), JP1.1 (BOARD), R5.1, R10.1, TP1.1, U1.2 (IN)
5V_INPUT: F1.1 (IN), J1.1 (+5V), TP8.1
5V_MODULE: JP1.2 (MODULE), M1.23 (5V), TP2.1
GND: C1.2, C2.2, C3.2, C4.2, C5.2, C6.2, C7.2, C8.2, J1.2 (GND), J2.4 (GND), J2.5 (SHIELD), J3.4 (GND), J3.5 (SHIELD), J4.2 (GND), J5.2 (GND), M1.22 (GND), Q1.1 (E), Q2.1 (E), Q3.1 (E), Q4.1 (E), R3.2, R4.2, R8.2, R9.2, R12.2, R14.2, R16.2, R18.2, R20.2, R22.2, R24.2, R26.2, TP23.1, TP24.1, TP25.1, TP26.1, U1.1 (GND), U1.3 (/EN1), U1.4 (/EN2), U2.8 (GND), U2.11 (A4), U2.14 (A5)
GP0: M1.1 (GP0), R1.1
GP1: M1.2 (GP1), R2.1
GP2: M1.3 (GP2), R6.1
GP3: M1.4 (GP3), R7.1
GP8: M1.9 (GP8), R11.1, TP13.1
GP9: M1.10 (GP9), TP17.1, U2.2 (Y0)
GP10: M1.11 (GP10), R15.1, TP14.1
GP11: M1.12 (GP11), TP18.1, U2.4 (Y1)
GP12: M1.13 (GP12), R19.1, TP15.1
GP13: M1.14 (GP13), TP19.1, U2.6 (Y2)
GP14: M1.15 (GP14), R23.1, TP16.1
GP15: M1.16 (GP15), TP20.1, U2.10 (Y3)
KBD_5V: J4.1 (TARGET_5V), R13.1, R17.1, TP6.1
KBD_CLOCK: J4.4 (CLOCK), Q2.3 (C), R17.2, R18.1, TP10.1, U2.5 (A1)
KBD_DATA: J4.3 (DATA), Q1.3 (C), R13.2, R14.1, TP9.1, U2.3 (A0)
MOUSE_5V: J5.1 (TARGET_5V), R21.1, R25.1, TP7.1
MOUSE_CLOCK: J5.4 (CLOCK), Q4.3 (C), R25.2, R26.1, TP12.1, U2.9 (A3)
MOUSE_DATA: J5.3 (DATA), Q3.3 (C), R21.2, R22.1, TP11.1, U2.7 (A2)
Q1_B: Q1.2 (B), R11.2, R12.1
Q2_B: Q2.2 (B), R15.2, R16.1
Q3_B: Q3.2 (B), R19.2, R20.1
Q4_B: Q4.2 (B), R23.2, R24.1
USB1_5V: C5.1, C6.1, J2.1 (VBUS), TP4.1, U1.7 (OUT1)
USB1_DM: J2.2 (D-), R2.2, R4.1
USB1_DP: J2.3 (D+), R1.2, R3.1
USB1_FAULT: D1.1 (K), TP21.1, U1.8 (/OC1)
USB1_LED_A: D1.2 (A), R5.2
USB2_5V: C7.1, C8.1, J3.1 (VBUS), TP5.1, U1.6 (OUT2)
USB2_DM: J3.2 (D-), R7.2, R9.1
USB2_DP: J3.3 (D+), R6.2, R8.1
USB2_FAULT: D2.1 (K), TP22.1, U1.5 (/OC2)
USB2_LED_A: D2.2 (A), R10.2

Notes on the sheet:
LINK COMMANDER / REV D / USB KEYBOARD + MOUSE TO PS/2
USB receiver -> RP2040 firmware -> PS/2 lines -> custom DIN cable -> Commander X16
1 / POWER
Regulated 5 V only. Remove JP1 before connecting PC USB.
J1: 5 V / 2 A supply F1: 1.5 A fast fuse USB ports turn on with external power. X16 +5 V is used only for PS/2 pullups.
2 / REMOVABLE RP2040-ZERO
Plug-in module. No wires to underside pads.
GP0/1: USB keyboard D+/D- GP2/3: USB mouse D+/D- GP8-15: PS/2 drive and sense
3 / 3.3 V LOGIC POWER
U2A-F are six buffers inside ONE CD4050BE chip.
Unused inputs go to GND. Unused outputs stay open.
4 / USB KEYBOARD
Use a supported USB device or its own 2.4 GHz USB receiver.
5 / USB MOUSE
Power from U1 pin 6 Fault from U1 pin 5 Both channels are inside U1.
6 / KEYBOARD PS/2 OUTPUT
Read = cable level. Drive HIGH pulls the line LOW.
DATA
CLOCK
7 / MOUSE PS/2 OUTPUT
8 / TEST ACCESS
TP holes are optional probe contacts, not extra required parts. All GND test points are connected.
USB data: probe existing R3.1 / R4.1 (keyboard D+ / D-) or R8.1 / R9.1 (mouse D+ / D-). No added USB stubs.
HOW TO READ: dots join wires; crossing wires without dots do not join. Equal net names are connected.
Q = transistor. R = resistor. C = capacitor. U = chip. TP = test point. M1 numbers are carrier pins; use module GP labels.
Prototype: firmware and bench tests are required before use with the X16. See test-points.md and breadboard.md.

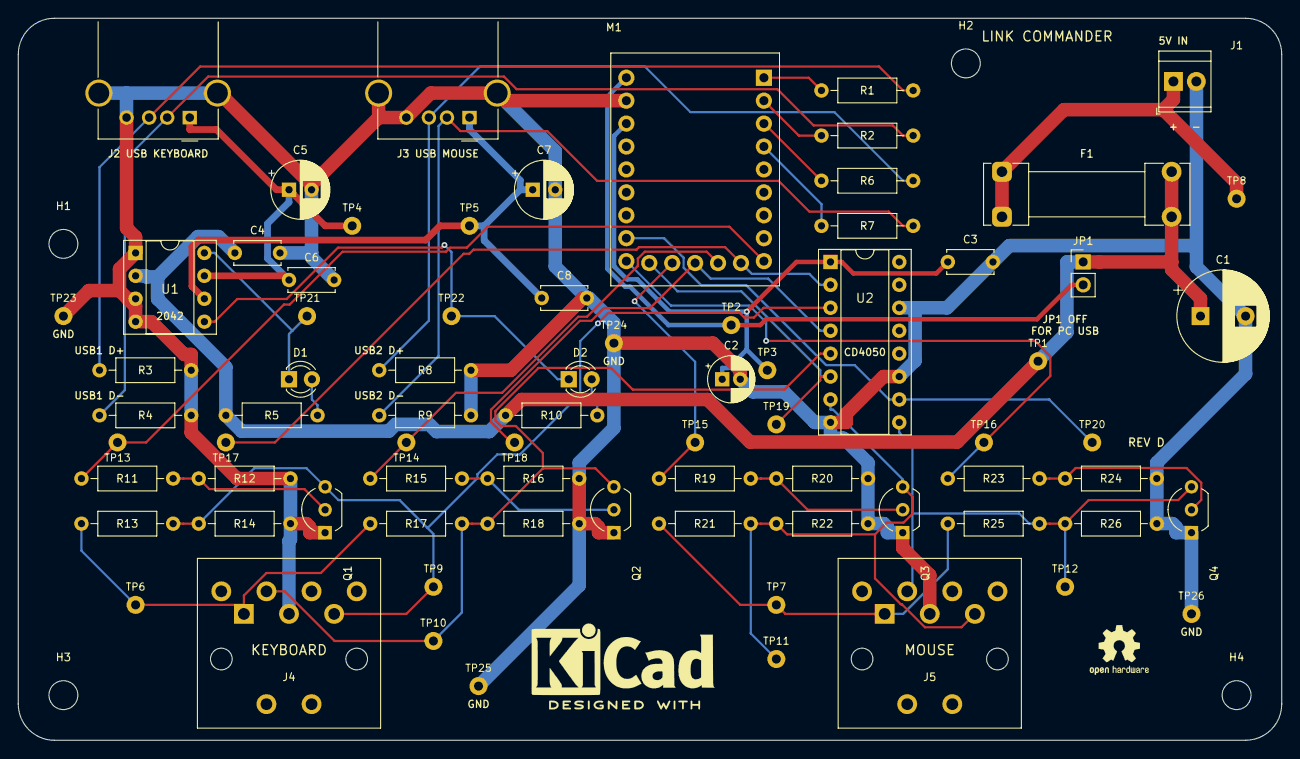
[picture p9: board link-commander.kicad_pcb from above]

Board: 2 copper layers, 140.0 x 80.0 mm, 82 parts (0 on the bottom side), 37 nets.

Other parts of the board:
H1, H2, H3, H4: M3; MountingHole_3.2mm_M3
LOGO1: KiCad-Logo2_8mm_SilkScreen
LOGO2: OSHW-Logo2_7.3x6mm_SilkScreen

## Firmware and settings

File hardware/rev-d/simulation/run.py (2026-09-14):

#!/usr/bin/env python3
"""Bounded PS/2 SPICE study, not a complete adapter or production qualification."""
import argparse,csv,hashlib,io,json,os,re,subprocess,tempfile,urllib.request,zipfile
from pathlib import Path
HERE=Path(__file__).resolve().parent
ROOT=HERE.parent
parser=argparse.ArgumentParser()
parser.add_argument('--ngspice',default='ngspice')
parser.add_argument('--cache',type=Path,default=Path.home()/'.cache/link-commander-simulation')
parser.add_argument('--code-model-dir',type=Path,help='For privately extracted ngspice; ordinary installations load these automatically')
args=parser.parse_args();args.cache.mkdir(parents=True,exist_ok=True)
models=[('2N3904.lib','https://www.onsemi.com/pub/Collateral/2N3904.LIB','5608c109b8d68d57798557991cee506661d031916f589325fad5ed10d82ccbf7',None),('CD4050B.lib','https://www.ti.com/lit/zip/schm018','e8266016c89735465990a1a26fd2811425e1d0e2a17c4db3e6c76f18e7c93712','CD4050B.lib')]
for filename,url,sha,member in models:
 f=args.cache/filename
 if not f.exists():
  blob=urllib.request.urlopen(url,timeout=30).read()
  if member:blob=zipfile.ZipFile(io.BytesIO(blob)).read(member)
  f.write_bytes(blob)
 assert hashlib.sha256(f.read_bytes()).hexdigest()==sha, f'Model changed: review {f} before updating its hash'
# Explicit local adaptations, not the inaccessible TI support attachment:
# 1. Datasheet-confirmed non-inverting function, correcting the published NAND bug.
# 2. Rename VT to avoid ngspice interpreting it as built-in thermal voltage.
s=(args.cache/'CD4050B.lib').read_text()
assert '.PARAM AND  = 0' in s and '.PARAM NAND = 1' in s
s=s.replace('.PARAM AND  = 0','.PARAM AND  = 1').replace('.PARAM NAND = 1','.PARAM NAND = 0')
s=re.sub(r'\bVT\b','LC_INPUT_VT',s)
(args.cache/'CD4050B-local.lib').write_text(s)
parts=json.loads((ROOT/'circuit.json').read_text());by={p['ref']:p for p in parts}
def resistance(ref):
 value=by[ref]['value'];return float(value.replace('k','e3').replace('R',''))
rows=[];first_wave=None
with tempfile.TemporaryDirectory(prefix='link-commander-spice-') as td:
 work=Path(td);init='set ngbehavior=ps\n'
 if args.code_model_dir:
  init+=''.join(f'codemodel {p.resolve()}\n' for p in sorted(args.code_model_dir.glob('*.cm')))
 (work/'.spiceinit').write_text(init)
 def run_netlist(netlist,name):
  (work/'case.cir').write_text(netlist)
  result=subprocess.run([args.ngspice,'-b','case.cir'],cwd=work,text=True,capture_output=True,timeout=60)
  log=result.stdout+'\n'+result.stderr
  if result.returncode or re.search(r'(?im)(error|fatal|timestep too small|.*simulation interrupted)',log):raise RuntimeError(name+'\n'+log[-4000:])
  return {k:float(v) for k,v in re.findall(r'^([a-z][a-z0-9_]*)\s*=\s*([-+\deE.]+)',log,re.M)}
 # Test the local compatibility correction independently of the transistor circuit.
 sanity=f'''CD4050 model function check
.include "{args.cache.resolve()/'CD4050B-local.lib'}"
Vcc vcc 0 3.3
Vin a 0 PULSE(0 5 10u 100n 100n 20u 100u)
Xbuf y a vcc 0 CD4050B
Cl y 0 10p
.control
tran 50n 40u
meas tran lo find v(y) at=5u
meas tran hi find v(y) at=20u
quit
.endc
.end
'''
 m=run_netlist(sanity,'sanity');assert abs(m['lo'])<.1 and m['hi']>3.2
 for channel,(prefix,kind,inp,outp) in enumerate([('KBD','DATA',3,2),('KBD','CLOCK',5,4),('MOUSE','DATA',7,6),('MOUSE','CLOCK',9,10)]):
  q=by[f'Q{channel+1}'];r=11+4*channel;net=f'{prefix}_{kind}'
  assert q['value']=='2N3904' and q['pins']['1'][1]=='GND' and q['pins']['3'][1]==net
  assert by['U2']['pins'][str(inp)][1]==net and by['U2']['pins'][str(outp)][1]==f'GP{9+2*channel}'
  for ref,nets in [(r,{f'GP{8+2*channel}',f'Q{channel+1}_B'}),(r+1,{f'Q{channel+1}_B','GND'}),(r+2,{net,prefix+'_5V'}),(r+3,{net,'GND'})]:assert {p[1] for p in by[f'R{ref}']['pins'].values()}==nets
  rb,rpd,rpu,rline=[resistance(f'R{i}') for i in range(r,r+4)]
  for target,vlogic in [(4.75,3.135),(5.0,3.3),(5.25,3.465)]:
   for capacitance in [100,500,1000]:
    ident=f'{net}_{target}_{capacitance}'
    hi=target*rline/(rline+rpu)
    netlist=f'''Rev D {ident}: nominal resistor values, 25 C. No actual firmware/host model.
.include "{args.cache.resolve()/'2N3904.lib'}"
.include "{args.cache.resolve()/'CD4050B-local.lib'}"
.temp 25
Vtarget target 0 {target}
Vlogic vcc 0 {vlogic}
* GPIO stimulus, 30 ohm assumed source resistance. Not an RP2040 transistor model.
Vdrive stimulus 0 PULSE(0 {vlogic} 10u 100n 100n 20u 100u)
Rgpio stimulus drive 30
Rb drive base {rb}
Rpd base 0 {rpd}
Qpull line base 0 Q2n3904
Rpu target line {rpu}
Rline line 0 {rline}
* Assumed external cable/connector/probe capacitance; CD4050 input capacitance is in its model.
Ccable line 0 {capacitance}p
Xbuf sense line vcc 0 CD4050B
Csense sense 0 10p
* Host is only an ideal low-side switch, 10 ohm on resistance, with no extra host pullup.
Vhost host 0 PULSE(0 3.3 55u 100n 100n 15u 100u)
Shost line 0 host 0 host_switch
.model host_switch SW(Ron=10 Roff=1e12 Vt=1.65 Vh=0)
.control
set wr_singlescale
set wr_vecnames
tran 50n 100u
meas tran idle_line find v(line) at=5u
meas tran driven_line find v(line) at=20u
meas tran host_line find v(line) at=60u
meas tran idle_sense find v(sense) at=5u
meas tran driven_sense find v(sense) at=20u
meas tran host_sense find v(sense) at=60u
meas tran release_10_90 trig v(line) val={.1*hi} rise=1 td=29u targ v(line) val={.9*hi} rise=1 td=29u
meas tran base_drive find v(base) at=20u
wrdata waveform.txt v(stimulus) v(host) v(line) v(sense)
quit
.endc
.end
'''
    m=run_netlist(netlist,ident)
    assert all(k in m for k in ['idle_line','driven_line','host_line','idle_sense','driven_sense','host_sense','release_10_90','base_drive']),ident
    # These are exploratory acceptance levels, not a full PS/2 compliance specification.
    assert m['idle_line']>4 and -.05<m['driven_line']<.4 and -.05<m['host_line']<.4,ident
    assert m['idle_sense']>vlogic-.1 and abs(m['driven_sense'])<.1 and abs(m['host_sense'])<.1,ident
    m['gpio_current_ma']=(vlogic-m['base_drive'])/(rb+30)*1000
    rows.append(dict(channel=net,target_v=target,logic_v=vlogic,external_cap_pf=capacitance,**m))
    if channel==0 and target==5 and capacitance==500:
     first_wave=(work/'waveform.txt').read_text()
     # Portable example for manual use: copy downloaded/local models beside this deck.
     portable=netlist.replace(str(args.cache.resolve())+'/', 'models/')
     (HERE/'ps2-example.cir').write_text(portable)
results={'ngspice':subprocess.check_output([args.ngspice,'--version'],text=True).splitlines()[1].strip(),'cases':rows,'model_sources':[dict(filename=f,url=u,sha256=h) for f,u,h,_ in models],'scope':'Exploratory PS/2 pull-down and nominal buffer model at 25 C. No full-system simulation.','local_cd4050_changes':['AND=1 and NAND=0 to correct known inversion bug','VT renamed LC_INPUT_VT for ngspice compatibility']}
(HERE/'results.json').write_text(json.dumps(results,indent=2)+'\n')
with (HERE/'results.csv').open('w',newline='') as f:
 w=csv.DictWriter(f,fieldnames=list(rows[0]));w.writeheader();w.writerows(rows)
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

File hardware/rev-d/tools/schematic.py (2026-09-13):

"""Single-sheet wired schematic, functional gate units and explicit package pins."""
from pathlib import Path
import json,uuid,math,re
from collections import defaultdict
from design import ROOT,PARTS
CAD=ROOT/'kicad';BY={p['ref']:p for p in PARTS};defs=defaultdict(list);nodes={};items=[];placed=set();used=set();wireids=set();directions={};wirelabels=defaultdict(list);wires=[];labels=set();label_records={};junction_points=set()
def uid(k):return str(uuid.uuid5(uuid.NAMESPACE_URL,'linkcommander/revd/'+k))
def q(s):return json.dumps(str(s),ensure_ascii=False)
def fx(size=1.3,extra=''):return f'(effects (font (size {size} {size})) {extra})'
def text(s,x,y,size=1.7):items.append(f'(text {q(s)} (at {x} {y} 0) {fx(size,"(justify left)")} (uuid {uid("text"+s+str(x)+str(y))}))')
def line(a,b,graphic=False):
 if a==b:return
 k=str(a)+str(b)+str(graphic)
 if k in wireids:return
 wireids.add(k)
 if not graphic:
  wires.append((a,b));return
 tag='polyline'
 items.append(f'({tag} (pts (xy {a[0]} {a[1]}) (xy {b[0]} {b[1]})) (stroke (width {0.3 if graphic else 0}) (type default))'+(' (fill (type none))' if graphic else '')+f' (uuid {uid(k)}))')
def section(title,x,y,w,h,note=''):
 for a,b in [((x,y),(x+w,y)),((x+w,y),(x+w,y+h)),((x+w,y+h),(x,y+h)),((x,y+h),(x,y))]:line(a,b,True)
 text(title,x+5,y+7,2.4)
 if note:text(note,x+5,y+14,1.4)
def label(net,xy,angle=0):
 if (net,xy) in labels:return
 labels.add((net,xy))
 label_records[(net,xy)]=f'(label {q(net)} (at {xy[0]} {xy[1]} {angle}) {fx(1.25,"(justify right bottom)" if angle==180 else "(justify left bottom)")} (uuid {uid("label"+net+str(xy))}))'
def key(ref,pin):return (ref,str(pin))
def W(a,b,*via):
 if isinstance(a,tuple) and isinstance(a[0],str):
  used.add(a);net=BY[a[0]]['pins'][a[1]][1];aa=nodes[a]
 else:aa=a;net=None
 if isinstance(b,tuple) and isinstance(b[0],str):
  used.add(b);bb=nodes[b];nb=BY[b[0]]['pins'][b[1]][1]
  if net:assert net==nb,(a,b,net,nb)
  net=nb
 else:bb=b
 for x,z in zip([aa,*via,bb],[*via,bb]):line(x,z)
 if net:
  seg=[(abs(end[0]-start[0]),min(start[0],end[0]),start[1]) for start,end in zip([aa,*via,bb],[*via,bb]) if start[1]==end[1]]
  if seg:
   length,xx,yy=max(seg);label(net,(round(xx+max(0,(length-len(net)*.7)/2),4),yy))
  else:label(net,aa)

def L(ref,pin,dx=-10,dy=0):
 a=key(ref,pin);used.add(a);pt=nodes[a];net=BY[ref]['pins'][str(pin)][1]
 if net is None:items.append(f'(no_connect (at {pt[0]} {pt[1]}) (uuid {uid("nc"+str(a))}))');return
 end=(pt[0]+dx,pt[1]+dy);line(pt,end);label(net,end,180 if dx<0 else 0)
def stroke():return '(stroke (width 0.25) (type default))'
def poly(pts):return '(polyline (pts '+''.join(f'(xy {x} {-y}) ' for x,y in pts)+') '+stroke()+' (fill (type none)))'
def rect(x0,y0,x1,y1):return f'(rectangle (start {x0} {-y0}) (end {x1} {-y1}) {stroke()} (fill (type background)))'
def circle(x,y,r):return f'(circle (center {x} {-y}) (radius {r}) {stroke()} (fill (type none)))'
def place(ref,x,y,kind='box',left=None,right=None,unit=1,rot=0,pitch=4,width=30,pins=None,caption=None):
 p=BY[ref];shape='';loc={}
 if kind=='TP':
  loc={'1':(-5,0,0)};shape=circle(0,0,1)+poly([(-5,0),(-1,0)]);h=4
 elif kind in ('R','C','D','F','JP'):
  loc={'1':(-7.5,0,0),'2':(7.5,0,180)}
  if kind in ['R','F','JP']:shape=rect(-3,-1.3,3,1.3)+poly([(-7.5,0),(-3,0)])+poly([(3,0),(7.5,0)])
  elif kind=='C':shape=poly([(-.7,-3),(-.7,3)])+poly([(.7,-3),(.7,3)])+poly([(-7.5,0),(-.7,0)])+poly([(.7,0),(7.5,0)])
  else:shape=poly([(-2,-2),(-2,2)])+poly([(-2,0),(2,-2),(2,2),(-2,0)])+poly([(-7.5,0),(-2,0)])+poly([(2,0),(7.5,0)])+poly([(0,-3),(2,-5),(1,-5)])+poly([(3,-3),(5,-5),(4,-5)])
  if kind=='C' and 'uF' in p['value']:shape+=f'(text "+" (at -3 4 0) {fx(1.3)})'
  h=5
 elif kind=='Q':
  loc={'1':(0,7.5,90),'2':(-7.5,0,0),'3':(0,-7.5,270)}
  shape=poly([(-7.5,0),(-2,0)])+poly([(-2,-3),(-2,3)])+poly([(-2,-1.5),(0,-4),(0,-7.5)])+poly([(-2,1.5),(0,4),(0,7.5)])+poly([(-.2,2.3),(0,4),(-1.6,3.5)]);h=9
 elif kind in ['buffer','inv','and']:
  if kind=='and':
   a,b,c=pins;loc={str(a):(-8,-2.5,0),str(b):(-8,2.5,0),str(c):(8,0,180)}
   shape=rect(-4,-5,4,5)+f'(text "&" (at 0 0 0) {fx(2.5)})'+poly([(-8,-2.5),(-4,-2.5)])+poly([(-8,2.5),(-4,2.5)])+poly([(4,0),(8,0)])
  else:
   a,b=pins;loc={str(a):(-8,0,0),str(b):(8,0,180)}
   shape=poly([(-4,-4),(-4,4),(4,0),(-4,-4)])+poly([(-8,0),(-4,0)])+poly([(5.5 if kind=='inv' else 4,0),(8,0)])
   if kind=='inv':shape+=circle(4.7,0,.75)+poly([(-2,1),(-1,1),(-1,-1),(1,-1)])
  h=10
 else:
  left=left or [];right=right or [];h=max(len(left),len(right))*pitch+4;shape=rect(-width/2,-h/2,width/2,h/2)
  for side,seq in [(-1,left),(1,right)]:
   for i,n in enumerate(seq):loc[str(n)]=(side*(width/2+5),(i-(len(seq)-1)/2)*pitch,0 if side==-1 else 180)
  if ref.startswith('RN'):
   ys=[loc[str(n)][1] for n in range(2,10)]
   shape+=poly([(-width/2,0),(-8,0)])+poly([(-8,min(ys)),(-8,max(ys))])
   for yy in ys:shape+=poly([(-8,yy),(-4,yy)])+rect(-4,yy-.7,4,yy+.7)+poly([(4,yy),(width/2,yy)])
  # Label the body function instead of depending on cryptic part markings.
  if caption:shape+=f'(text {q(caption)} (at 0 0 0) {fx(1.2)})'
 def rotate(xx,yy):
  r=math.radians(rot);return (round(x+xx*math.cos(r)-yy*math.sin(r),4),round(y+xx*math.sin(r)+yy*math.cos(r),4))
 libpins=''
 for n,(xx,yy,ang) in loc.items():
  assert n in p['pins'],(ref,n)
  nm,net=p['pins'][n];length=5 if kind=='box' else 0
  libpins+=f'(pin passive line (at {xx} {-yy} {ang}) (length {length}) (name {q(nm)} {fx(1)}) (number {q(n)} {fx(1)}))'
  nodes[key(ref,n)]=rotate(xx,yy);directions[key(ref,n)]=-1 if xx<0 else 1
 defs[ref].append(f'(symbol "LC_{ref}_{unit}_1" {shape} {libpins})')
 sid=uid(ref+str(unit));display=ref+(chr(64+unit) if ref=='U2' else '')
 showval=p['value'];hidevalue=ref=='U2' and unit!=7
 if kind in ['R','C','D','F','JP']:
  tx,ty=(x,y-4) if rot==0 else(x+4,y-2);vx,vy=(x,y+4) if rot==0 else(x+4,y+2)
 elif kind=='Q':tx,ty=x+8,y-3;vx,vy=x+10,y+2
 else:tx,ty=x,y-h/2-3;vx,vy=x,y+h/2+3
 items.append(f'(symbol (lib_id "LC_{ref}") (at {x} {y} {-rot}) (unit {unit}) (in_bom yes) (on_board yes) (dnp no) (uuid {sid}) '+
 f'(property "Reference" {q(ref)} (at {tx} {ty} {rot}) {fx(1.7)}) '+
 f'(property "Value" {q(showval)} (at {vx} {vy} {rot}) {fx(1.5,"hide" if hidevalue else "")}) '+
 f'(property "Footprint" {q(p["footprint"])} (at {x} {y} 0) {fx(1,"hide")}) '+
 ''.join(f'(pin "{n}" (uuid {uid(ref+str(unit)+"pin"+n)}))' for n in loc)+
 f'(instances (project "link-commander" (path "/{uid("root")}" (reference "{ref}") (unit {unit})))))')
 placed.add(ref)
 return {n:nodes[key(ref,n)] for n in loc}
def R(ref,x,y,vertical=False):return place(ref,x,y,ref[0] if not ref.startswith('JP') else 'JP',rot=90 if vertical else 0)
def gate(ref,unit,x,y,kind,pins):place(ref,x,y,kind,unit=unit,pins=pins)
text('LINK COMMANDER / REV D / USB KEYBOARD + MOUSE TO PS/2',15,18,3.8)
text('USB receiver -> RP2040 firmware -> PS/2 lines -> custom DIN cable -> Commander X16',15,29,2)
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

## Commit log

2026-09-13 Simplify Rev D to a two-chip keyboard and mouse bridge
    [bom-grouped.csv, bom.csv, breadboard-wiring.csv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]
2026-09-13 Add through-hole test access and student probe guide to Rev D
    [bom-grouped.csv, bom.csv, breadboard-wiring.csv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]
2026-09-14 Document exploratory Rev D PS2 simulation and model limitations
    [results.csv]
2026-09-14 Add root breadboard instructions with staged parts and wiring attachments
    [BREADBOARD-PARTS.csv, BREADBOARD-WIRING.csv]
2026-09-17 Replace shopping searches with direct products and exact order SKUs
    [SHOPPING-MOUSER-KEYBOARD.csv, SHOPPING-MOUSER-ORDER.csv]
2026-09-18 Make store shopping lists cover the complete Rev D breadboard
    [SHOPPING-AMAZON-ORDER.csv, SHOPPING-MOUSER-KEYBOARD.csv, SHOPPING-MOUSER-ORDER.csv]
2026-09-19 Add Mouser will-call PO drafts for five Rev D PCB builds
    [MOUSER-PO-01-FIVE-PCBS.csv, MOUSER-PO-02-CHIPS-ONLY.csv]
2026-09-19 Simplify Mouser documents to supplier parts tables
    [MOUSER-PO-01-FIVE-PCBS.csv, MOUSER-PO-02-CHIPS-ONLY.csv]
